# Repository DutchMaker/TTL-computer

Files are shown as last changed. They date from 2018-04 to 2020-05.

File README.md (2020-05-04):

# 74xx Computer

My attempt at building a computer from scratch with 74xxx logic chips.  

## Project Shelved!

I have abandoned this project, but only to reboot it with a different approach.  
Make sure to check **[The DM-02 Computer](https://github.com/DutchMaker/DM-02)** which is my second attempt at a computer from scratch!

## Status as of September 4th, 2019:

[**General architecture**](https://github.com/DutchMaker/TTL-computer/blob/master/Documentation/Architecture.pdf) has been worked out as high level schematic.  

Worked on **instruction set, micro code, module documentation & general notes** from time to time (see: [Documentation](https://github.com/DutchMaker/TTL-computer/tree/master/Documentation)). Only thing missing right now is some documentation on each of the modules. 

The entire computer has been built in [**Logisim**](https://github.com/DutchMaker/TTL-computer/tree/master/Documentation/Logisim) to verify that the way I had everything in mind is actually going to work.

I've built a [**microcode compiler**](https://github.com/DutchMaker/TTL-computer/tree/master/Code/Microcode) for the Controller's ROM image. This takes a source file which defines all the microcode and compiles it into a binary image that is loaded into the microcode ROM.

The 74xx Computer's **instruction set** has been implemented, its **[assembly language](https://github.com/DutchMaker/TTL-computer/blob/master/Documentation/74xx-Assembly-Language.md)** is fully documented and I've built an [**assembler**](https://github.com/DutchMaker/TTL-computer/tree/master/Code/Assembler) to convert assembly programs to machine code.

[**Circuit diagrams and PCBs**](https://github.com/DutchMaker/TTL-computer/tree/master/Circuits) have all been designed in KiCad and have been or are currently being produced:

- [x] Clock (*built and tested*)
- [x] Registers (*built and tested*)
- [x] ALU (*built and tested*)
- [x] Program Counter (*built and tested*)
- [x] Stack Pointer (*built and tested*)
- [x] Flags register (*built and tested*)
- [x] Memory (*built and tested*)
- [x] Memory Access Register (*built and tested*)
- [ ] Controller (*redesigned circuit to account for reset ciruitry - waiting for PCB production*)
- [x] Main Board ( *built and tested*)

## TODO's / Plans:

- Build the computer in real life (**IN PROGRESS**)
  - First revision is based on separate PCBs that are all connected together by one large main PCB.
  - If all works out, there may be a second revision will be one large PCB that contains all modules as one circuit.
- Write additional/updated documentation on all modules.

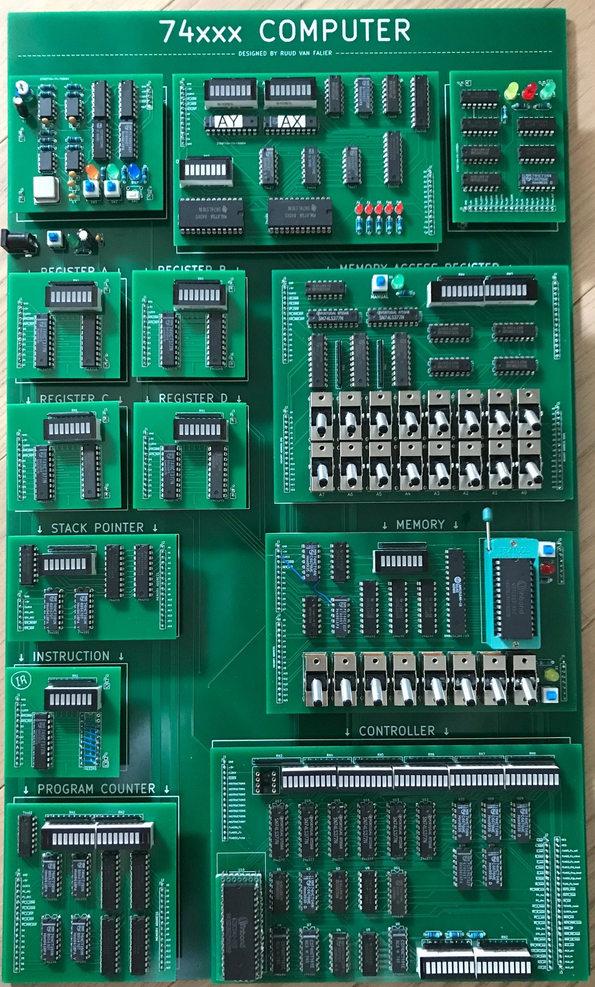
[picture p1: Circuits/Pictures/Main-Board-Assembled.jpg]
Assembled computer


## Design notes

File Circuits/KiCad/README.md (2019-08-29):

# KiCad projects

- Add `./Libraries/74xx-Computer-Symbols.lib` as global Symbol library to KiCad (Eeschema)
- Add `./Libraries` as global Footprint library to KiCad (Pcbnew)
- PCBs are initially autorouted using `./Libraries/freeRouting.jar` and traces are enhanced manually

### Known deviations/errors in current Schematic/PCB files

There are a number of deviations and errors that were found in schematic/PCB designs after PCB production. They are listed here if they were not fixed in the schematic/PCB design files.

- **ALU:** LED bar graph for AX (_BAR1_) and AY (_BAR2_) have swapped places on the PCB.
- **ALU:** Cn input needs to be inverted.
- This is added to the main board because ALU PCB was already produced and there were no available NOT gates available.
- **ALU:** Outer margin varies from other boards.
- **Flags Register:** U6 and U7 (74x74) ~PRE pins (4 and 10) are floating. They must be tied to +5V otherwise the chip does not function properly.
- **Memory & Memory Access Register:** The switches used for SW1 to SW8 briefly short out the circuit while switching. This reset the entire computer. Solved this by removing the connection to ground and adding 10k pull-down resistors between the data lines and ground.
- **Memory:** RAM should write when clock pulse is high. Otherwise manual input is difficult because that relies on single stepping the clock. Solved this by feeding the clock signal through U1 (74x04) before connecting it to U4A (74x32).
- **Main Board:** Current main board PCB design does not fit the current instruction register PCB - only the improvised one that I've built.
- **Controller:** U9 (74x74) ground pin is not connected. Also ~PRE pin (4) is floating and must be tied to +5V.
- **Controller & Memory**: Drill holes for ZIF socket are too narrow (need to be 1mm).
- **Main Board:** Forgot to add LED bar to display data bus contents.
- **Main Board:** Forgot to add one or more expansion ports.
- **Main Board:** Need pull-down resistors on the data bus
- **Controller**: There is an issue with powering up the controller: its initial state has all control lines enabled. This messes up the state of other modules.
  - Needs pull-down/up resistors on control lines for initial state of modules (reset state) - this is improvised on the main board now. We also must have a boot/reset procedure, something like: 
    - First all control line output is high impedance (this resets all modules because of the pull-down/up resistors that determine initial state). Will probably do this by cutting power to the controller during boot.
    - Then the controller is powered up and it needs to load microcode address 0
    - Then it can start processing instructions

### Suggested improvements

- Clock: Use a bigger push switch for single stepping
  - Add a *continue* option in order to continue execution after a HALT instruction.
- When all modules are built and tested, combine them into a single PCB.
  - I may decide to never do this and just start designing the next version of the CPU.
- Add decoupling caps (have only been added to main board now)
- Improve silk screen documentation
- Databus LEDs missing on Main Board
- Add hex decoders to registers / memory.
  - Add switch to disable output?
- ADC and SUBC instructions should take the carry flag into account
  - SUBC may be renamed to SUBB (borrow)

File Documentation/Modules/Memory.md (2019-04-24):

# Memory

_Work in progress..._

ROM/RAM	
Toggle switch to boot from ROM	
	$0000-$3FFF = ROM (16 kB)
	$4000-$FFFF = RAM (48 kB)
	
Switch ROM off	
	$0000-$FFFF = RAM (64 kB)
	
Stack	
	$FF00-$FFFF
	
If ROM boot is enabled:	
	Address bit 14 && 15 == 0 then use ROM
	Else use RAM

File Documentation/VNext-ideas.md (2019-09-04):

# Ideas for the next CPU to build:

- Improve microcode efficiency
- Replace 74x181 ALU with EPROM-based ALU (see: <https://github.com/DoctorWkt/CSCvon8/blob/master/Docs/CSCvon8_design.md>)
- Split clock cycle in 2 phases, one where output to bus starts, second where loading from the bus starts.
- Compatibility with 8085 architecture; opens the door to conversion from 8085 assembly to vNext assembly and even re-use of 8085 C compilers
- Maybe add 16-bit register and operations? or at least a transfer register (takes 16-bit and splits it into 8-bit)
- Support for interrupts
- Be able to peek at register contents with hexadecimal feedback
- Add CPU flags for sign/negative, parity, overflow
  - Store flags in 8-bit register
  - Allows bit (ALU) operations on flags
- One MOV instruction for all data transfer operations (add addressing modes so MOV can replace MVI, LDA, STA, LDA, etc)
- Store accumulator and flags register before a CALL instruction and restore it after RET instruction

## Improve microcode efficiency and allow for more flags

Current CPU uses 19 address lines for the microcode ROM and stores state of 48 control lines in 6 separate bytes.
Ideas for improvement:

- Use rom with 16 address lines and 16 bit words (M27C1024)
- Fit all control lines in one word (or 2?)
- First 2 t-states are hardwired and excluded from t-state bits. So we can have 16 t-state with 4-bits PLUS the 2 t-state required for the fetch cycle = 18 t-state max
- Encode control lines into that word
- Decode the control word in the CPU's controller
- OUT/IN will use memory address instead of register operation (= no control lines required)
- No flags in microcode, instead use hardwired logic connected to an 8-bit flags register
- Microcode rom addr will be `[instruction(8)][t-state(4)]` = 12-bit address

### Decrease word size (encode the control lines)

Operation type (2 bits)

- Data operation `00`
  - Word format: `[00][operand (4)][datafunction (1)][operand (4)][datafunction (1)][alufunctions (4)]` = 16 bits
- ALU `01`
  - 
- Other `10`
  - Word format: `[01]`

Data operands (4 bits per operand, 2 operands in one microcode instruction = 8 bits):

- None `0000`
- A `0001`
- B `0010`
- H (was D) `0011`
- L (was C) `0100`
- ALU `0101`
- Flags (treat as regular register - set/clear flag instructions use ALU operations) `0110`
- IR `0111`
- MAR_H `1000`
- MAR_L `1001`
- MEM `1010`
- PC_H `1011`
- PC_L `1100`
- STACK_H `1101`
- STACK_L `1110`
- (add 1 more GPR?)

Data functions (1 bit per operand, 2 per instruction = 2 bits):

- load `0`
- out `1`

ALU functions

- ALU_f0
- ALU_f1
- ALU_f2
- ALU_f3

Other functions (may take up to 6 bits):

- TSTATE_reset
- CLOCK_halt
- MAR_zp
- STK_inc
- STK_dec
- PC_inc
- PC_dec

Example control word:

- Memory out, A register load = `[operation][MEM][out][A][load]` = `[00][1001][1][0010][0]`

Important changes compared to v1:

- Flags are in one normal register
- Set/clear flag instructions is done with ALU operations
- ALU uses custom/simplified function table (4 bits)

### Flags

- Make it easy to identify flag operations in op-code
- eg. end opocode with flag bits
- 3 bits, allows for 5 flags (0 = no flag operation)
- 1 = Zero
			- 2 = Carry
		- 3 = Negative
		- 4 = Compare
		- 5 = Whatever
	
	- JN (jump in negative)	= `[10101][011]`	
		- 011 needs to be decoded to 00100
		- Execute instruction `[10101]` (= JMP) when decoded bit 3 == 1
		- Use one more bit (last) in instruction to identify if condition can be applied
		- Example `[10101]` = condition can be applied, `[10100]` is not
			So `[10100111]` is an unconditional 8 bit instruction while `[11001001]` is conditional and requires zero=1 to run

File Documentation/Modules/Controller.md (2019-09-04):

# Controller

This module is responsible for counting T-states and decoding instructions to the control lines.
It's the most complicated part of this computer as it requires several states to be tracked in order to perform its tasks.

The controller logic is based on microcode that is stored in a ROM.

## Module subsystems:

### Power-up

When the module is powered up, all the reset lines on the 8-bit registers (74273) are pulled low (active) in order to reset the registers. At the same time a 4 bit counter (74161) starts counting and when it reached `0010` the register reset lines are pulled up so the registers are enabled and the rest of the module's subsystems are enabled.

This prevents the control lines from outputting random states during power-up.

All control lines have pull-up/down resistors connected to them. They determine the default state of each of the control lines. They are set up in such way that all the modules that load data from the bus (Registers, Program Counter, MAR, etc.) have their `load` line enabled so they are loading empty data (the data bus is pulled low) during power-up.

### T-state counter
State machine that keeps track of instruction T-states. Instructions can have a maximum of 16 T-states so we use a 4 bit binary counter (74161).

### _Data byte_ counter
Instructions are translated to a maximum of 48 control lines and the state of these lines are stored in the control ROM. Because the ROM stores one byte (8 bits) per address, we need to read a byte from 6 sequential addresses to come up with the 48 bit word for the control lines.
The _data byte counter_ (74161 binary counter) result is used during composition of the current ROM memory address. We are using only 3 bits of this counter for this purpose.

### Registers

The 48 bit control word is stored in 8-bit registers (74273). The data byte counter determines which of the registers is used to store the current data byte. Register selection is done using a  3-to-1 multiplexer (74138). When transfer is complete, we have all the control bits ready to be used.

### Internal clock

The module has an internal clock running at relatively high speed used for the ROM bank and Load state counter and the shift registers. The Logisim circuit uses an internal clock at 8x the speed of the regular clock.

## Module inner workings

Let's take a look at the tasks that this module is performing:

1. Halt CPU execution.
2. Construct ROM memory address for bank 1 (see _Memory layout_).
3. Load ROM byte into current register.
4. Increase data byte counter.
5. Repeat from step 2 until bank 6 has been processed (6x8 control word bytes).
6. Resume CPU execution.

## Memory layout

### Memory addresses

The microcode (control line states) for each instruction is stored in 6 bytes in ROM.
The memory address at which this is stored is constructed using the following variables:

- Bank number (i.e. byte number, one bank for each of the 6 bytes).
  *3 bits*
- CPU flags state.
  *3 bits*
- Instruction OP-code.
  *8 bits*
- Instruction T-state.
  *5 bits*

This leads to an 19 bit address which is exactly what is supported by the 29C040 ROM we are using. 

The final memory address is laid out as such:

`[flags][instruction][t-state][bank]`
`[000][00000000][00000][000]`

Flags are ordered as such:

| Bit 2  | Bit 1 | Bit 0 |
| --- | ----- | ----- |
| `Fcmp` | `Fz`  | `Fc`  |

### Data layout

| | Bit 7 | Bit 6 | Bit 5 | Bit 4 | Bit 3 | Bit 2 | Bit 1 | Bit 0 |
| --- | --- | --- | --- | --- | --- | --- | --- | --- |
| **Bank 0** | | | `MAR_ZP` | `FLAGS_Fc_set` | `FLAGS_Fc_clear` | `FLAGS_Fc_load` | `FLAGS_Flt_load` | `FLAGS_Feq_load` |
| **Bank 1** | `FLAGS_Fgt_load` | `OUT2_in` | `OUT1_in` | `IN_out` | `TSTATE_reset` | `CLOCK_halt` | `MEM_out` | `MEM_RAM_load` |
| **Bank 2** | `MAR_STK_load` | `MAR_PC_load` | `MAR_HB_load` | `MAR_LB_load`  | `ALU_out` | `ALU_cn` | `ALU_m` | `ALU_s3` |
| **Bank 3** | `ALU_s2` | `ALU_s1` | `ALU_s0` | `ALU_B_in` | `ALU_A_in` | `STK_reset` | `STK_dec` | `STK_inc` |
| **Bank 4** | `PC_HB_out` | `PC_LB_out` | `PC_HB_load`  | `PC_LB_load` | `PC_dec` | `PC_inc` | `IR_load` | `FLAGS_load` |
| **Bank 5** | `D_load` | `D_out` | `C_load` | `C_out` | `B_load` | `B_out` | `A_load` | `A_out` |

## Microcode

The microcode compiler is used to define the contents of the microcode ROM.
*More documentation on this will follow...*

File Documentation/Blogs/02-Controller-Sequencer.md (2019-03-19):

# Sequencer / Instruction Decoder

This module is responsible for translating the current instruction to the control lines.
It's the most complicated part of this computer as it requires several states to be tracked in order to perform its tasks.

## Module subsystems:

### T-state counter
State machine that keeps track of instruction T-states. Instructions can have a maximum of 16 T-states so we use a 4 bit binary counter (74161).

### ROM bank counter
Instructions are translated to a maximum of 48 control lines and the state of these lines are stored in the control ROM. Because the ROM stores 8 bits per address, we need to read from 6 sequential addresses to come up with the 48 bit word for the control lines.
The _ROM bank counter_ (74161 binary counter) result is used during composition of the current ROM memory address. We are using only 3 of the counter bits for this purpose.

### Shift registers

The 48 bit control word is stored in serial-in/parallel-out (SIPO) 6 shift registers (74595). To transfer the bits from the ROM to the SIPO shift registers, we use one parallel-in/serial-out (PISO) shift register (74165).

When transfer is complete, we have all the control bits ready to be used and visualized.

### Load state counter

In order to load bits from ROM into the PISO/SIPO shift registers we need to keep track of a load state; after 8 bits are loaded, the ROM bank counter needs to advance and the next 8 bits must be loaded.

### Internal clock

The module has an internal clock running at relatively high speed (something like 8 MHz)  used for the ROM bank counter, SR loading state and the shift registers.

## Module inner workings

Let's take a look at the tasks that this module is performing:

1. Halt CPU execution.
2. Construct ROM memory address for bank 1 (see _Memory layout_).
3. Load ROM byte into PISO shift register.
4. Load PISO data into SIPO shift register.
5. Increase bank counter.
6. Repeat from step 2 until bank 6 has been processed (6x8 control word bytes).
7. Resume CPU execution.

## Memory layout

### Memory addresses

The microcode (control line states) for each instruction is stored in 6 bytes in ROM.
The memory address at which this is stored is constructed using the following variables:

- Bank number (i.e. byte number, one bank for each of the 6 bytes).
  *3 bits*
- CPU flags state.
  *5 bits*
- Instruction OP-code.
  *6 bits*
- Instruction T-state.
  *4 bits*

This leads to an 18 bit address. The ROM we are using (29C040) supports 19 bit addresses, so the last bit remains unused. 

The final memory address is laid out as such:

`[unused][flags][instruction][t-state][bank]`
`[0][00000][000000][0000][000]`

### Data layout

| | **Bit 7** | **Bit 6** | **Bit 5** | **Bit 4** | **Bit 3** | **Bit 2**  | **Bit 1**  | **Bit 0** |
| --- | --- | --- | --- | --- | --- | --- | --- | --- |
| **Bank 0** | `CLK_hlt` | `C_in` | `C_out` | `C_PC-in` | `D_in` | `D_out` | `D_PC-in`  | `A_in` |
| **Bank 1** | `A_out` | `B_in` | `B_out` | `IO_in` | `RAM_in`  | `MEM_out`  | `IN_out` | `OUT1_in` |
| **Bank 2** | `OUT2_in` | `PC_dec`  | `PC_inc`  | `PC_C-in` | `PC_D-in` | `MAR_C-in` | `MAR_D-in` | `MAR_PC-in` |
| **Bank 3** | `MAR_STK-in` | `ALU_in`  | `ALU_out` | `ALU_S0`  | `ALU_S1`  | `ALU_S2` | `ALU_S3` | `ALU_M` |
| **Bank 4** | `ALU_Cn` | `F_in` | `F_z` | `F_c` | `F_eq` | `F_lt` | `F_gt` | `SEQ_res` |
| **Bank 5** | | | | | | | `STK_dec`  | `STK_inc` |

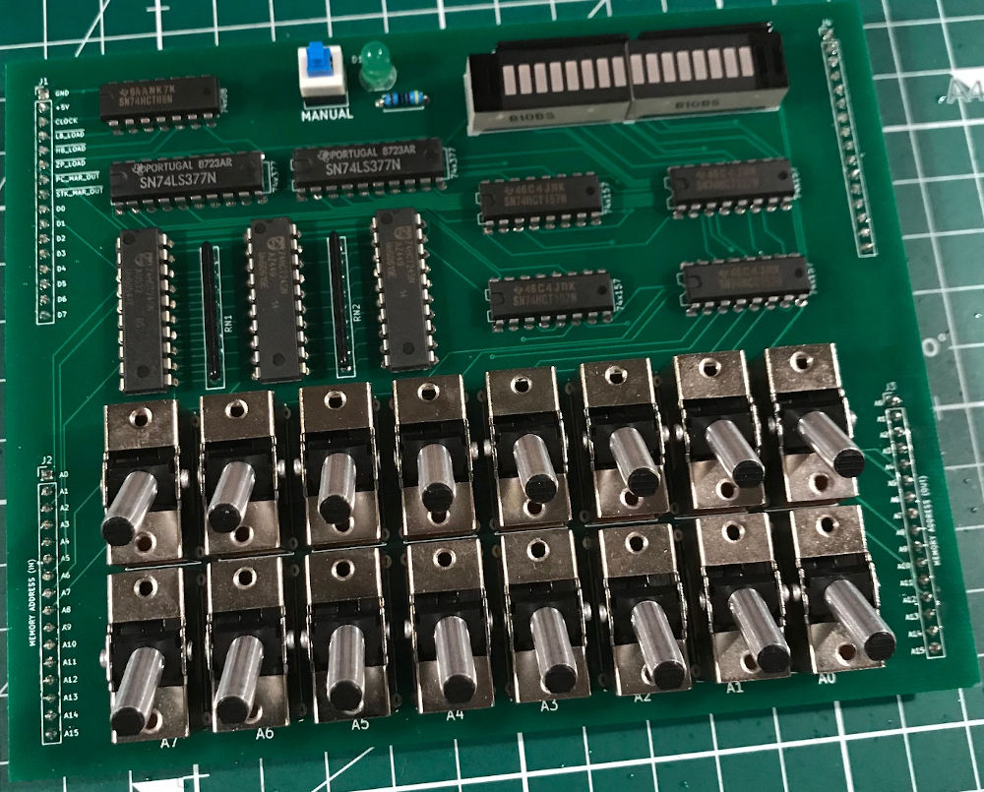
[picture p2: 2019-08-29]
Circuits/Pictures/Memory-Access-Register.jpg

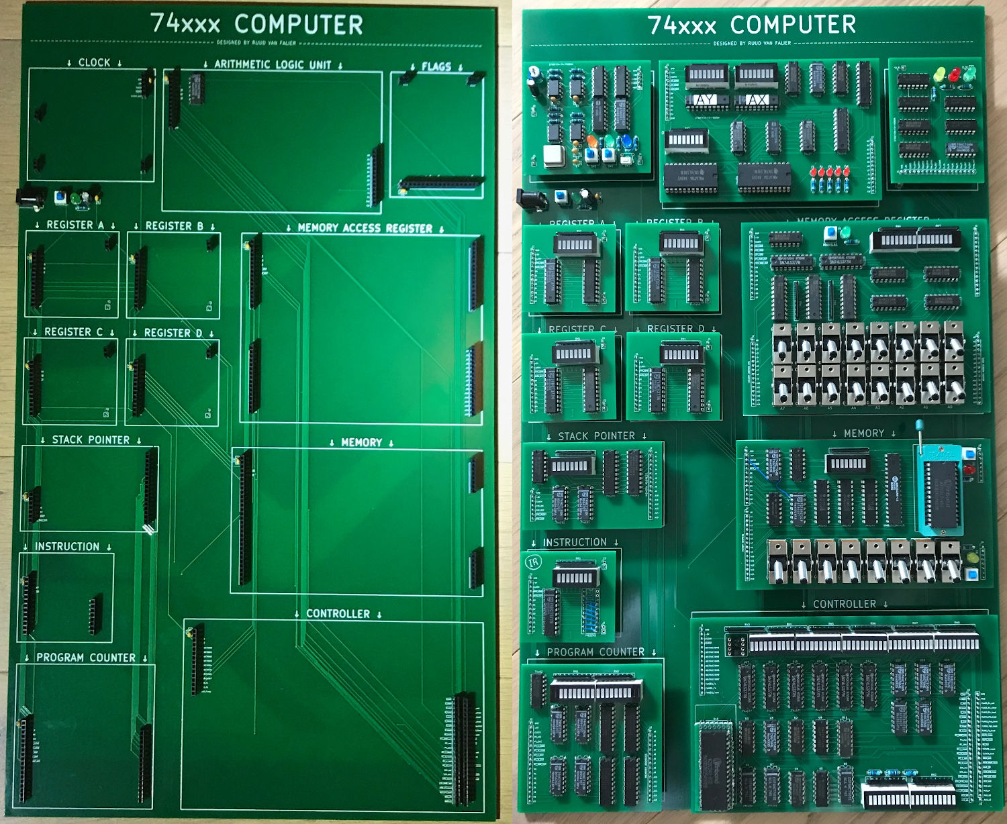
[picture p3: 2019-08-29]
Circuits/Pictures/Main-Board.jpg

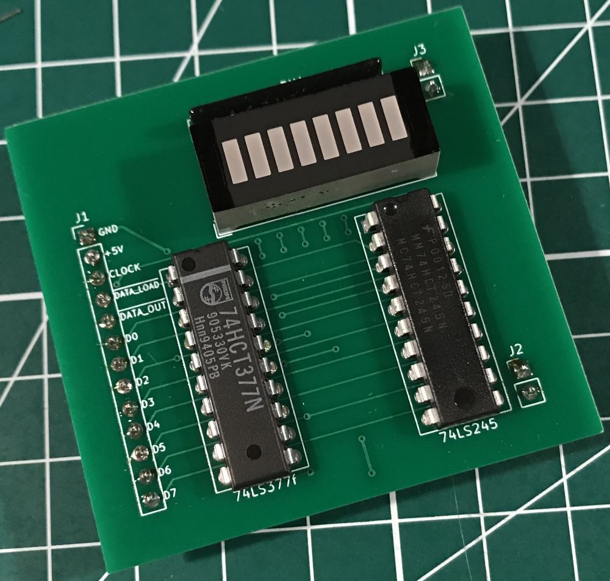
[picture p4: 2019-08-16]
Circuits/Pictures/Register.jpg

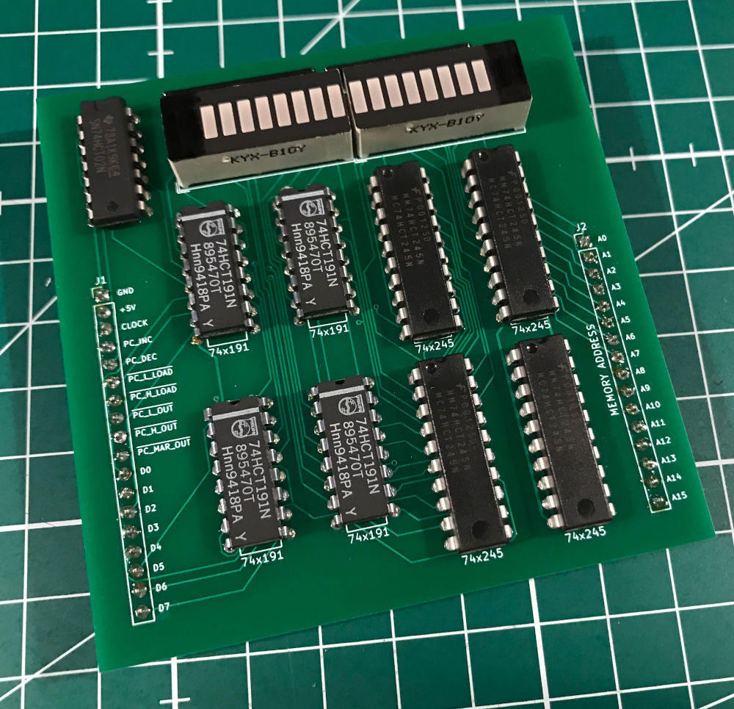
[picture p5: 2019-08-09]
Circuits/Pictures/Program-Counter.jpg

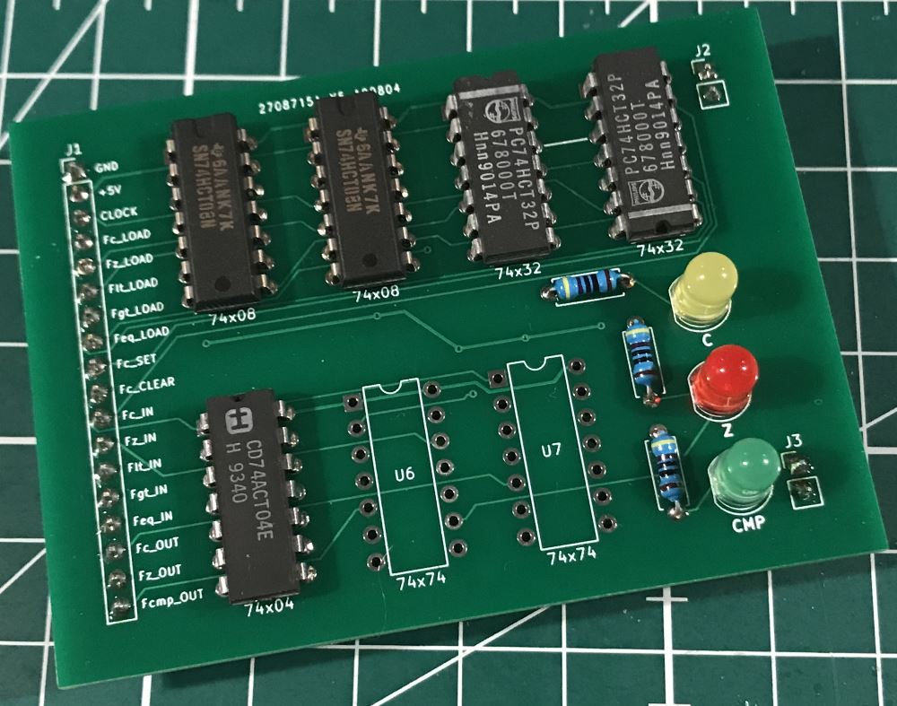
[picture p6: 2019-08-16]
Circuits/Pictures/Flags-Register.jpg

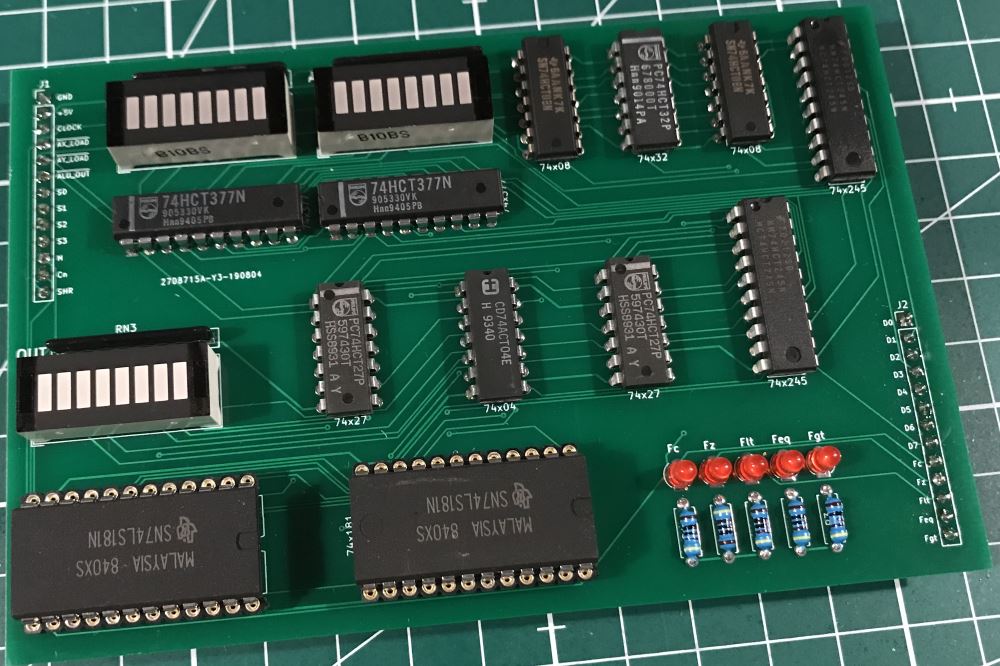
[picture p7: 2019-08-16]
Circuits/Pictures/ALU.jpg

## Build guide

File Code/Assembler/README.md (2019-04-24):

# 74xx Computer Assembler

This application is used to compile 74xx Computer Assembly files to 74xx Computer machine code.
It's a .NET Core application that is compiled for the Windows x64 platform, but can also be compiled for macOS or Linux.

## Usage

## Syntax

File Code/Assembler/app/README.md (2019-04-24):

# Build & Publish the .NET Core solution first!

Build & publish `\Code\Assembler\src\Assembler.sln` using Visual Studio before attempting to compile.

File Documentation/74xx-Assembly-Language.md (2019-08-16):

# 74xx Computer Assembly Language

This document is the complete reference to the 74xx Computer Assembly Language.

**Contents:**

- [Structure](#structure)
- [Registers](#registers)
- [Flags](#flags)
- [Memory](#memory)
- [Instructions](#instructions)

## Structure

The following code example demonstrates how to define **labels**, define and use **address variables** and **predefine ROM data**:

```
:data

	# :data label starts definition of hard-coded ROM data.
	# If defined, the :data label MUST be defined before :main.

	0x3000: 0xA0 0xB1 0xC2 0xD3;
	0x3010: 0x01 0x02 0x03 0x04
			0x05 0x06 0x07 0x08;	# Note the use of the ; at the end. This is required to end the block of data.
	0x3100: "Hello world!";			# You can define character strings like this.
	
:main

	# Program execution starts at the :main label.
	# This must be either the first label in the program,
	# or the first one after the :data label.
	
	MVI A 0xB1
	... more instructions here ...

	*i = 0x4000		# You can define address variables, which
	ST D *i 		# can be used in instructions that refer to an address.
	LD A *i
	
	LD B 0x45		# 8-bit addresses refer to zero page memory (256 bytes available).
					# This example refers to 0xFE45.
	                # See section on Memory Layout in this reference.

	CALL example	# Jump to subroutine (with the ability to return).

	JMP done

:example

	MOV B A
	... more instructions here ...
	
	RET				# Jump back to the caller address.
	
:done

	HALT
```

## Registers

| Register | Purpose |
| :--- | :--- |
| A, B | General purpose bi-directional registers. |
| C, D | Bi-directional registers that may be used for general purpose, but are also used for temporary address storage by some instructions. Address *low byte* is stored in register C, while the *high byte* is stored in D. |
| AX | Write-only register for the ALU (*accumulator*). |
| AY | Write-only register for the ALU (*operand*). |
| OUT1 | Write-only register used for output control. Can only be written to using the *OUT 1* instruction. |

## Flags

| Flag | Purpose |
| :--- | :--- |
| Fc | ALU operation resulted in a carry |
| Fz | ALU operation resulted in zero |
| Fcmp | Result of the last `CMP` operation |

## Memory

The 74xx Computer has two modes of operation:

**1. Boot from ROM**  
This enables 16kb of ROM which the program counter starts at.  
Running in this modes leaves 48k of addressable RAM.

**2. RAM only**  
In this mode there is no ROM at all, just 64k of RAM.  
There is currently no way of feeding in the program code, other than flipping switches and clocking it in manually.

The different modes results in two possible memory layouts.
Memory layout when running in **boot from ROM** mode:

| Offset | Purpose |
| :----- | :--- |
| 0x0000 | ROM |
| 0x4000 | RAM |
| 0xFE00 | Zero page memory |
| 0xFF00 | Stack space |

Memory layout when running in **RAM only** mode:

| Offset | Purpose |
| :----- | :--- |
| 0x0000 | RAM |
| 0xFE00 | Zero page memory |
| 0xFF00 | Stack space |

### Zero page addressing

Instructions LD, ST, LDR and STR all have a zero page based counterpart: LDZ, STZ, LDRZ, STRZ.  
For example: `LD A 0xFE35` may be replaced with `LDZ A 0x35` to save a few clock cycles.  

The assembler will automatically convert these instructions if zero page addressing was used.
For example: `LD A 0x35` is automatically replaced with `LDZ A 0x35` by the assembler.

Note that **not** all registers supported by LD (etc.) are also supported by their counterpart (LDZ, etc.)!

## Instructions

**Contents:**

- General purpose instructions:
  - [NOP](#NOP)
  - [HALT](#HALT)
  - [SC](#SC)
- Data transfer instructions:
  - [MOV](#MOV)
  - [MVI](#MVI)
  - [LD](#LD)
  - [ST](#ST)
  - [LDZ](#LDZ)
  - [STZ](#STZ)
  - [LDR](#LDR)
  - [STR](#STR)
  - [LDRZ](#LDRZ)
  - [STRZ](#STRZ)
  - [LDX](#LDX)
  - [STX](#STX)
  - [OUT](#OUT)
  - [PUSH](#PUSH)
  - [POP](#POP)
- Arithmetic instructions: 
  - [ADD](#ADD)
  - [ADC](#ADC)
  - [SUB](#SUB)
  - [SBC](#SBC)
  - [INC](#INC)
  - [DEC](#DEC)
- Logical instructions:
  - [AND](#AND)
  - [OR](#OR)
  - [XOR](#XOR)
  - [NOT](#NOT)
  - [SHL](#SHL)
  - [SHR](#SHR)
  - [CMP](#CMP)
- Branching instructions:
  - [JMP](#JMP)
  - [JMPC](#JMPC)
  - [CALL](#CALL)
  - [CALLC](#CALLC)
  - [RET](#RET)
  - [RETC](#RETC)

------
### General purpose instructions

#### NOP

| | Do nothing |
| :--- | :--- |
| Syntax: | NOP |
| Example: | `NOP` |
| Instruction data: | `opcode` (1 byte) |
| T-states: | 3 |
| Sets flags: | *none* |
| Notes: | *none* |

**Opcodes for NOP**

| Mnemonic | Opcode (8-bit binary) | Opcode (hex) |
| :--- | --- | --- |
| `NOP` | `00000000` | `0x00` |

------

#### HALT

| | Halt CPU execution |
| :--- | :--- |
| Syntax: | HALT |
| Example: | `HALT` |
| Instruction data: | `opcode` (1 byte)  |
| T-states: | 3 |
| Sets flags: | *none* |
| Notes: | *none* |

**Opcodes for HALT**

| Mnemonic | Opcode (8-bit binary) | Opcode (hex) |
| :--- | --- | --- |
| `HALT` | `00000001` | `0x01` |

------

#### SC

| | Set carry flag to *0* or *1* |
| :--- | :--- |
| Syntax: | SC `(0,1)` |
| Example: | `SC 0` |
| Instruction data: | `opcode` (1 byte) |
| T-states: | 4 |
| Sets flags: | `Fc` |
| Notes: | *none* |

**Opcodes for SC**

| Mnemonic | Opcode (8-bit binary) | Opcode (hex) |
| :--- | --- | --- |
| `SC 0` | `01101000` | `0x68` |
| `SC 1` | `01101001` | `0x69` |

------
### Data transfer instructions

#### MOV

| | Copy data from register *R2* into register *R1* |
| :--- | --- |
| Syntax: | MOV *R1*`(A,B,C,D,AX,AY)` *R2*`(A,B,C,D)` |
| Example: | `MOV AX B` |
| Instruction data: | `opcode` (1 byte) |
| T-states: | 4 |
| Sets flags: | *none* |
| Notes: | *none* |

**Opcodes for MOV**

| Mnemonic | Opcode (8-bit binary) | Opcode (hex) |
| :--- | --- | --- |
| `MOV B A`  | `00000010` | `0x02` |
| `MOV C A`  | `00000011` | `0x03` |
| `MOV D A`  | `00000100` | `0x04` |
| `MOV A B`  | `00000101` | `0x05` |
| `MOV C B`  | `00000110` | `0x06` |
| `MOV D B`  | `00000111` | `0x07` |
| `MOV A C`  | `00001000` | `0x08` |
| `MOV B C`  | `00001001` | `0x09` |
| `MOV D C`  | `00001010` | `0x0A` |
| `MOV A D`  | `00001011` | `0x0B` |
| `MOV B D`  | `00001100` | `0x0C` |
| `MOV C D`  | `00001101` | `0x0D` |
| `MOV AX A` | `01010101` | `0x55` |
| `MOV AX B` | `01010110` | `0x56` |
| `MOV AX C` | `01010111` | `0x57` |
| `MOV AX D` | `01011000` | `0x58` |
| `MOV AY A` | `01011001` | `0x59` |
| `MOV AY B` | `01011010` | `0x5A` |
| `MOV AY C` | `01011011` | `0x5B` |
| `MOV AY D` | `01011100` | `0x5C` |

------

#### MVI

| | Load immediate *data* value into register *R* |
| :--- | :--- |
| Syntax: | MVI *R*`(A,B,C,D,AX,AY)` *data*`(8-bit hex)`  |
| Example: | `MVI A 0xF3` |
| Instruction data: | `opcode` `data` (2 bytes) |
| T-states: | 5 |
| Sets flags: | *none* |
| Notes: | *none* |

**Opcodes for MVI**

| Mnemonic | Opcode (8-bit binary) | Opcode (hex) |
| :--- | --- | --- |
| `MVI A`  | `00001110` | `0x0E` |
| `MVI B`  | `00001111` | `0x0F` |
| `MVI C`  | `00010000` | `0x10` |
| `MVI D`  | `00010001` | `0x11` |
| `MVI AX` | `00111101` | `0x3D` |
| `MVI AY` | `00111110` | `0x3E` |

------

#### LD

| | Load data from memory *address* into register *R* |
| :--- | :--- |
| Syntax: | LD *R*`(A,B,C,D,AX,AY)` *address*`(16-bit hex)` |
| Example: | `LD A 0x40F3` |
| Instruction data: | `opcode` `address high byte` `address low byte` (3 bytes) |
| T-states: | 10 |
| Sets flags: | *none* |
| Notes: | Overrides data in registers `C` and `D`. |
| | Supports *address variables*. |
| | Supports zero page addressing, but **not on C & AY** register! |

**Opcodes for LD**

| Mnemonic | Opcode (8-bit binary) | Opcode (hex) |
| :--- | --- | --- |
| `LD A` | `00010010` | `0x12` |
| `LD B` | `00010011` | `0x13` |
| `LD C` | `01110001` | `0x71` |
| `LD D` | `01110010` | `0x72` |
| `LD AX`  | `01101010` | `0x6A` |
| `LD AY`  | `01101011` | `0x6B` |

------

#### ST

| | Store data from register *R* at memory *address* |
| :--- | :--- |
| Syntax: | ST *R*`(A,B)` *address*`(16-bit hex)` |
| Example: | `ST A 0x40F3` |
| Instruction data: | `opcode` `address high byte` `address low byte` (3 bytes) |
| T-states: | 10 |
| Sets flags: | *none* |
| Notes: | Overrides data in registers `C` and `D`. |
| | Supports *address variables*. |
| | Supports zero page addressing. |

**Opcodes for ST**

| Mnemonic | Opcode (8-bit binary) | Opcode (hex) |
| :--- | --- | --- |
| `ST A` | `00010110` | `0x16` |
| `ST B` | `00010111` | `0x17` |

------

#### LDZ

| | Load data from zero-page memory *address* into register *R* |
| :--- | :--- |
| Syntax: | LDZ *R*`(A,B,D,AX)` *address*`(8-bit hex)` |
| Example: | `LDZ A 0xF3` |
| Instruction data: | `opcode` `zero-page address byte` (2 bytes) |
| T-states: | 7 |
| Sets flags: | *none* |
| Notes: | Overrides data in register `C`. |
| | Supports *address variables*. |

**Opcodes for LDZ**

| Mnemonic | Opcode (8-bit binary) | Opcode (hex) |
| :--- | --- | --- |
| `LDZ A`  | `01110111` | `0x77` |
| `LDZ B`  | `01111000` | `0x78` |
| `LDZ C`  | `10000000` | `0x80` |
| `LDZ D`  | `01110100` | `0x74` |
| `LDZ AX` | `01110011` | `0x73` |
| `LDZ AY` | `10000001` | `0x81` |

------

#### STZ

| | Store data from register *R* at zero-page memory *address* |
| :--- | :--- |
| Syntax: | STZ *R*`(A,B)` *address*`(8-bit hex)` |
| Example: | `STZ A 0xF3` |
| Instruction data: | `opcode` `zero-page address byte` (2 bytes) |
| T-states: | 7 |
| Sets flags: | *none* |
| Notes: | Overrides data in register `C`. |
| | Supports *address variables*. |

**Opcodes for STZ**

| Mnemonic | Opcode (8-bit binary) | Opcode (hex) |
| :--- | --- | --- |
| `STZ A`  | `01100000` | `0x60` |
| `STZ B`  | `01111001` | `0x79` |

------

#### LDR

| | Load data from the memory address stored in register *C* (low byte) and *D* (high byte) into register *R* |
| :--- | :--- |
| Syntax: | LDR *R*`(A,B,C,D,AX,AY)` |
| Example: | `LDR A` |
| Instruction data: | `opcode` (1 byte) |
| T-states: | 6 |
| Sets flags: | *none* |
| Notes: | Registers `C` and `D` must contain a memory address. |

**Opcodes for LDR**

| Mnemonic | Opcode (8-bit binary) | Opcode (hex) |
| :--- | --- | --- |
| `LDR A`  | `01101101` | `0x6D` |
| `LDR B`  | `01101110` | `0x6E` |
| `LDR C`  | `01110101` | `0x75` |
| `LDR D`  | `01110110` | `0x76` |
| `LDR AX` | `10000010` | `0x82` |
| `LDR AY` | `10000011` | `0x83` |

------

#### STR

| | Store data from register *R* at the memory address stored in register *C* (low byte) and *D* (high byte) |
| :--- | :--- |
| Syntax: | STR *R*`(A,B)` |
| Example: | `STR A` |
| Instruction data: | `opcode` (1 byte) |
| T-states: | 6 |
| Sets flags: | *none* |
| Notes: | Registers `C` and `D` must contain a memory address. |

**Opcodes for STR**

| Mnemonic | Opcode (8-bit binary) | Opcode (hex) |
| :--- | --- | --- |
| `STR A`  | `01101111` | `0x6F` |
| `STR B`  | `01110000` | `0x70` |

------

#### LDRZ

| | Load data from the zero-page memory address stored in register *C* into register *R* |
| :--- | :--- |
| Syntax: | LDRZ *R*`(A,B,C,D,AX,AY)` |
| Example: | `LDRZ A` |
| Instruction data: | `opcode` (1 byte) |
| T-states: | 5 |
| Sets flags: | *none* |
| Notes: | Register `C` must contain a zero-page memory address. |

**Opcodes for LDRZ**

| Mnemonic  | Opcode (8-bit binary) | Opcode (hex) |
| :--- | --- | --- |
| `LDRZ A`  | `01111010` | `0x7A` |
| `LDRZ B`  | `01111011` | `0x7B` |
| `LDRZ C`  | `10000100` | `0x84` |
| `LDRZ D`  | `01111101` | `0x7D` |
| `LDRZ AX` | `01111100` | `0x7C` |
| `LDRZ AY` | `10000101` | `0x85` |

------

#### STRZ

| | Store data from register *R* at the zero-page memory address stored in register *C* |
| :--- | :--- |
| Syntax: | STRZ *R*`(A,B)` |
| Example: | `STR A` |
| Instruction data: | `opcode` (1 byte) |
| T-states: | 5 |
| Sets flags: | *none* |
| Notes: | Register `C` must contain a zero-page memory address. |

**Opcodes for STRZ**

| Mnemonic | Opcode (8-bit binary) | Opcode (hex) |
| :--- | --- | --- |
| `STRZ A` | `01111110` | `0x7E` |
| `STRZ B` | `01111111` | `0x7F` |

------

#### LDX

| | Load data from the memory address stored at *address* into register *R* (indirect load) |
| :--- | :--- |
| Syntax: | LDX *R*`(A,B,C,D)` *address*`(16-bit hex)` |
| Example: | `LDX A 0x40F3` |
| Instruction data: | 11 bytes *(see notes under Opcodes)* |
| T-states: | 40 |
| Sets flags: | Clears/sets the `Fc` and `Fz` flags |
| Notes: | See notes under Opcodes. |
| | Overrides data in registers `C` and `D`. |
| | Supports zero page addressing. |
| | Currently does **not** support *address variables*. |

**Opcodes for LDX**

The number of operations required by this instruction could not be performed within the limit of 16 t-states. Therefore this instruction has no opcodes of its own, but the assembler translates it into the following set of instructions:
```
LD AX {address}     # Load value at {address} into ALU register AX
MVI AY 0x00         # Load value 0x00 into ALU register AY
LD C {address + 1}  # Load value at {address+1} into register C
ADD D               # Load the value of AX (AX + 0x00 == AX) into register D
LDR {R}             # Load the value from the memory address stored
                    #   in register C and D into register {R}.
```

------

#### STX

| | Store data from register *R* at the memory address stored at *address* into  (indirect store) |
| :--- | :--- |
| Syntax: | STX *R*`(A,B)` *address*`(16-bit hex)` |
| Example: | `STX A 0x40F3` |
| Instruction data: | 11 bytes ((see notes under Opcodes)* |
| T-states: | 40 |
| Sets flags: | Clears/sets the `Fc` and `Fz` flags |
| Notes: | See notes under Opcodes. |
| | Overrides data in registers `C` and `D`. |
| | Supports zero page addressing. |
| | Currently does **not** support *address variables*. |

**Opcodes for STX**

The number of operations required by this instruction could not be performed within the limit of 16 t-states. Therefore this instruction has no opcodes of its own, but the assembler translates it into the following set of instructions:
```
LD AX {address}     # Load value at {address} into ALU register AX
MVI AY 0x00         # Load value 0x00 into ALU register AY
LD C {address + 1}  # Load value at {address+1} into register C
ADD D               # Load the value of AX (AX + 0x00 == AX) into register D
STR {R}             # Store the value of register {R} at 
                    #   the memory address stored in register C and D.
```

------

#### OUT

| | Send data from register *R* to output *O* |
| :--- | :--- |
| Syntax: | OUT *O*`(1,2)` *R*`(A,B,C,D)` |
| Example: | `OUT 1 A` |
| Instruction data: | `opcode` (1 byte) |
| T-states: | 4 |
| Sets flags: | *none* |
| Notes: | Currently only output 1 is implemented (TTY) |

**Opcodes for OUT**

| Mnemonic  | Opcode (8-bit binary) | Opcode (hex) |
| :--- | --- | --- |
| `OUT 1 A` | `01001101` | `0x4D` |
| `OUT 1 B` | `01001110` | `0x4E` |
| `OUT 1 C` | `01001111` | `0x4F` |
| `OUT 1 D` | `01010000` | `0x50` |
| `OUT 2 A` | `01010001` | `0x51` |
| `OUT 2 B` | `01010010` | `0x52` |
| `OUT 2 C` | `01010011` | `0x53` |
| `OUT 2 D` | `01010100` | `0x54` |

------

#### PUSH

| | Push data from register *R* on to the stack  |
| :--- | :--- |
| Syntax: | PUSH *R*`(A,B,C,D)` |
| Example: | `PUSH A` |
| Instruction data: | `opcode` (1 byte) |
| T-states: | 5 |
| Sets flags: | *none* |
| Notes: | *none* |

**Opcodes for PUSH**

| Mnemonic  | Opcode (8-bit binary) | Opcode (hex) |
| :--- | --- | --- |
| `PUSH A`  | `10010100` | `0x94` |
| `PUSH B`  | `10010101` | `0x95` |
| `PUSH C`  | `10010110` | `0x96` |
| `PUSH D`  | `10010111` | `0x97` |

------

#### POP

| | Pop data from the stack to register *R* |
| :--- | :--- |
| Syntax: | POP *R*`(A,B,C,D,AX,AY)` |
| Example: | `POP A` |
| Instruction data: | `opcode` (1 byte) |
| T-states: | 6 |
| Sets flags: | *none* |
| Notes: | *none* |

**Opcodes for POP**

| Mnemonic  | Opcode (8-bit binary) | Opcode (hex) |
| :--- | --- | --- |
| `POP A` | `10011001` | `0x98` |
| `POP B` | `10011010` | `0x99` |
| `POP C` | `10011011` | `0x9A` |
| `POP D` | `10011100` | `0x9B` |
| `POP AX`  | `10011101` | `0x9C` |
| `POP AY`  | `10011110` | `0x9D` |

------
### Arithmetic instructions

#### ADD

| | Perform ALU operation `AX + AY` and store result in *R* |
| :--- | :--- |
| Syntax: | ADD *R*`(A,B,C,D)` |
| Example: | `ADD A` |
| Instruction data: | `opcode` (1 byte) |
| T-states: | 5 |
| Sets flags: | Clears the `Fc` flag before the operation, then loads the `Fc` and `Fz` flag from ALU after the operation. |
| Notes: | *none* |

**Opcodes for ADD**

| Mnemonic | Opcode (8-bit binary) | Opcode (hex) |
| :--- | --- | --- |
| `ADD A`  | `00011010` | `0x1A` |
| `ADD B`  | `01100001` | `0x61` |
| `ADD C`  | `00011011` | `0x1B` |
| `ADD D`  | `00011100` | `0x1C` |

------

#### ADC

| | Perform ALU operation `AX + AY + Fc` and store result in *R* |
| :--- | :--- |
| Syntax: | ADC *R*`(A,B,C,D)` |
| Example: | `ADC A` |
| Instruction data: | `opcode` (1 byte) |
| T-states: | 5 |
| Sets flags: | Loads the `Fc` and `Fz` flag from ALU after the operation. |
| Notes: | *none* |

**Opcodes for ADC**

| Mnemonic | Opcode (8-bit binary) | Opcode (hex) |
| :--- | --- | --- |
| `ADC A`  | `00011101` | `0x1D` |
| `ADC B`  | `01100010` | `0x62` |
| `ADC C`  | `00011110` | `0x1E` |
| `ADC D`  | `00011111` | `0x1F` |

------

#### SUB

| | Perform ALU operation `AX - AY` and store result in *R* |
| :--- | :--- |
| Syntax: | SUB *R*`(A,B,C,D)` |
| Example: | `SUB A` |
| Instruction data: | `opcode` (1 byte) |
| T-states: | 6 |
| Sets flags: | Set the `Fc` flag before the operation, then loads the `Fc` and `Fz` flag from ALU after the operation. |
| Notes: | `Fc` flag is set as long as result is positive |

**Opcodes for SUB**

| Mnemonic | Opcode (8-bit binary) | Opcode (hex) |
| :--- | --- | --- |
| `SUB A`  | `00100000` | `0x20` |
| `SUB B`  | `01100011` | `0x63` |
| `SUB C`  | `00100001` | `0x21` |
| `SUB D`  | `00100010` | `0x22` |

------

#### SBC

| | Perform ALU operation `AX - AY - Fc` and store result in *R* |
| :--- | :--- |
| Syntax: | SBC *R*`(A,B,C,D)` |
| Example: | `SBC A` |
| Instruction data: | `opcode` (1 byte) |
| T-states: | 5 |
| Sets flags: | Loads the `Fc` and `Fz` flag from ALU after the operation. |
| Notes: | *none* |

**Opcodes for SBC**

| Mnemonic | Opcode (8-bit binary) | Opcode (hex) |
| :--- | --- | --- |
| `SBC A`  | `00100011` | `0x23` |
| `SBC B`  | `01100100` | `0x64` |
| `SBC C`  | `00100100` | `0x24` |
| `SBC D`  | `00100101` | `0x25` |

------

#### INC

| | Perform ALU operation `AX + 1` and store result in *R* |
| :--- | :--- |
| Syntax: | INC *R*`(A,B,C,D)` |
| Example: | `INC A` |
| Instruction data: | `opcode` (1 byte) |
| T-states: | 6 |
| Sets flags: | Set the `Fc` flag before the operation, then loads the `Fc` and `Fz` flag from ALU after the operation. |
| Notes: | *none* |

**Opcodes for INC**

| Mnemonic | Opcode (8-bit binary) | Opcode (hex) |
| :--- | --- | --- |
| `INC A`  | `00110100` | `0x34` |
| `INC B`  | `00110101` | `0x35` |
| `INC C`  | `00110110` | `0x36` |
| `INC D`  | `00110111` | `0x37` |

------

#### DEC

| | Perform ALU operation `AX - 1` and store result in *R* |
| :--- | :--- |
| Syntax: | DEC *R*`(A,B,C,D)` |
| Example: | `DEC A` |
| Instruction data: | `opcode` (1 byte) |
| T-states: | 5 |
| Sets flags: | Clears the `Fc` flag before the operation, then loads the `Fc` and `Fz` flag from ALU after the operation. |
| Notes: | `Fc` flag is set as long as result is positive |

**Opcodes for DEC**

| Mnemonic | Opcode (8-bit binary) | Opcode (hex) |
| :--- | --- | --- |
| `DEC A`  | `00111000` | `0x38` |
| `DEC B`  | `00111001` | `0x39` |
| `DEC C`  | `00111010` | `0x3A` |
| `DEC D`  | `00111011` | `0x3B` |

------
### Logical instructions

#### AND

| | Perform ALU operation `AX & AY` and store result in *R* |
| :--- | :--- |
| Syntax: | AND *R*`(A,B,C,D)` |
| Example: | `AND A` |
| Instruction data: | `opcode` (1 byte) |
| T-states: | 4 |
| Sets flags: | *none* |
| Notes: | *none* |

**Opcodes for AND**

| Mnemonic | Opcode (8-bit binary) | Opcode (hex) |
| :--- | --- | --- |
| `AND A`  | `00100110` | `0x26` |
| `AND B`  | `01100101` | `0x65` |
| `AND C`  | `00100111` | `0x27` |
| `AND D`  | `00101000` | `0x28` |

------

#### OR

| | Perform ALU operation `AX or AY` and store result in *R* |
| :--- | :--- |
| Syntax: | OR *R*`(A,B,C,D)` |
| Example: | `OR A` |
| Instruction data: | `opcode` (1 byte) |
| T-states: | 4 |
| Sets flags: | Clears the `Fc` flag before the operation. |
| Notes: | *none* |

**Opcodes for OR**

| Mnemonic | Opcode (8-bit binary) | Opcode (hex) |
| :--- | --- | --- |
| `OR A` | `00101001` | `0x29` |
| `OR B` | `01100110` | `0x66` |
| `OR C` | `00101010` | `0x2A` |
| `OR D` | `00101011` | `0x2B` |

------

#### XOR

| | Perform ALU operation `AX xor AY` (exclusive OR) and store result in *R* |
| :--- | :--- |
| Syntax: | XOR *R*`(A,B,C,D)` |
| Example: | `XOR A` |
| Instruction data: | `opcode` (1 byte) |
| T-states: | 4 |
| Sets flags: | Clears the `Fc` flag before the operation. |
| Notes: | *none* |

**Opcodes for XOR**

| Mnemonic | Opcode (8-bit binary) | Opcode (hex) |
| :--- | --- | --- |
| `XOR A`  | `00101100` | `0x2C` |
| `XOR B`  | `00101101` | `0x2D` |
| `XOR C`  | `00101110` | `0x2E` |
| `XOR D`  | `00101111` | `0x2F` |

------

#### NOT

| | Perform ALU operation `!AX` (inverse) and store result in *R* |
| :--- | :--- |
| Syntax: | NOT *R*`(A,B,C,D)` |
| Example: | `NOT A` |
| Instruction data: | `opcode` (1 byte) |
| T-states: | 4 |
| Sets flags: | *none* |
| Notes: | *none* |

**Opcodes for NOT**

| Mnemonic | Opcode (8-bit binary) | Opcode (hex) |
| :--- | --- | --- |
| `NOT A`  | `00110000` | `0x30` |
| `NOT B`  | `00110001` | `0x31` |
| `NOT C`  | `00110010` | `0x32` |
| `NOT D`  | `00110011` | `0x33` |

------

#### SHL

| | Perform ALU operation `AX * 2` (shift bits to the left) and store result in *R* |
| :--- | :--- |
| Syntax: | SHL *R*`(A,B,C,D)` |
| Example: | `SHL A` |
| Instruction data: | `opcode` (1 byte) |
| T-states: | 4 |
| Sets flags: | Clears the `Fc` flag before the operation. |
| Notes: | *none* |

**Opcodes for SHL**

| Mnemonic | Opcode (8-bit binary) | Opcode (hex) |
| :--- | --- | --- |
| `SHL A`  | `00010100` | `0x14` |
| `SHL B`  | `00010101` | `0x15` |
| `SHL C`  | `00011000` | `0x18` |
| `SHL D`  | `00011001` | `0x19` |

------

#### SHR

| | Perform ALU operation `AX / 2` (shift bits to the right) and store result in *R* |
| :--- | :--- |
| Syntax: | SHR *R*`(A,B,C,D)` |
| Example: | `SHR A` |
| Instruction data: | `opcode` (1 byte) |
| T-states: | 4 |
| Sets flags: | Loads the `Fc` and `Fz` flag from ALU after the operation. |
| Notes: | *none* |

**Opcodes for SHR**

| Mnemonic | Opcode (8-bit binary) | Opcode (hex) |
| :--- | --- | --- |
| `SHR A`  | `01011101` | `0x5D` |
| `SHR B`  | `01011110` | `0x5E` |
| `SHR C`  | `01011111` | `0x5F` |
| `SHR D`  | `01100111` | `0x67` |

------

#### CMP

| | Perform comparison operation on `AX` and `AY` |
| :--- | :--- |
| Syntax: | CMP *F*`(EQ,LT,GT)` |
| Example: | `CMP EQ` |
| Instruction data: | `opcode` (1 byte) |
| T-states: | 4 (`EQ` / `GT`) or 5 (`LT`) |
| Sets flags: | Clears or sets the `Fc` flag before the operation, then stores the result of the comparison as the  `Fcmp` flag. |
| Notes: | `CMP EQ` performs `AX == AY` comparison |
| | `CMP LT` performs `AX < AY` comparison |
| | `CMP GT` performs `AX > AY` comparison |

**Opcodes for CMP**

| Mnemonic | Opcode (8-bit binary) | Opcode (hex) |
| :--- | --- | --- |
| `CMP EQ` | `00111100` | `0x3C` |
| `CMP LT` | `10010010` | `0x92` |
| `CMP GT` | `10010011` | `0x93` |

------
### Branching instructions

#### JMP

| | Perform an unconditional jump |
| :--- | :--- |
| Syntax: | JMP *label* |
| Example: | `JMP target` |
| Instruction data: | `opcode` `target address high byte` `target address low byte` (3 bytes) |
| T-states: | 9 |
| Sets flags: | *none* |
| Notes: | Overrides data in registers `C` and `D` |

**Opcodes for JMP**

| Mnemonic | Opcode (8-bit binary) | Opcode (hex) |
| :--- | --- | --- |
| `JMP` | `00111111` | `0x3F` |

------

#### JMPC

| | Perform a conditional jump |
| :--- | :--- |
| Syntax: | JMPC *condition*`(Z,NZ,C,NC,CMP,NCMP)` *label* |
| Example: | `JMPC NC target` |
| Instruction data: | `opcode` `target address high byte` `target address low byte` (3 bytes) |
| T-states: | 9 |
| Sets flags: | *none* |
| Notes: | Overrides data in registers `C` and `D` |
| Conditions: | **Z**: `Fz == 1` |
| | **NZ**: `Fz == 0` |
| | **C**: `Fc == 1` |
| | **NC**: `Fc == 0` |
| | **CMP**: `Fcmp == 1` |
| | **NCMP**: `Fcmp == 0` |

**Opcodes for JMPC**

| Mnemonic | Opcode (8-bit binary) | Opcode (hex) |
| :--- | --- | --- |
| `JMPC Z` | `01000000` | `0x40` |
| `JMPC NZ` | `01000001` | `0x41` |
| `JMPC C` | `01000010` | `0x42` |
| `JMPC NC` | `01000011` | `0x43` |
| `JMPC CMP`  | `01000100` | `0x44` |
| `JMPC NCMP` | `01000101` | `0x45` |

------

#### CALL

| | Perform an unconditional jump with the ability to return |
| :--- | :--- |
| Syntax: | CALL *label* |
| Example: | `CALL target` |
| Instruction data: | `opcode` `target address high byte` `target address low byte` (3 bytes) |
| T-states: | 14 |
| Sets flags: | *none* |
| Notes: | Overrides data in registers `C` and `D` |

**Opcodes for CALL**

| Mnemonic | Opcode (8-bit binary) | Opcode (hex) |
| :--- | --- | --- |
| `CALL` | `01000111` | `0x47` |

------

#### CALLC

| | Perform a conditional jump with the ability to return |
| :--- | :--- |
| Syntax: | CALLC *condition*`(Z,NZ,C,NC,CMP,NCMP)` *label* |
| Example: | `CALLC NC target` |
| Instruction data: | `opcode` `target address high byte` `target address low byte` (3 bytes) |
| T-states: | 14 |
| Sets flags: | *none* |
| Notes: | Overrides data in registers `C` and `D` |
| Conditions: | **Z**: `Fz == 1` |
| | **NZ**: `Fz == 0` |
| | **C**: `Fc == 1` |
| | **NC**: `Fc == 0` |
| | **CMP**: `Fcmp == 1` |
| | **NCMP**: `Fcmp == 0` |

**Opcodes for CALLC**

| Mnemonic | Opcode (8-bit binary) | Opcode (hex) |
| :--- | --- | --- |
| `CALLC Z` | `10000110` | `0x86` |
| `CALLC NZ` | `10000111` | `0x87` |
| `CALLC C` | `10001000` | `0x88` |
| `CALLC NC` | `10001001` | `0x89` |
| `CALLC CMP`  | `10001010` | `0x8A` |
| `CALLC NCMP` | `10001011` | `0x8B` |

------

#### RET

| | Perform an unconditional jump back to the program location of the last CALL or CALLC instruction |
| :--- | :--- |
| Syntax: | RET |
| Example: | `RET` |
| Instruction data: | `opcode` (1 byte) |
| T-states: | 10 |
| Sets flags: | *none* |
| Notes: | Overrides data in registers `C` and `D` |

**Opcodes for RET**

| Mnemonic | Opcode (8-bit binary) | Opcode (hex) |
| :--- | --- | --- |
| `RET` | `01001000` | `0x48` |

------

#### RETC

| | Perform a conditional jump back to the program location of the last CALL or CALLC instruction |
| :--- | :--- |
| Syntax: | RETC *condition*`(Z,NZ,C,NC,CMP,NCMP)` |
| Example: | `RETC NC` |
| Instruction data: | `opcode` (1 byte) |
| T-states: | 10 |
| Sets flags: | *none* |
| Notes: | Overrides data in registers `C` and `D` |
| Conditions: | **Z**: `Fz == 1` |
| | **NZ**: `Fz == 0` |
| | **C**: `Fc == 1` |
| | **NC**: `Fc == 0` |
| | **CMP**: `Fcmp == 1` |
| | **NCMP**: `Fcmp == 0` |

**Opcodes for RETC**

| Mnemonic | Opcode (8-bit binary) | Opcode (hex) |
| :--- | --- | --- |
| `RETC Z` | `10001100` | `0x8C` |
| `RETC NZ` | `10001101` | `0x8D` |
| `RETC C` | `10001110` | `0x8E` |
| `RETC NC` | `10001111` | `0x8F` |
| `RETC CMP`  | `10010000` | `0x90` |
| `RETC NCMP` | `10010001` | `0x91` |

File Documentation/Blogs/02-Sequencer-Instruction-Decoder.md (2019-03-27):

# Sequencer / Instruction Decoder

This module is responsible for translating the current instruction to the control lines.
It's the most complicated part of this computer as it requires several states to be tracked in order to perform its tasks.

## Module subsystems:

### T-state counter
State machine that keeps track of instruction T-states. Instructions can have a maximum of 16 T-states so we use a 4 bit binary counter (74161).

### _Data byte_ counter
Instructions are translated to a maximum of 48 control lines and the state of these lines are stored in the control ROM. Because the ROM stores one byte (8 bits) per address, we need to read a byte from 6 sequential addresses to come up with the 48 bit word for the control lines.
The _data byte counter_ (74161 binary counter) result is used during composition of the current ROM memory address. We are using only 3 bits of this counter for this purpose.

### Shift registers

The 48 bit control word is stored in serial-in/parallel-out (SIPO) 6 shift registers (74595). To transfer the bits from the ROM to the SIPO shift registers, we use one parallel-in/serial-out (PISO) shift register (74165).

When transfer is complete, we have all the control bits ready to be used and visualized.

### _Data bit_ counter

In order to load bits from ROM into the PISO/SIPO shift registers we need to keep track of a load state (i.e. which data bit is being loaded); after 8 bits are loaded, the ROM bank counter needs to advance and the next 8 bits must be loaded.

### Internal clock

The module has an internal clock running at relatively high speed used for the ROM bank and Load state counter and the shift registers. The Logisim circuit uses an internal clock at 64x the speed of the regular clock.

## Module inner workings

Let's take a look at the tasks that this module is performing:

1. Halt CPU execution.
2. Construct ROM memory address for bank 1 (see _Memory layout_).
3. Load ROM byte into PISO shift register.
4. Load PISO data into SIPO shift register.
5. Increase data byte counter.
6. Repeat from step 2 until bank 6 has been processed (6x8 control word bytes).
7. Resume CPU execution.

## Memory layout

### Memory addresses

The microcode (control line states) for each instruction is stored in 6 bytes in ROM.
The memory address at which this is stored is constructed using the following variables:

- Bank number (i.e. byte number, one bank for each of the 6 bytes).
  *3 bits*
- CPU flags state.
  *5 bits*
- Instruction OP-code.
  *7 bits*
- Instruction T-state.
  *4 bits*

This leads to an 19 bit address which is exactly what is supported by the 29C040 ROM we are using. 

The final memory address is laid out as such:

`[flags][instruction][t-state][bank]`
`[00000][0000000][0000][000]`

Flags are ordered as such:

| Bit 4 | Bit 3 | Bit 2 | Bit 1 | Bit 0 |
| ----- | ----- | ----- | ----- | ----- |
| `Fgt` | `Feq` | `Flt` | `Fz`  | `Fc`  |

### Data layout

| | **Bit 7** | **Bit 6** | **Bit 5** | **Bit 4** | **Bit 3** | **Bit 2**  | **Bit 1**  | **Bit 0** |
| --- | --- | --- | --- | --- | --- | --- | --- | --- |
| **Bank 0** | `CLK_hlt` | `C_in` | `C_out` | `C_PC-in` | `D_in` | `D_out` | `D_PC-in`  | `A_in` |
| **Bank 1** | `A_out` | `B_in` | `B_out` | `IO_in` | `RAM_in`  | `MEM_out`  | `IN_out` | `OUT1_in` |
| **Bank 2** | `OUT2_in` | `PC_dec`  | `PC_inc`  | `PC_C-in` | `PC_D-in` | `MAR_C-in` | `MAR_D-in` | `MAR_PC-in` |
| **Bank 3** | `MAR_STK-in` | `ALU_in`  | `ALU_out` | `ALU_S0`  | `ALU_S1`  | `ALU_S2` | `ALU_S3` | `ALU_M` |
| **Bank 4** | `ALU_Cn` | `F_in` | `F_z` | `F_c` | `F_eq` | `F_lt` | `F_gt` | `SEQ_res` |
| **Bank 5** | | | | | | | `STK_dec`  | `STK_inc` |

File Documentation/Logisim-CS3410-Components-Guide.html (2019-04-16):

# CS 3410 Components Library Guide

The "CS3410 Components" library will only appear if you are using the most recent version of Logisim, downloaded from the course website. Please ensure that you are using the correct version. If so, you should have a folder in your sidebar containing the following components:

When loading the library in Logisim, use class 'edu.cornell.cs316.Components'

### Register File.

A 32-bit wide by 32-registers deep register file. Register $0 is hard-wired to zero at all times, and writes to $0 are ignored. You can rely on register $0 always containing 0, and do not need to test that its value does not change. Inputs rA and rB are used to select register values to output on the A and B outputs. When the clock is triggered, if WE is high, the data value at input W is stored in register rW. The register file can be configured to use rising clock edges as trigger (the default), falling edge, or to be level sensitive.

register file

### MIPS Program ROM.

A 32-bit wide byte-addressed ROM, with built-in MIPS assembler. Use the attributes panel to load a MIPS assembly file into the ROM. The PC input specifies the address of the current instruction, and must be a multiple of 4. The output is the 32-bit machine code instruction at the PC address, or an error if the PC is invalid. Reading addresses outside the range of code supplied by the assembly file will cause the ROM to output zero, which happens to encode a no-op in MIPS. The assembly language is in the format described below. When we say that the instruction ROM is byte-addressed memory, we mean that the instruction ROM takes an address A as input, advances A bytes into its memory (remember, 1 byte = 8 bits), and outputs the 32-bit instruction that starts at the resulting position. 32 bits is 4 bytes, which is why the PC normally increments by 4 every cycle: it's simply going to the next instruction.

rom

### MIPS ALU.

Computes a result as follows. You do not need to test the provided ALU, and can assume it will work exactly as specified.

Op | name | C
000x | shift left | C = B << Sa;
001x | add | C = A + B
0100 | shift right logical | C = B >>> Sa
0101 | shift right arithmetic | C = B >> Sa
011x | subtract | C = A - B
1000 | and | C = A & B
1010 | or | C = A | B
1100 | xor | C = A ^ B
1110 | nor | C = ~(A | B)
1001 | eq | C = (A == B) ? 000...0001 : 000...0000
1011 | ne | C = (A != B) ? 000...0001 : 000...0000
1101 | gtz | C = (A > 0) ? 000...0001 : 000...0000
1111 | lez | C = (A ≤ 0) ? 000...0001 : 000...0000

alu

### Incrementer.

An adjustable-width incrementer. Takes its input A on the left and outputs A+1 on the right. You must use this increment for your Program Counter (PC); you cannot build your own adder to increment the PC. Also, only ONE incrementer is allowed.

incrementer

### LCD Video.

If WE is high on the rising edge of CLK, writes a pixel on the LCD screen at the location given by the 7-bit unsigned X and Y coordinates. The pixel color is specified by 16-bit RGB input (in 5-5-5 format). The RST input resets the LCD screen. With some cleverness, you can redirect memory writes to this device to let your program draw on the LCD screen. Logisim also comes with some interesting input and output devices which can be used similarly.

lcd video

### RAM.

#### Inputs and Outputs

- A is the word-address. Each line in the RAM component is a word (four bytes) in memory, and has a unique address. As in the example figure to the right, A = 0x00002 refers to slot 00002 in the RAM component, which contains a full word. However, for a given address in RAM, if you want to retrieve a specific byte or halfword in the address, you need to use the selector bits (described below). By default, the component's address width is 20 bits (which means that, by default, it can store 2^20 words = 4 * 2^20 bytes = 4MB).
- D contains the data to be stored in RAM. Depending on how sel is set, only certain bytes within D will be written.
- str is the store bit. You can think of it as Write Enable. When str = 1, RAM will write the value on D to address A according to the sel bits.
- sel is for the selector bits. As mentioned above, bits 0..7 of D correspond to sel = 0001, bits 8..15 correspond to sel = 0010, bits 16..23 to 0100, and bits 24..31 to 1000. sel accepts other combinations like 1100 (to grab the upper halfword), 1111 (to grab the full word), or even something wacky like 1010.
- ld is the load bit. Data Out D always sets floating values (X's) along the wire unless the appropriate selector bits are set and ld = 1.
- clr clears all of RAM whenever it is 1.

ram inputs/output

#### Using the Byte Selector

As previously mentioned, address A gets us to the word in memory. However, we need to use sel to determine which bytes in the word we want to write to or read from. The Byte selector is 4 bits, and you can think of each bit as a read/write enable for each of the four bytes in the word.
Specifically, bit 0 of sel enables the first byte from the right in the RAM component. When writing to RAM, bits 0 to 7 of DataIn are written to this byte, and when reading from RAM, the byte's value gets read out to bits 0 to 7 of DataOut. Bit 1 of sel enables the second byte from the right, and corresponds with bits 8 to 15 of DataIn and DataOut. Bit 2 enables the third byte from the right and corresponds with bits 16 to 23, and bit 3 enables the fourth byte, and corresponds with bits 24 to 31.

#### Storing

Writing into the RAM component requires that the str bit is set to 1.
In the example to the right, DataIn is set so that a hex value 0xf1 is in the bottom line (bits 7..0), 0xf2 is in the second line (bits 15..8), 0xf3 is in the third line (bits 23..16), and 0xf4 is in the top line (bits 24..31). The gif demonstrates how to write different bytes or halfwords to the RAM.
When you want to write a byte to a location in RAM, pay attention that you place the byte-values in DataIn correctly with selector bits. In the example above, if you wanted to write 0xf1 to left-most byte, you would need to put 0xf1 in bits 24..31 in DataIn and set sel = 1000.

selector store

#### Loading

Reading from the RAM component requires that the ld bit is set to 1.
Loading is a bit more straightforward. Just be sure that when you are reading a byte from memory that you retrieve the byte from the right bits on DataOut. For example, if you were only selecting with sel = 0100, then you'd have to make sure that, when you're splitting DataOut, that you isolate the correct byte (bits 23..16).

selector load

#### A Note on Implementing Byte Addressed Memory

All the addresses that we deal with in the MIPS instruction set are expressed in terms of byte addresses. This means that address 0x0000 refers to the first byte in memory, and 0x0001 the second byte, and so on. Since every word has four bytes (in other words, since every four bytes is a new word), then 0x0000 still refers to the first word, but the second word is at address 0x0004.
It is key that you understand that the RAM is word addressed. It is an error to pass the raw byte-address into the A input.

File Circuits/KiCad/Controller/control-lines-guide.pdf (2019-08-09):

FLAGS_Fc_set; FLAGS_Fc_clear FLAGS_Fc_load; FLAGS_Flt_load; FLAGS_Feq_load FLAGS_Fgt_load FLAGS_Fz_load OUT2_load; OUT1_load; IN_out; TSTATE_reset CLOCK_halt MEM_out; MEM_RAM_load; MAR_ZP; MAR_HB_load MAR_LB_load; ALU_out; ALU_shr ALU_m; ALU_s3; ALU_s2; ALU_s1; ALU_s0; AY_load; AX_load; STK_MAR_out STK_reset; STK_dec STK_inc; PC_HB_out PC_LB_out; PC_HB_load PC_LB_load PC_dec PC_inc; PC_MAR_out; IR_load; D_load D_out; C_load C_out; B_load B_out; A_load A_out

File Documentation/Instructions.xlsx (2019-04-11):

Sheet: Instructions
Mnemonic | Opcode (binary) | Operand 1 | Operand 2 | Description | Summary
NOP | 000 0000 |  |  | Do nothing | NOP | Do nothing
HLT | 000 0001 |  |  | Halt execution | HLT | Halt execution
MOV A,B | 000 0010 |  |  | Copy A to B | MOV [A,B,C,D] [A,B,C,D,AX,AY] | Copy register N1 to register N2
MOV A,C | 000 0011 |  |  |  | MVI [A,B,C,D,AX,AY] value | Copy immediate value to register N
MOV A,D | 000 0100 |  |  |  | LD [A,B,C,D,AX,AY] address | Load register N with value at memory address
MOV B,A | 000 0101 |  |  |  | ST [A,B,C,D] address | Store register N value at memory address
MOV B,C | 000 0110
MOV B,D | 000 0111
MOV C,A | 000 1000 |  |  |  | ADD [A,B,C,D] | AX + AY → N
MOV C,B | 000 1001 |  |  |  | ADC [A,B,C,D] | AX + AY + c → N
MOV C,D | 000 1010 |  |  |  | SUB [A,B,C,D] | AX - AY → N
MOV D,A | 000 1011 |  |  |  | SBC [A,B,C,D] | AX - AY - c → N
MOV D,B | 000 1100 |  |  |  | AND [A,B,C,D] | AX & AY → N
MOV D,C | 000 1101 |  |  |  | OR [A,B,C,D] | AX | AY → N
MVI A | 000 1110 | byte |  | Copy immediate value to A | XOR [A,B,C,D] | AX ⊕ AY → N
MVI B | 000 1111 | byte |  |  | NOT [A,B,C,D] | !AX → N
MVI C | 001 0000 | byte |  |  | INC [A,B,C,D] | AX + 1 → N
MVI D | 001 0001 | byte |  |  | DEC [A,B,C,D] | AX - 1 → N
LD A | 001 0010 | address high byte | address low byte | Load register A with data from memory location | CMP | Compare AX with AY and set Feq, Flt and Fgt flags. Set Fz if AX equals 0
LD B | 001 0011 | address high byte | address low byte |  | JMP address | Jump to memory address
~~LD C~~ | ~~001 0100~~ | ~~address high byte~~ | ~~address low byte~~ | Removed because LD operation uses C/D register | JZ address | Jump to memory address if zero flag is set
~~LD D~~ | ~~001 0101~~ | ~~address high byte~~ | ~~address low byte~~ | Removed because LD operation uses C/D register | JNZ address | Jump to memory address if zero flag is not set
ST A | 001 0110 | address high byte | address low byte | Store register A to memory location | JC address | Jump to memory address if carry flag is set
ST B | 001 0111 |  |  |  | JNC address | Jump to memory address if carry flag is not set
~~ST C~~ | ~~001 1000~~ |  |  | Removed because ST operation uses C/D register | JEQ address | Jump to memory address if N = B
~~ST D~~ | ~~001 1001~~ |  |  | Removed because ST operation uses C/D register | JLT address | Jump to memory address if N < B
ADD A | 001 1010 |  |  | Store A + B in A register | JGT address | Jump to memory address if N > B
ADD C | 001 1011 |  |  |  | CALL address | Jump to subroutine at memory address
ADD D | 001 1100 |  |  |  | RET | Return from subroutine
ADC A | 001 1101 |  |  | Store A + B + 1 in A register | IN [A,B,C,D] | Load data from input into register A (needs to be worked out)
ADC C | 001 1110 |  |  |  | OUT [1,2] [A,B,C,D] | Output data from register N2 on output N1 (1 = decimal display, 2 = serial output)
ADC D | 001 1111 |  |  |  | SHL [A,B,C,D] | Shift all bits in register AX one bit to the left and store in register N
SUB A | 010 0000 |  |  | Store A - B in A register | SHR [A,B,C,D] | Shift all bits in register AX one bit to the right and store in register N
SUB C | 010 0001 |  |  |  | SC [0,1] | Set carry flag to 0 or 1
SUB D | 010 0010
SBC A | 010 0011 |  |  | Store A - B - 1 in A register
SBC C | 010 0100
SBC D | 010 0101
AND A | 010 0110 |  |  | Store A & B in A register
AND C | 010 0111
AND D | 010 1000
OR A | 010 1001 |  |  | Store A | B in A register
OR C | 010 1010
OR D | 010 1011
XOR A | 010 1100 |  |  | Store A ⊕ B in A register
XOR B | 010 1101
XOR C | 010 1110
XOR D | 010 1111
NOT A | 011 0000 |  |  | Store !A in A register
NOT B | 011 0001
NOT C | 011 0010
NOT D | 011 0011
INC A | 011 0100 |  |  | Increment A by one
INC B | 011 0101
INC C | 011 0110
INC D | 011 0111
DEC A | 011 1000 |  |  | Decrement A by one
DEC B | 011 1001
DEC C | 011 1010
DEC D | 011 1011
CMP A | 011 1100 |  |  | Compare A with B
JMP | 011 1111 | address high byte | address low byte | Jump to memory location
JZ | 100 0000 | address high byte | address low byte | Jump if zero
JNZ | 100 0001 | address high byte | address low byte | Jump if not zero
JC | 100 0010 | address high byte | address low byte | Jump if carry
JNC | 100 0011 | address high byte | address low byte | Jump if not carry
JEQ | 100 0100
JLT | 100 0101
JGT | 100 0110
CALL | 100 0111 | address high byte | address low byte | Jump to subroutine
RET | 100 1000 |  |  | Return from subroutine
IN A | 100 1001 |  |  | Load data from input in the A register
IN B | 100 1010
IN C | 100 1011
IN D | 100 1100
OUT 1 A | 100 1101 |  |  | Output data from A register to output #1
OUT 1 B | 100 1110
OUT 1 C | 100 1111
OUT 1 D | 101 0000
OUT 2 A | 101 0001 |  |  | Output data from A register to output #2
OUT 2 B | 101 0010
OUT 2 C | 101 0011
OUT 2 D | 101 0100
~~SHL~~ | 101 0101
~~SHR~~ | ~~101 0110~~
~~RAL~~ | ~~101 0111~~ |  |  | ~~Rotate all A bits to the left~~
~~RAR~~ | ~~101 1000~~ |  |  | ~~Rotate all A bits to the right~~
 | ~~101 1001~~
 | 101 1010
 | 101 1011
 | 101 1100
 | 101 1101
 | 101 1110
 | 101 1111
 | 110 0000
 | 110 0001
 | 110 0010
 | 110 0011
 | 110 0100
 | 110 0101
 | 110 0110
 | 110 0111
 | 110 1000
 | 110 1001
 | 110 1010
 | 110 1011
 | 110 1100
 | 110 1101
 | 110 1110
 | 110 1111
 | 111 0000
 | 111 0001
 | 111 0010
 | 111 0011
 | 111 0100
 | 111 0101
 | 111 0110
 | 111 0111
 | 111 1000
 | 111 1001
 | 111 1010
 | 111 1011
 | 111 1100
 | 111 1101
 | 111 1110
 | 111 1111

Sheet: Control lines
ROM micro-code layout
 | Bit 7 | Bit 6 | Bit 5 | Bit 4 | Bit 3 | Bit 2 | Bit 1 | Bit 0
Bank 0 |  |  | MAR_ZP | FLAGS_Fc_set | FLAGS_Fc_clear | FLAGS_Fc_load | FLAGS_Flt_load | FLAGS_Feq_load
Bank 1 | FLAGS_Fgt_load | OUT2_load | OUT1_load | IN_out | TSTATE_reset | CLOCK_halt | MEM_out | MEM_RAM_load
Bank 2 | MAR_STK_load | MAR_PC_load | MAR_HB_load | MAR_LB_load | ALU_out | ALU_shr | ALU_m | ALU_s3
Bank 3 | ALU_s2 | ALU_s1 | ALU_s0 | AY_load | AX_load | STK_reset | STK_dec | STK_inc
Bank 4 | PC_HB_out | PC_LB_out | PC_HB_load | PC_LB_load | PC_dec | PC_inc | IR_load | FLAGS_Fz_load
Bank 5 | D_load | D_out | C_load | C_out | B_load | B_out | A_load | A_out

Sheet: T-states
 | Bank | 0 |  |  |  |  |  |  |  | 1 |  |  |  |  |  |  |  | 2 |  |  |  |  |  |  |  | 3 |  |  |  |  |  |  |  | 4 |  |  |  |  |  |  |  | 5
 | Bit | 7 | 6 | 5 | 4 | 3 | 2 | 1 | 0 | 7 | 6 | 5 | 4 | 3 | 2 | 1 | 0 | 7 | 6 | 5 | 4 | 3 | 2 | 1 | 0 | 7 | 6 | 5 | 4 | 3 | 2 | 1 | 0 | 7 | 6 | 5 | 4 | 3 | 2 | 1 | 0 | 7 | 6 | 5 | 4 | 3 | 2 | 1 | 0
Hardwired T-states |  |  |  |  |  |  |  |  |  |  | OUT2_in | OUT1_in | IN_out | TSTATE_reset | CLOCK_halt | MEM_out | MEM_RAM_load | MAR_STK_load | MAR_PC_load | MAR_HB_load | MAR_LB_load | ALU_out | ALU_cn | ALU_m | ALU_s3 | ALU_s2 | ALU_s1 | ALU_s0 | ALU_B_in | ALU_A_in | STK_reset | STK_dec | STK_inc | PC_HB_out | PC_LB_out | PC_HB_load | PC_LB_load | PC_dec | PC_inc | IR_load | FLAGS_load | D_load | D_out | C_load | C_out | B_load | B_out | A_load | A_out
T0 | Load PC into MAR |  |  |  |  |  |  |  |  |  |  |  |  |  |  |  |  |  | x
T1 | Load Opcode from RAM, incr PC |  |  |  |  |  |  |  |  |  |  |  |  |  |  | x |  |  |  |  |  |  |  |  |  |  |  |  |  |  |  |  |  |  |  |  |  |  | x | x
NOP
T2 | Do nothing, reset sequencer |  |  |  |  |  |  |  |  |  |  |  |  | x
HALT
T2 | Halt clock |  |  |  |  |  |  |  |  |  |  |  |  |  | x
MOV A,B
T2 | Load A into B, reset Sequencer
MVI A
T2 | Load PC into MAR
T3 | Load RAM byte into A, incr PC, reset TSTATE
LD A
T2 | Load PC into MAR
T3 | Load RAM byte (high) into Y, incr PC
T4 | Load PC into MAR
T5 | Load RAM byte (low) into X, incr PC
T6 | Load X & Y into MAR
T7 | Load RAM byte into A, reset Sequencer
ST A
T2 | Load PC into MAR
T3 | Load RAM byte (high) into Y, incr PC
T4 | Load PC into MAR
T5 | Load RAM byte (low) into X, incr PC
T6 | Load X & Y into MAR
T7 | Load A into RAM, reset Sequencer
ADD
T2 | ALU Add (A+B), load ALU into A, load Flags, reset Sequencer
CALL
T2 | Increment PC
T3 | Increment PC
T4 | Load PC into X & Y
T5 | Load SP into MAR
T6 | Load Y (high addr) into RAM, incr SP
T7 | Load SP into MAR
T8 | Load X (high addr) into RAM, incr SP, decr PC
T9 | Decrement PC
T10 | Load PC into MAR
T11 | Load RAM byte (high) into Y, incr PC
T12 | Load PC into MAR
T13 | Load RAM byte (low) into X
T14 | Load X & Y into PC, reset Sequencer
RET
T2 | Decrement SP
T3 | Load SP into MAR
T4 | Load RAM byte (low) into X, decr SP
T5 | Load SP into MAR
T6 | Load RAM byte (high) into Y
T7 | Load X & Y into PC, reset Sequencer

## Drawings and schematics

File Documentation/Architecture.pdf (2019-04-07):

## Clocked

## Buffered input

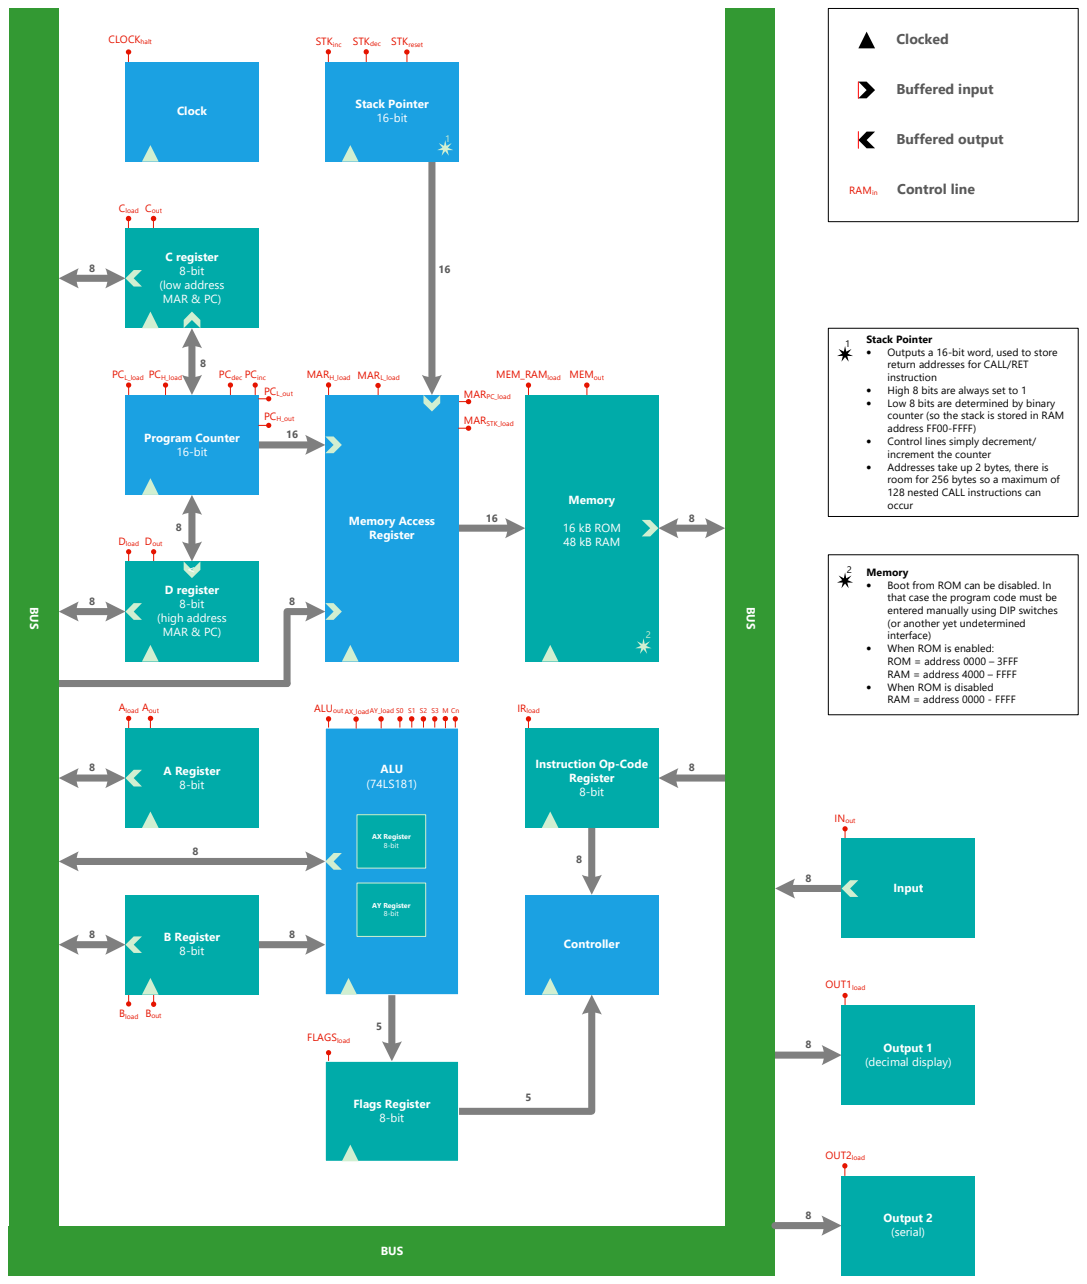
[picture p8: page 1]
MARPC_load; ALUout; FLAGSload; Bload Bout; Aload Aout; PCdec PCinc; Dload Dout; Memory; 16 kB ROM 48 kB RAM; BUS; Memory Access Register; C register 8-bit (low address MAR & PC); D register 8-bit (high address MAR & PC); B Register 8-bit; A Register 8-bit; Flags Register 8-bit; Controller; Output 1 (decimal display); Input; Clock; ALU (74LS181); Program Counter; 16-bit; Buffered output; Cload Cout; PCL_load PCH_load; MARH_load MARL_load; IRload; MEM_RAMload; MEMout; OUT1load; INout; CLOCKhalt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

Stack Pointer
• Outputs a 16-bit word, used to store
return addresses for CALL/RET
instruction
• High 8 bits are always set to 1
• Low 8 bits are determined by binary
counter (so the stack is stored in RAM
address FF00-FFFF)
• Control lines simply decrement/
increment the counter
• Addresses take up 2 bytes, there is
room for 256 bytes so a maximum of
128 nested CALL instructions can
occur

2 Memory
• Boot from ROM can be disabled. In
that case the program code must be
entered manually using DIP switches
(or another yet undetermined
interface)
• When ROM is enabled:
ROM = address 0000 – 3FFF
RAM = address 4000 – FFFF
• When ROM is disabled
RAM = address 0000 - FFFF

Instruction Op-Code
Register
8-bit

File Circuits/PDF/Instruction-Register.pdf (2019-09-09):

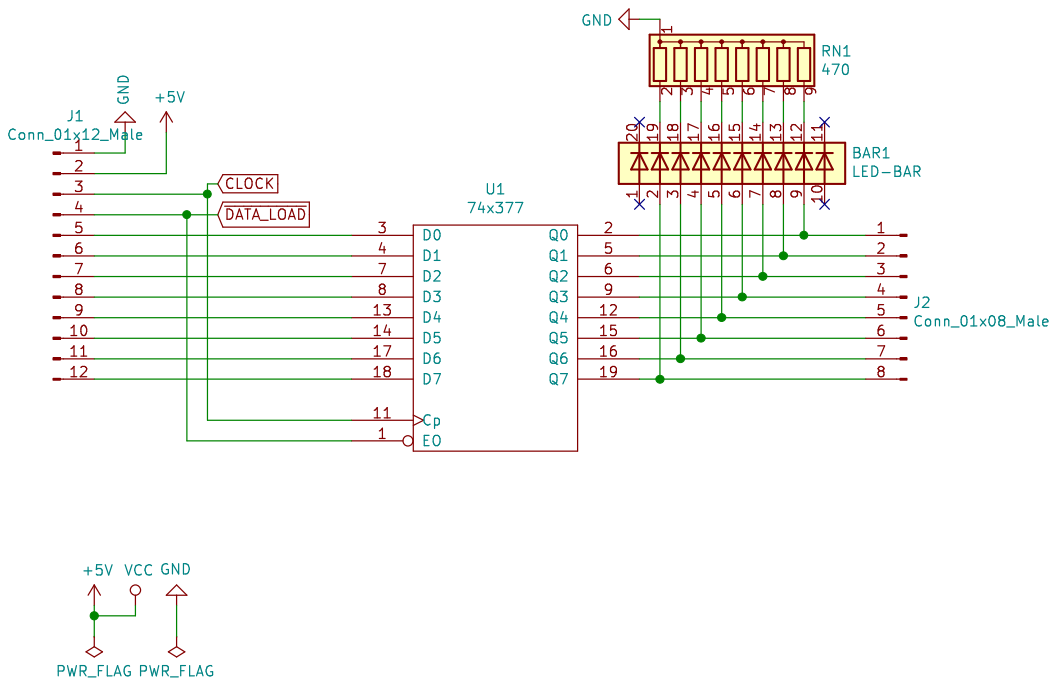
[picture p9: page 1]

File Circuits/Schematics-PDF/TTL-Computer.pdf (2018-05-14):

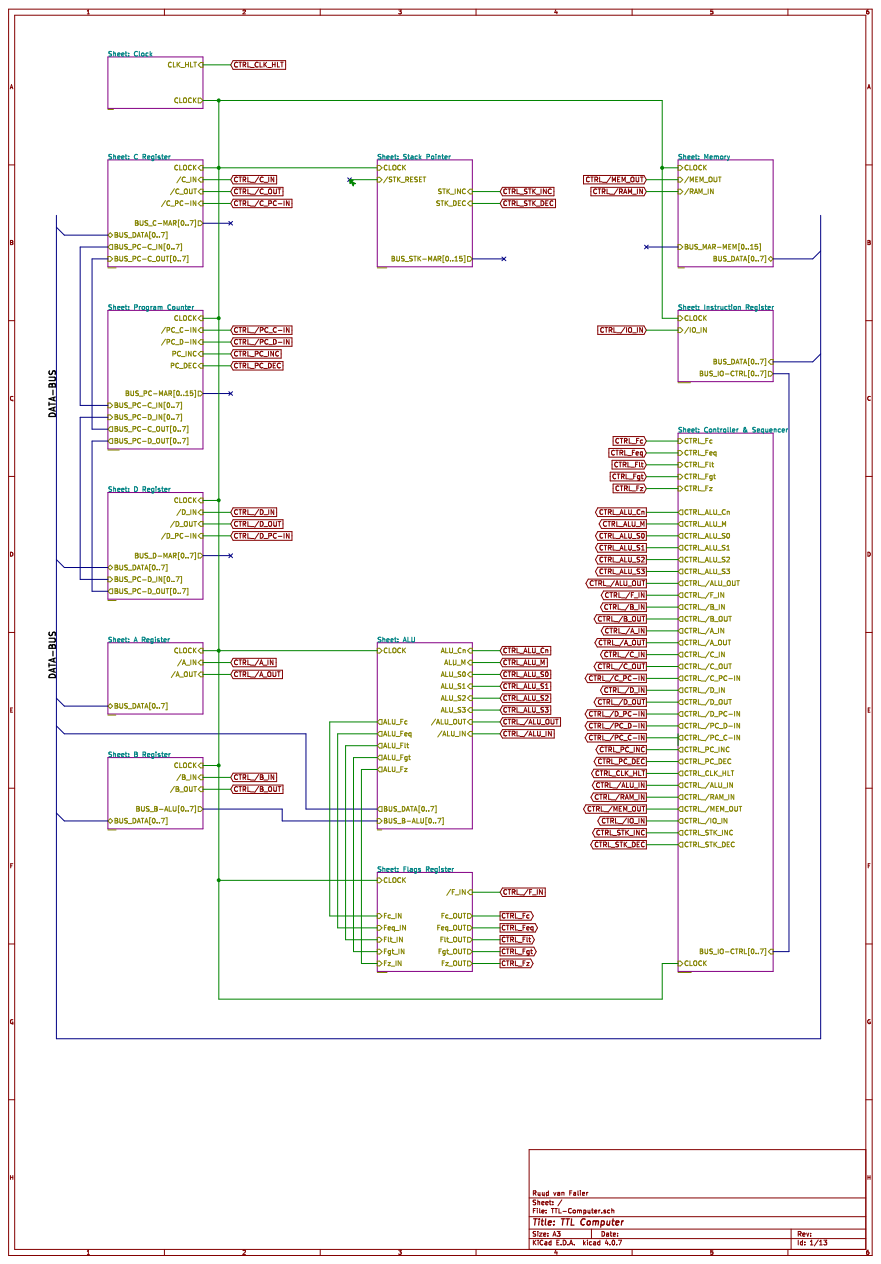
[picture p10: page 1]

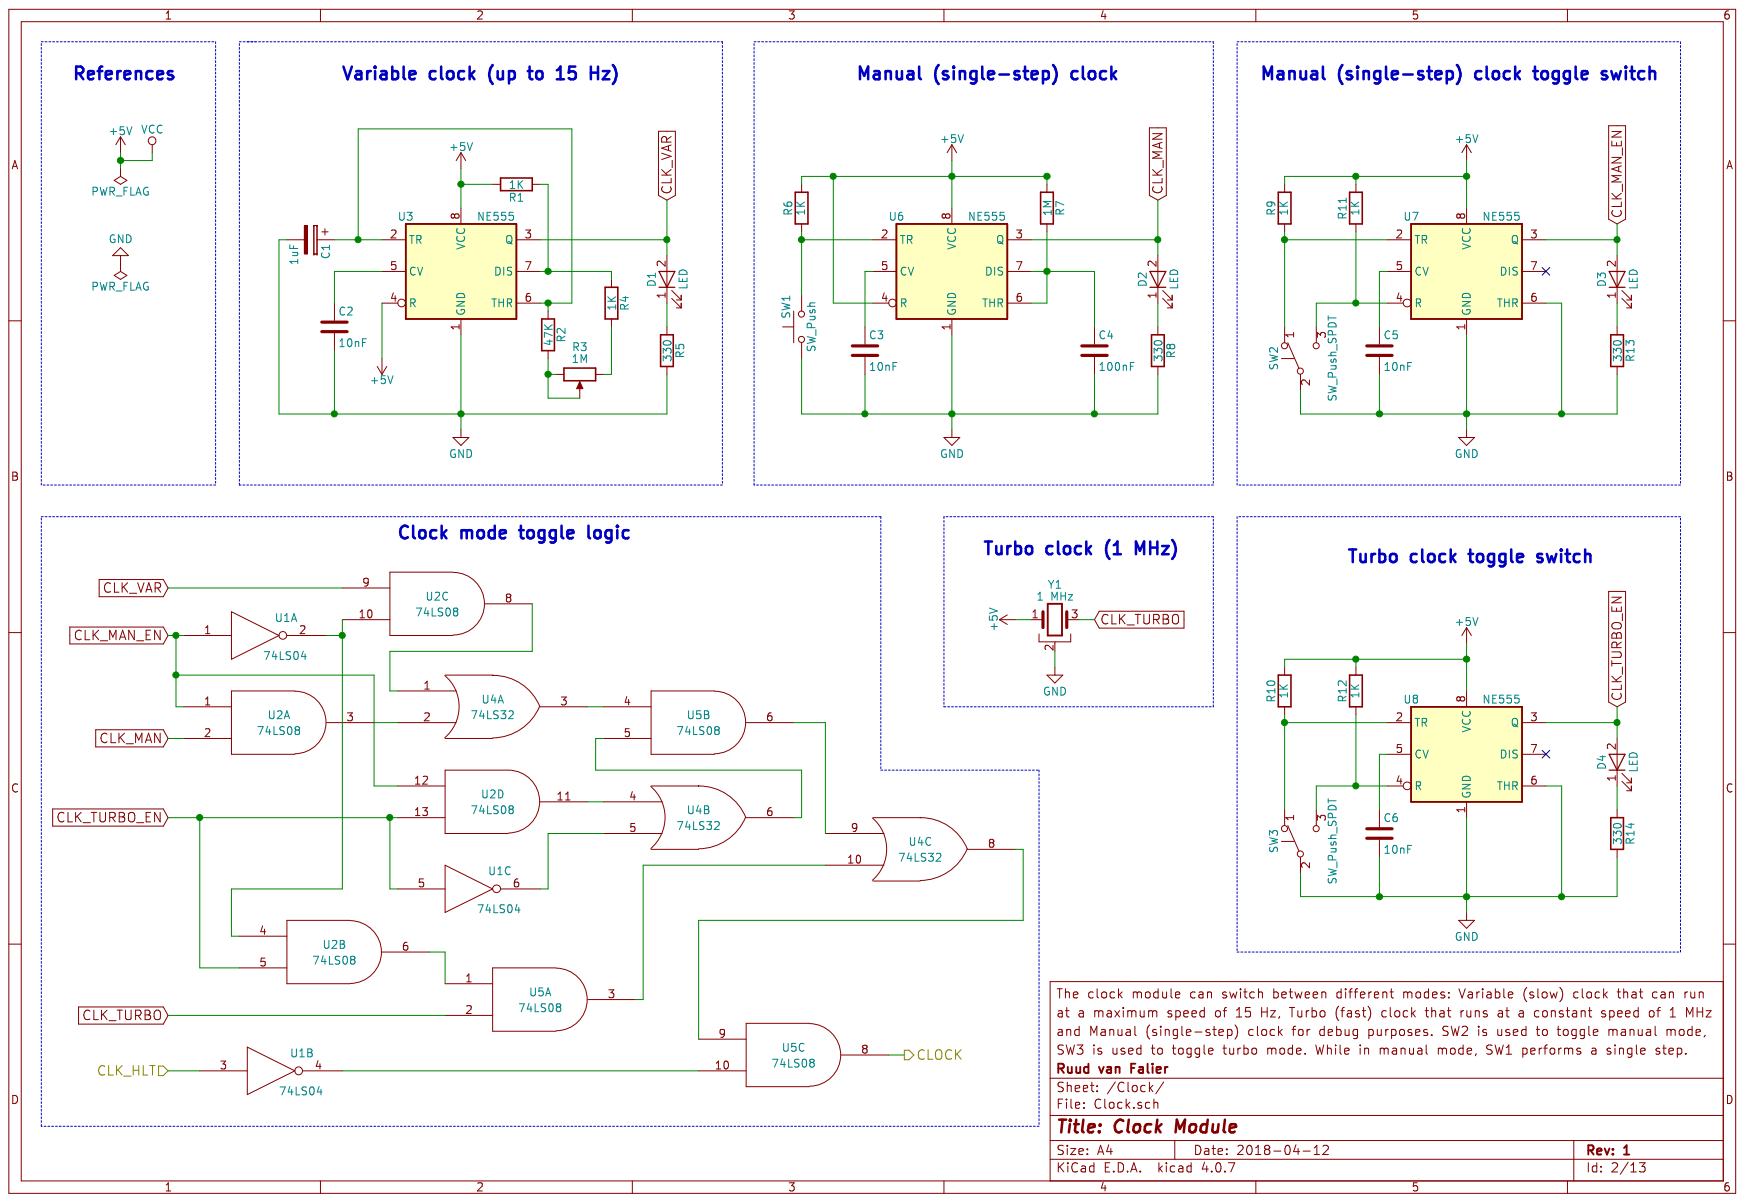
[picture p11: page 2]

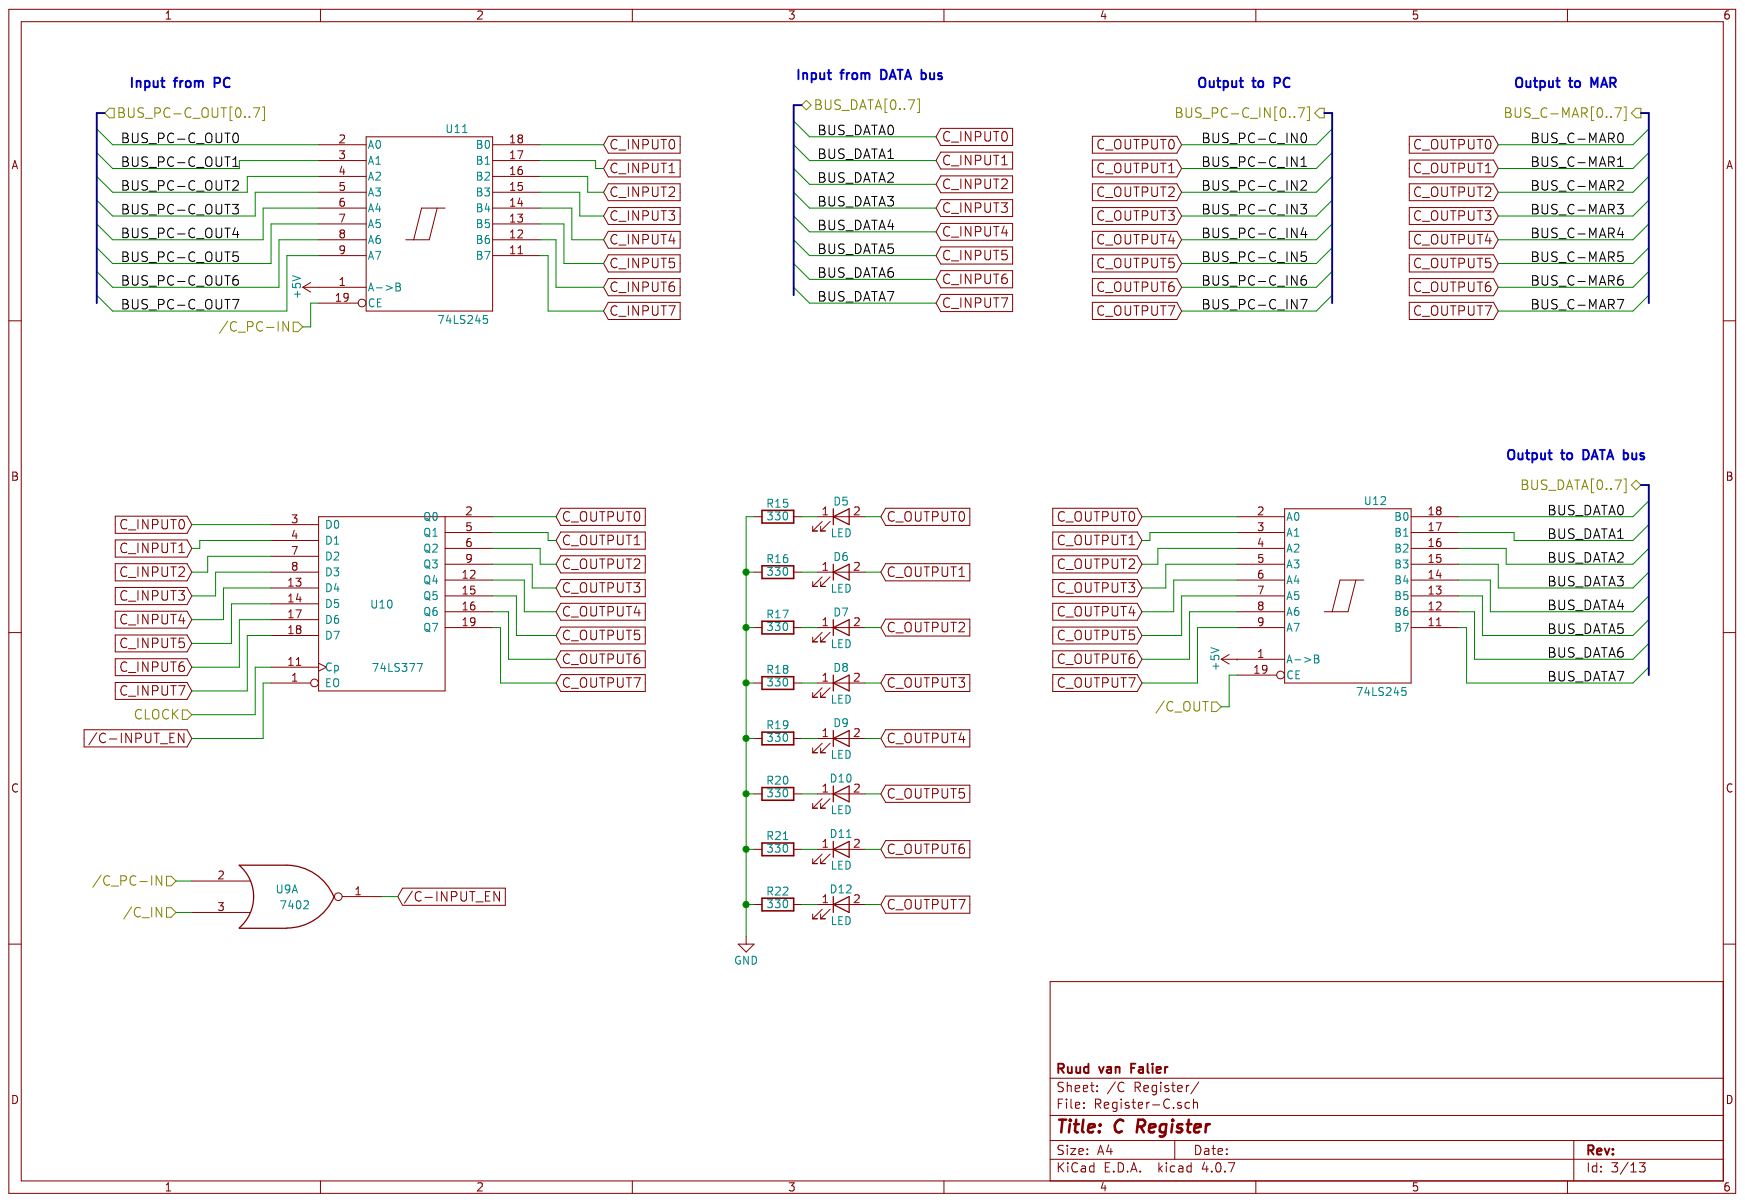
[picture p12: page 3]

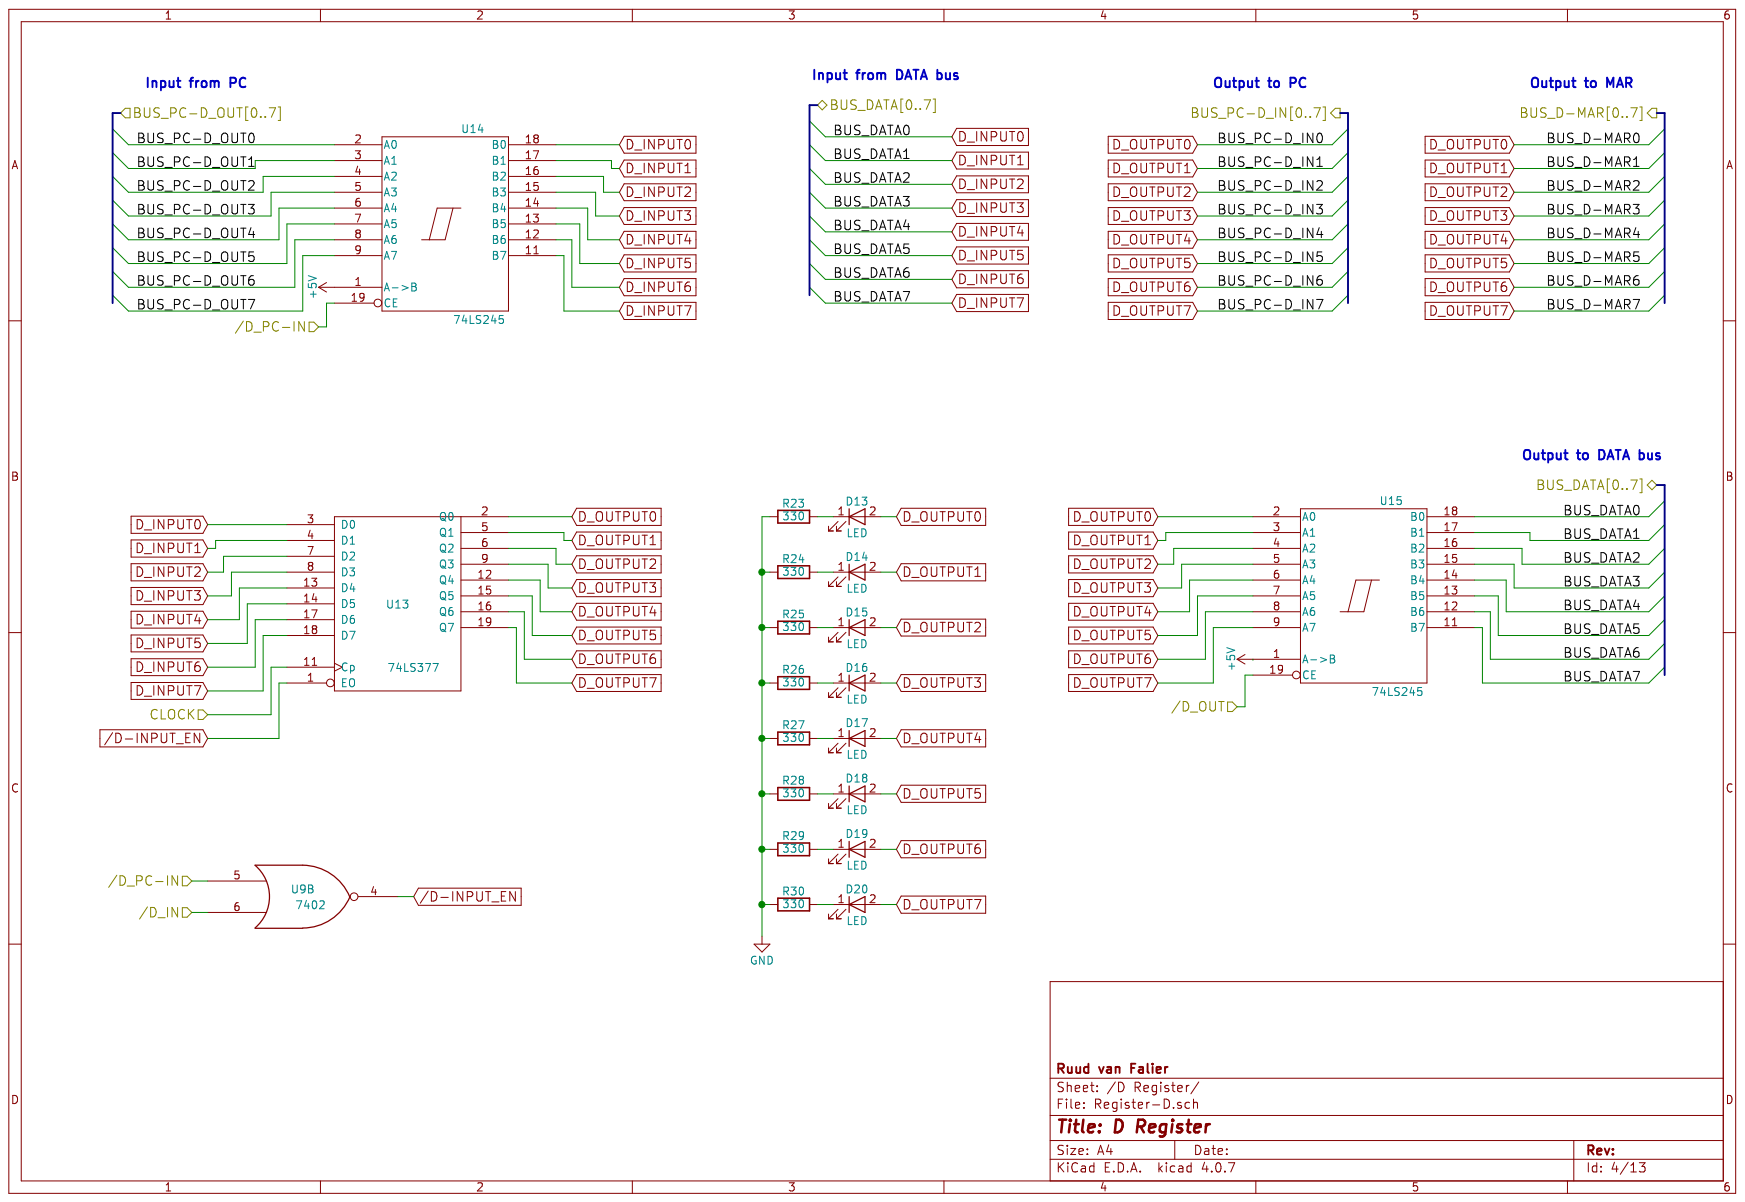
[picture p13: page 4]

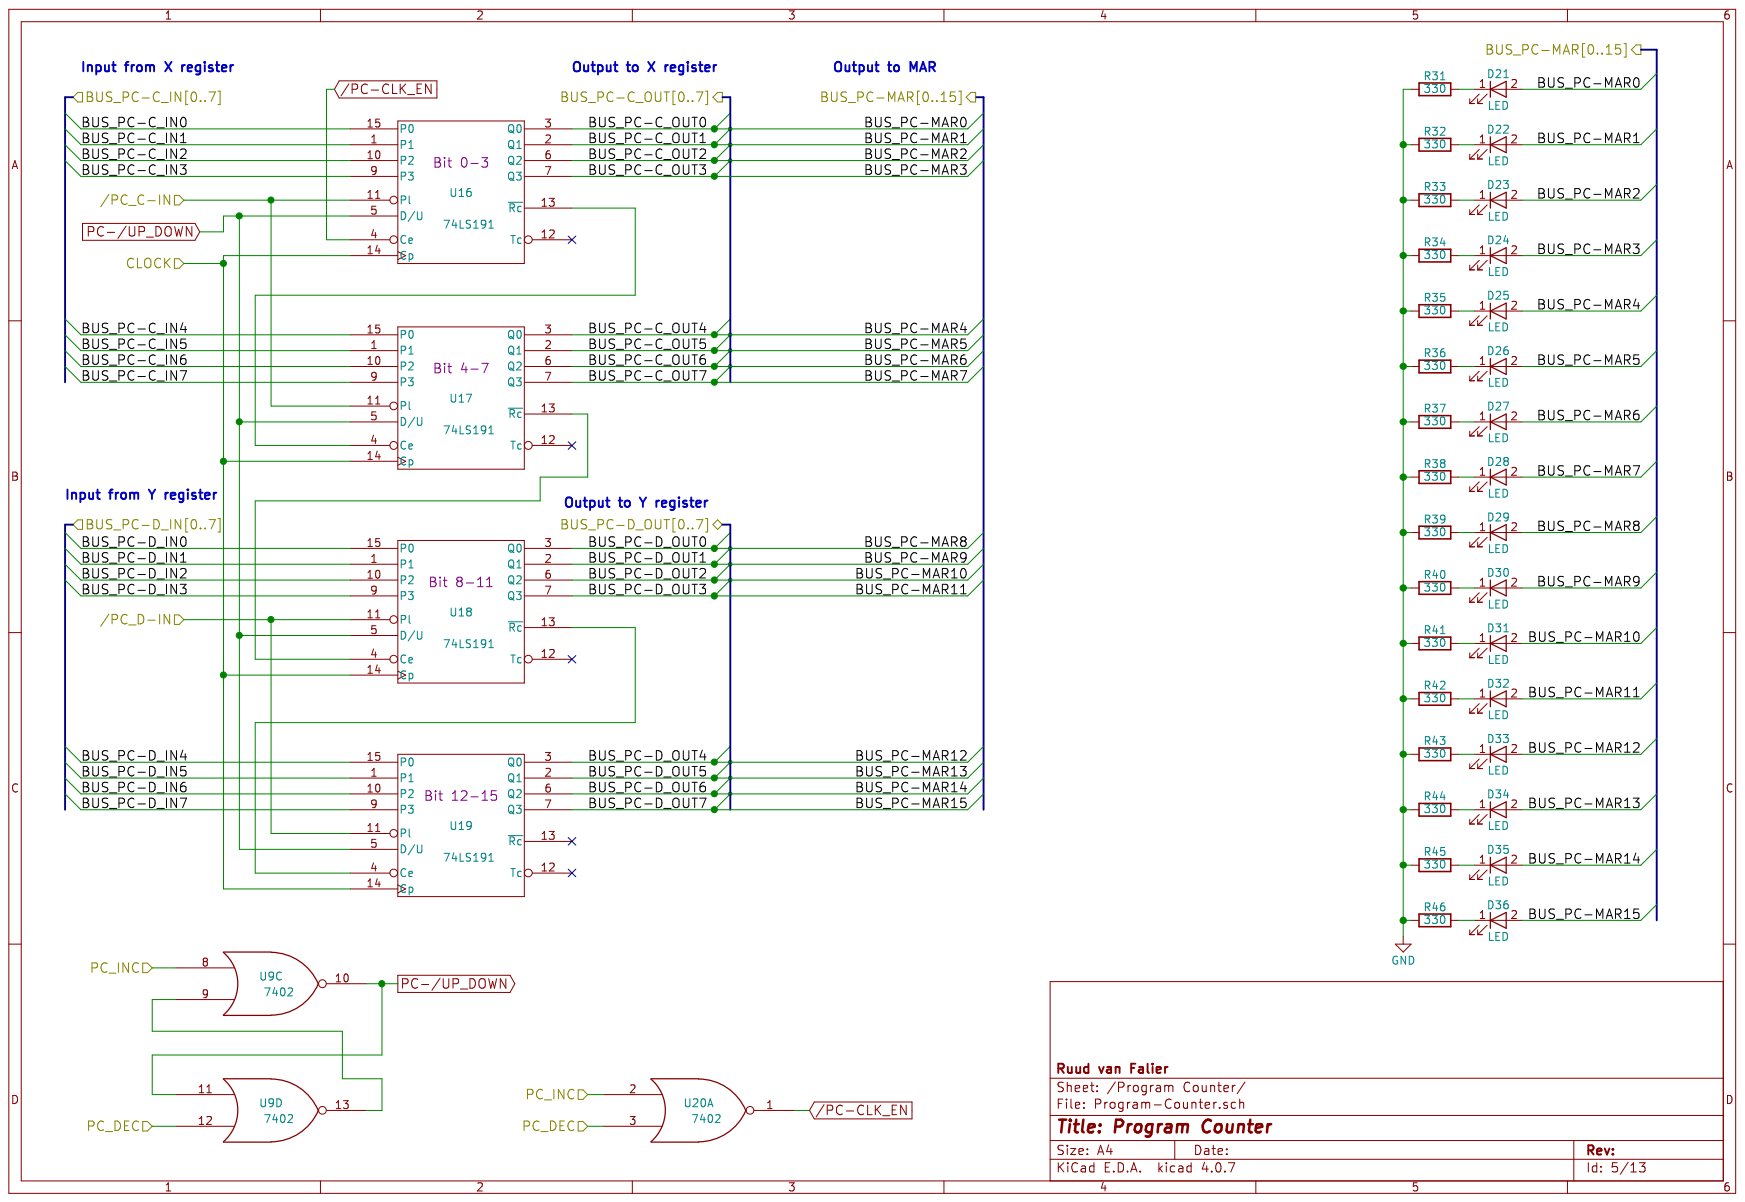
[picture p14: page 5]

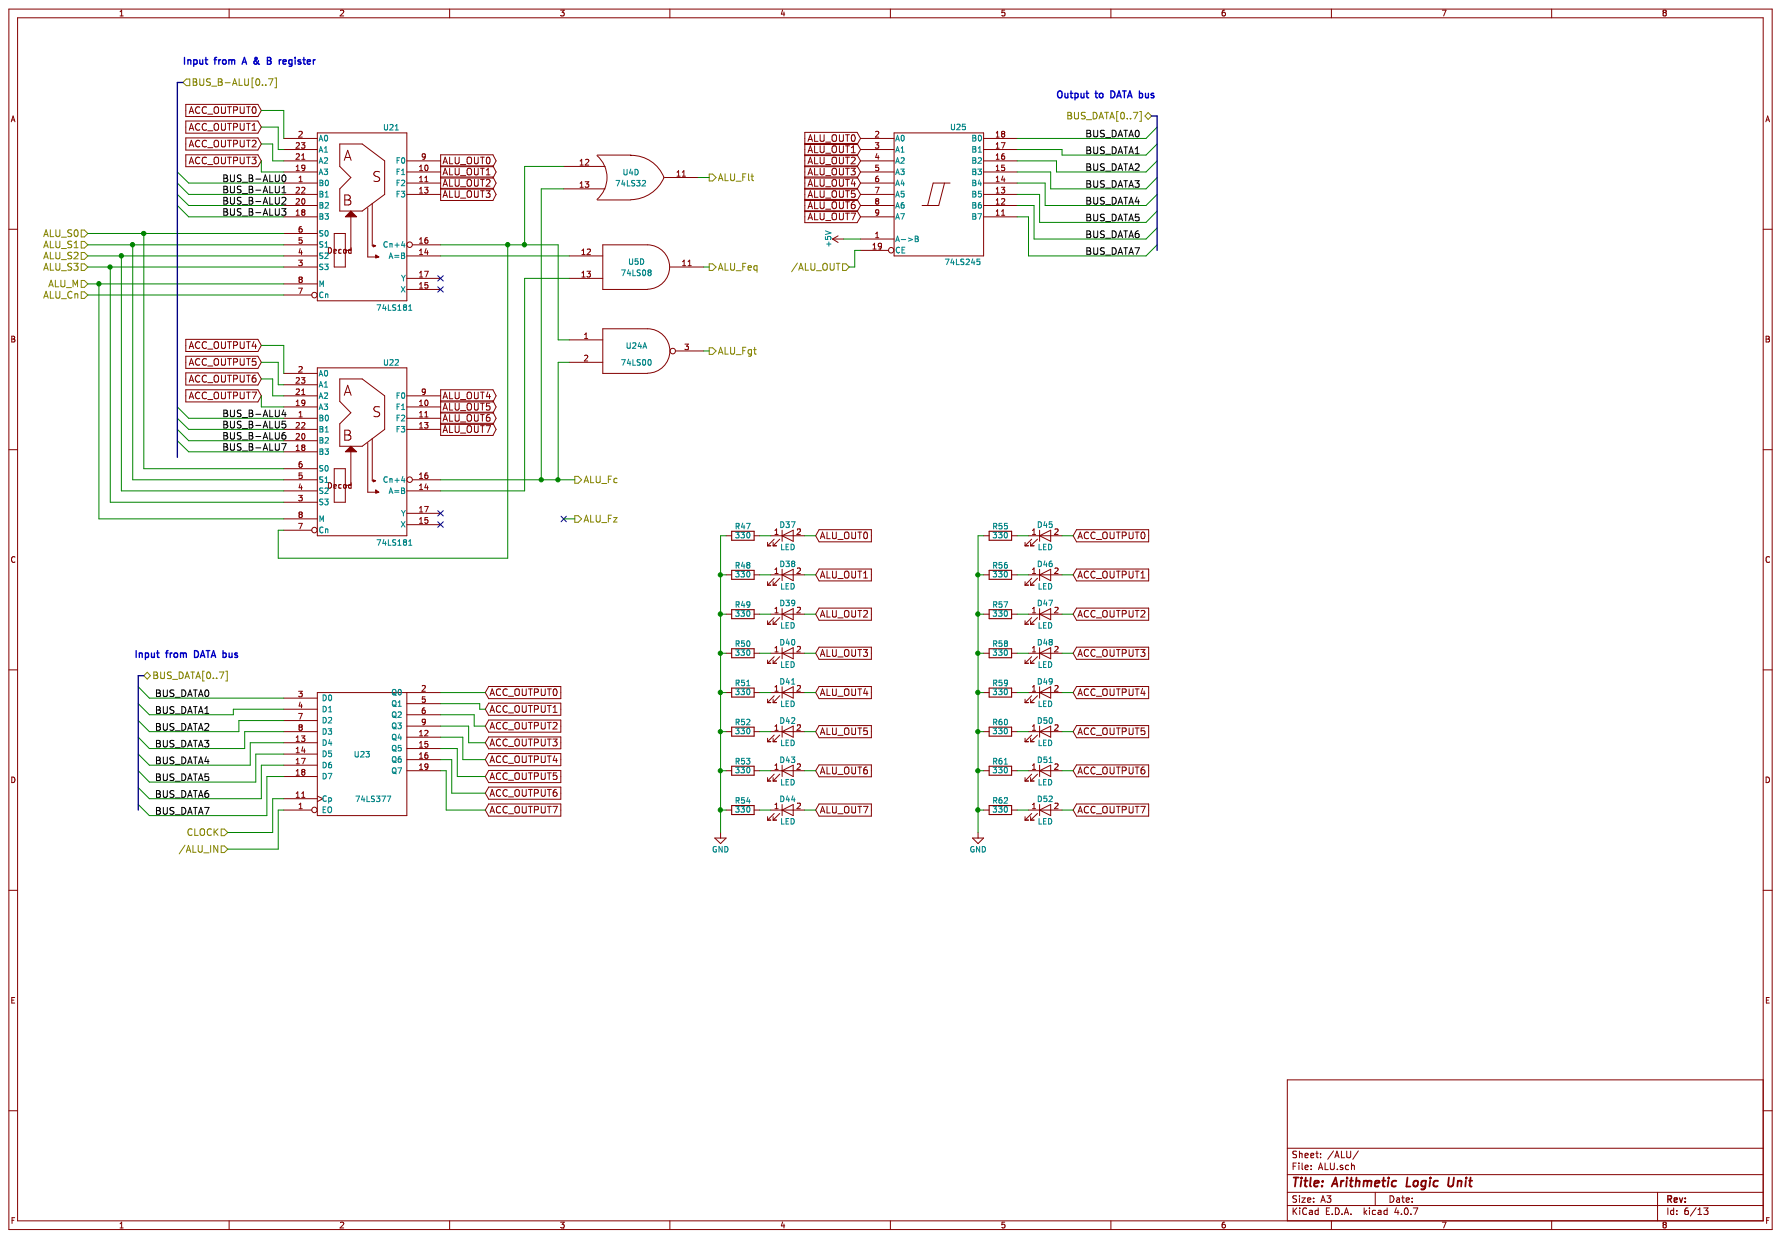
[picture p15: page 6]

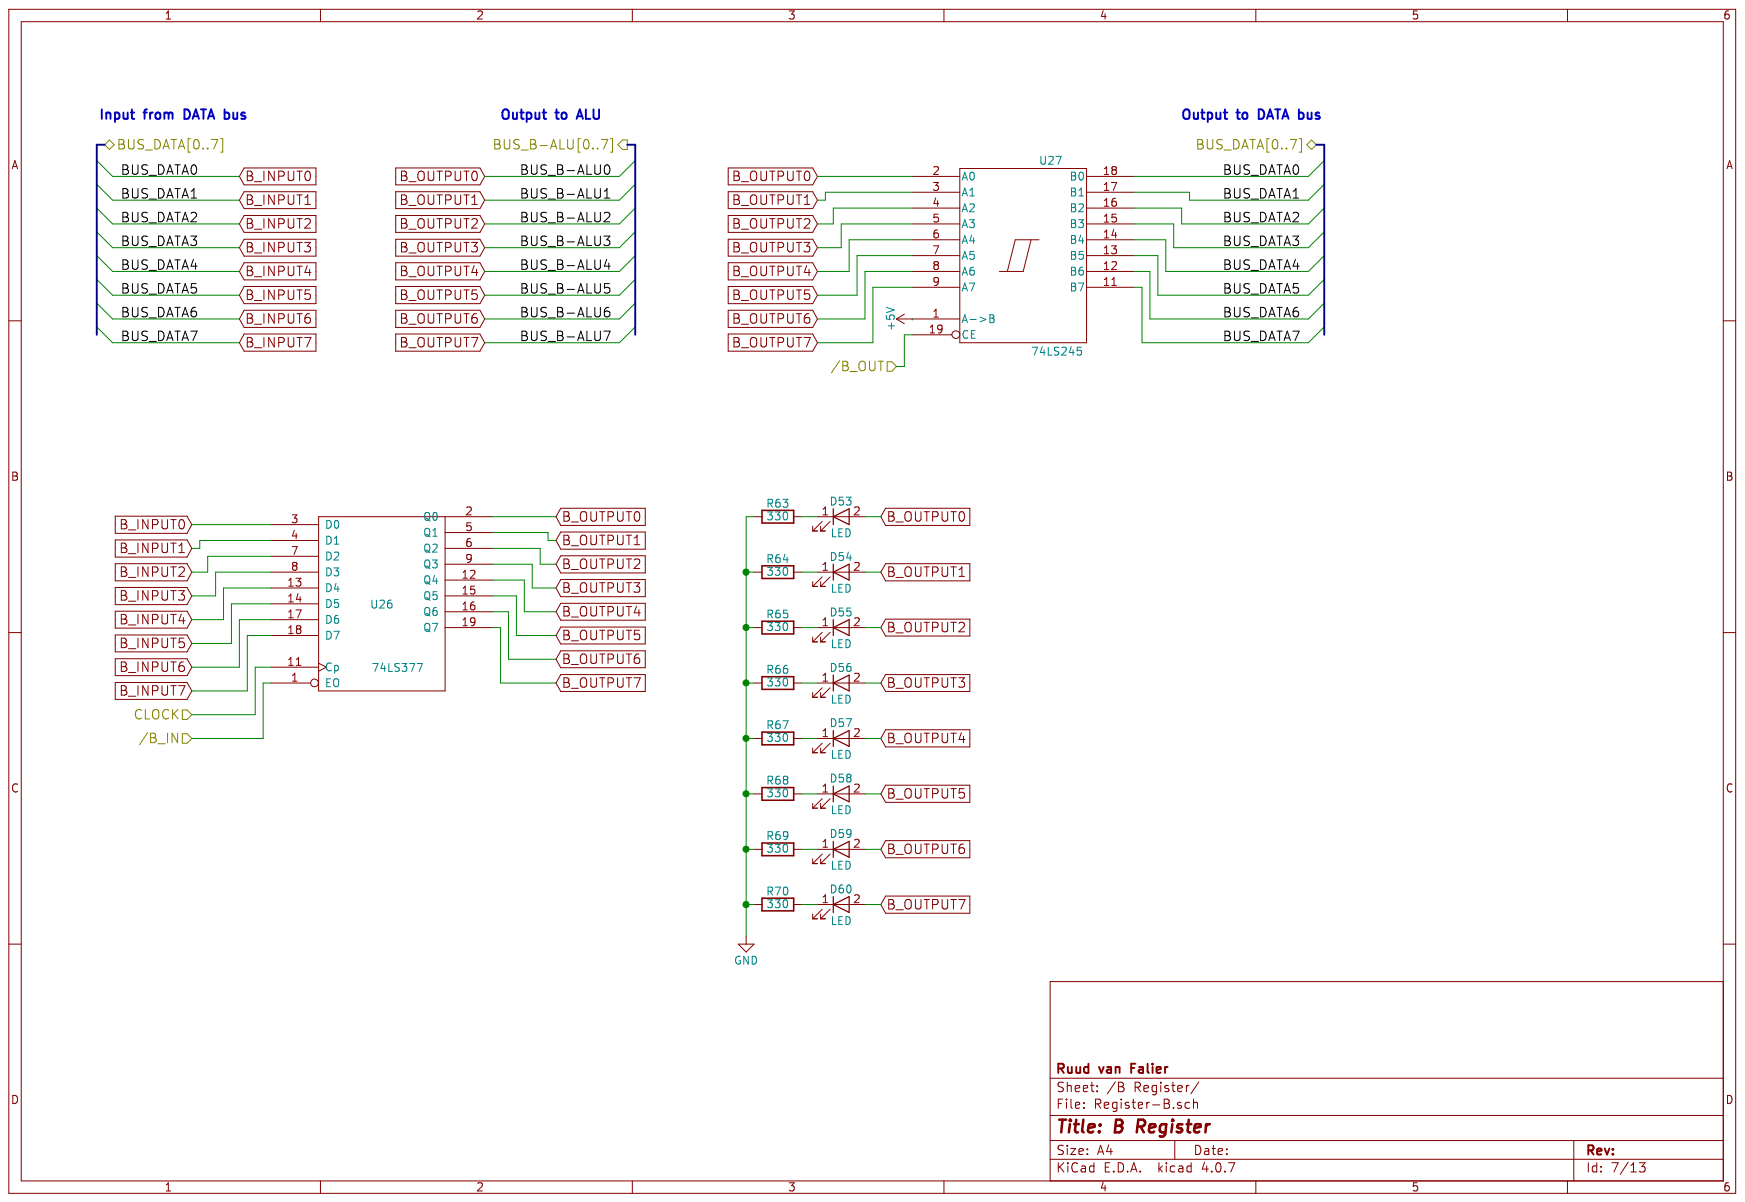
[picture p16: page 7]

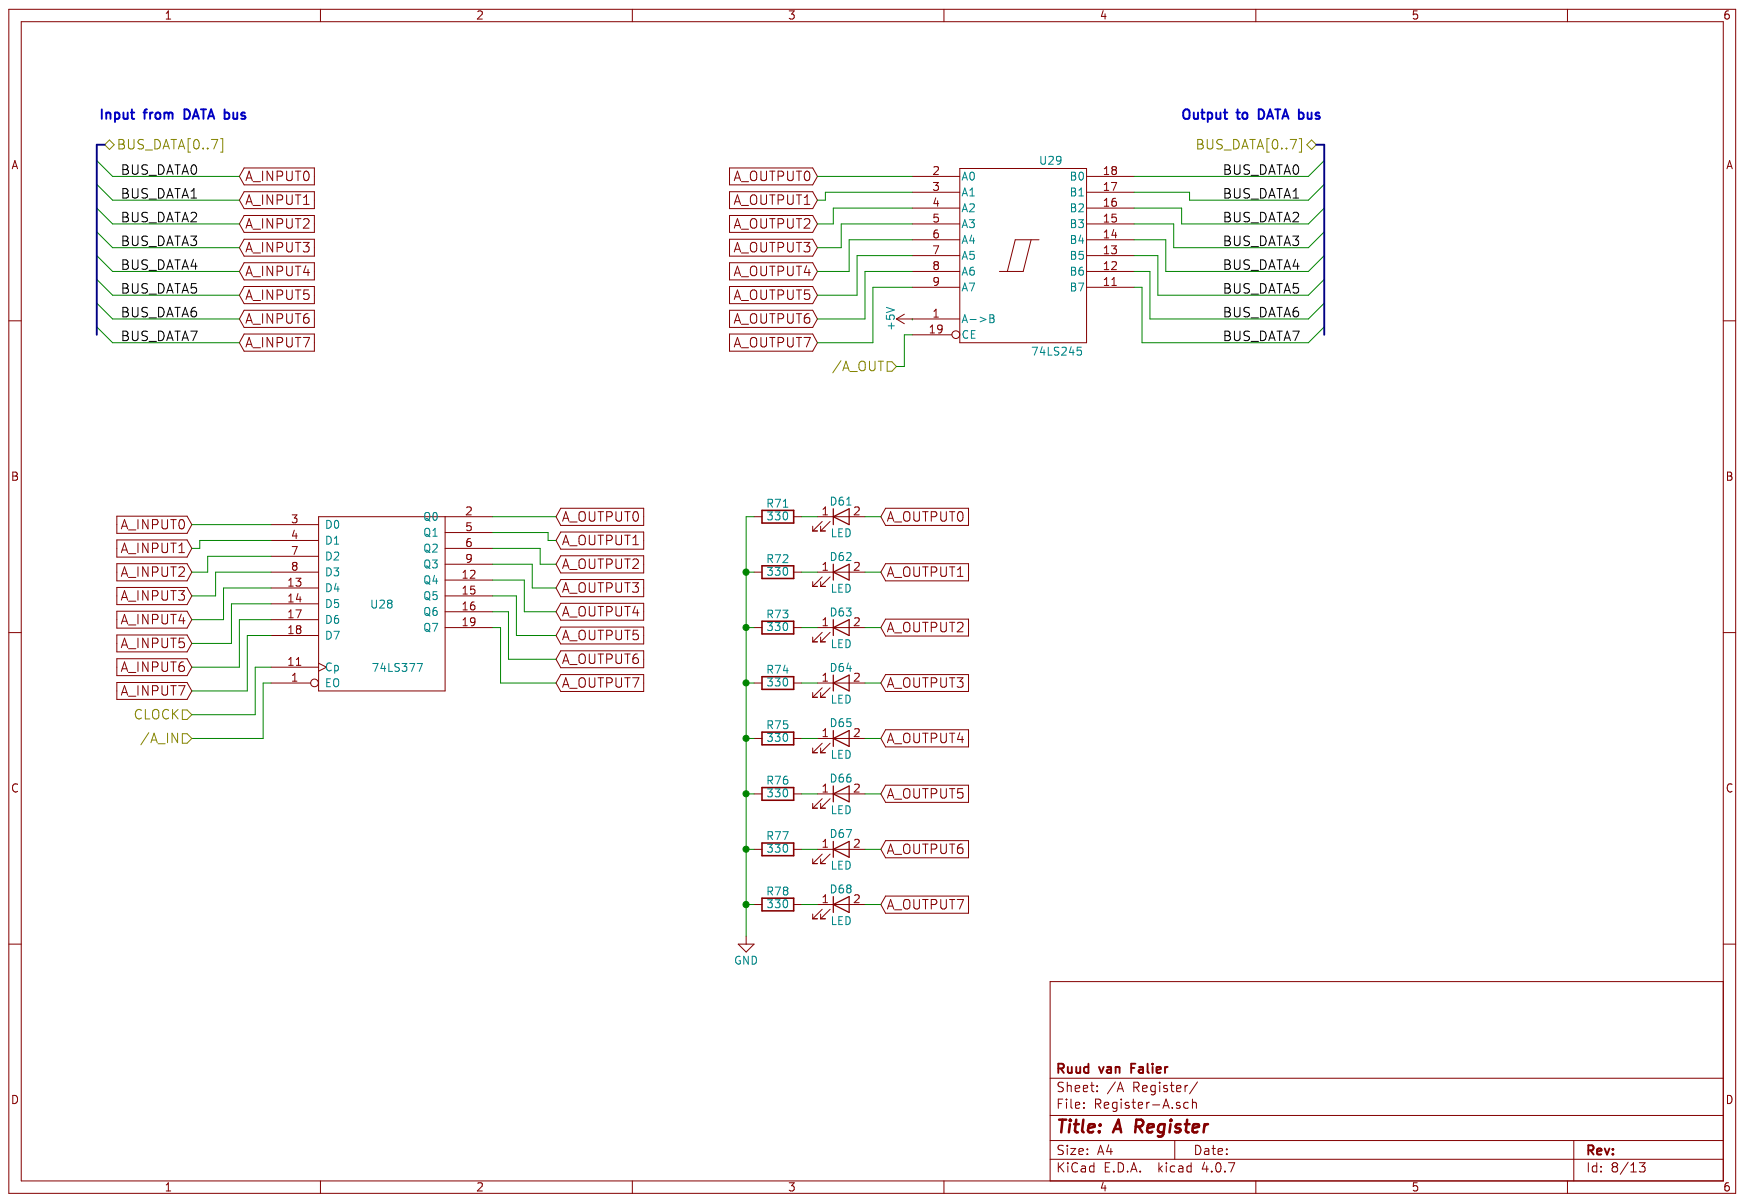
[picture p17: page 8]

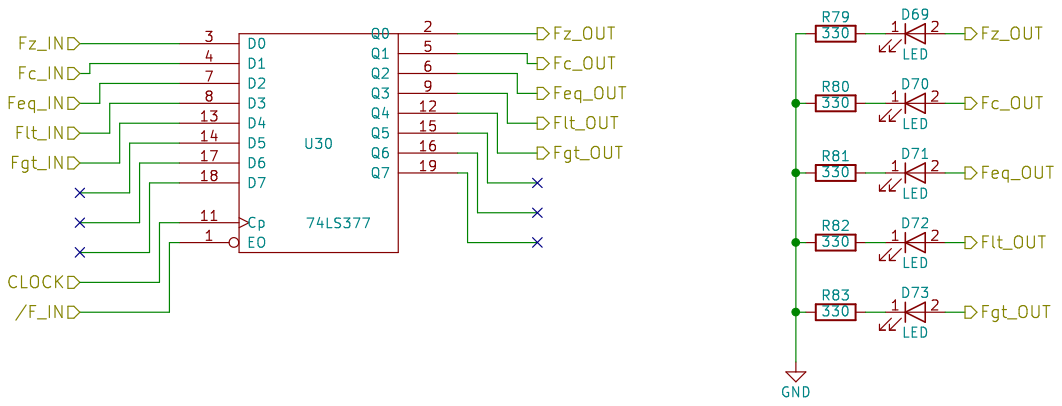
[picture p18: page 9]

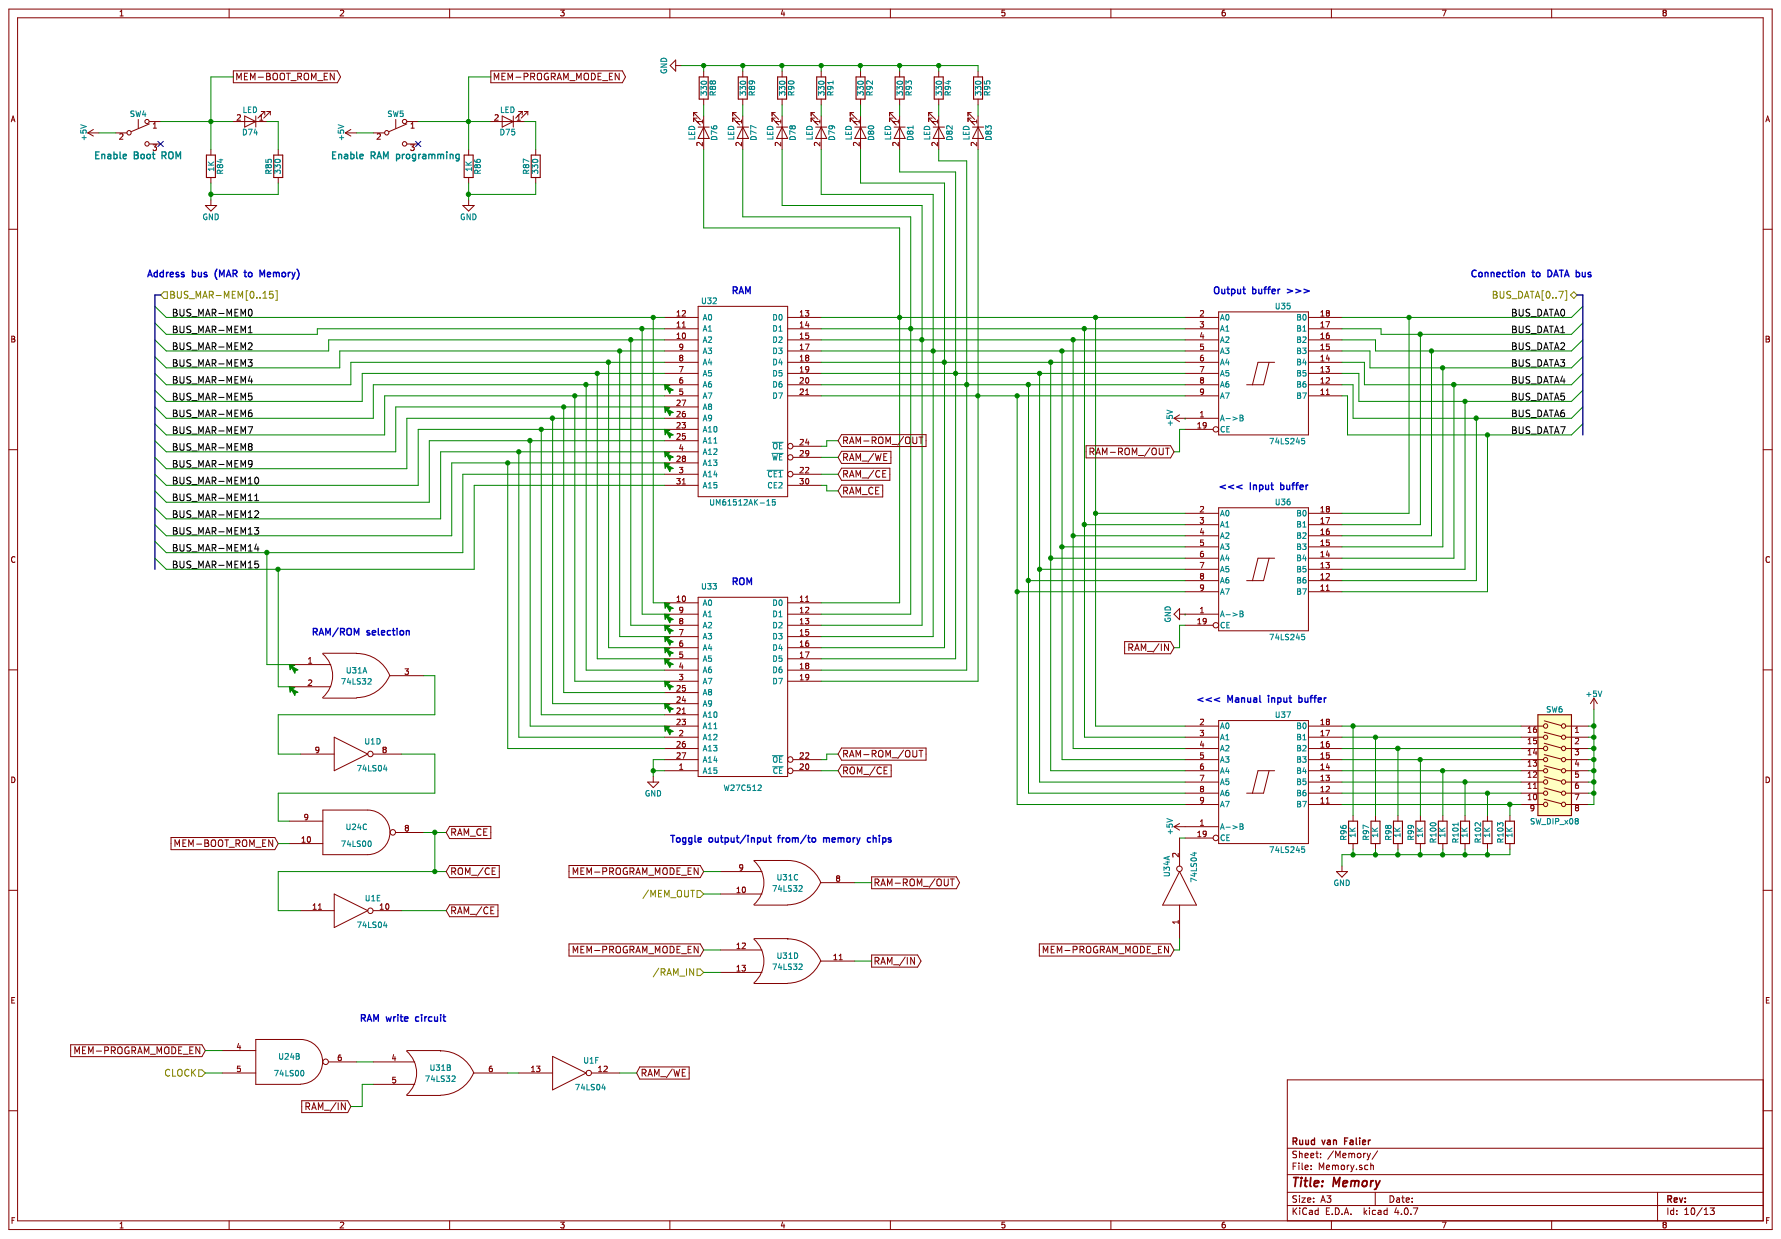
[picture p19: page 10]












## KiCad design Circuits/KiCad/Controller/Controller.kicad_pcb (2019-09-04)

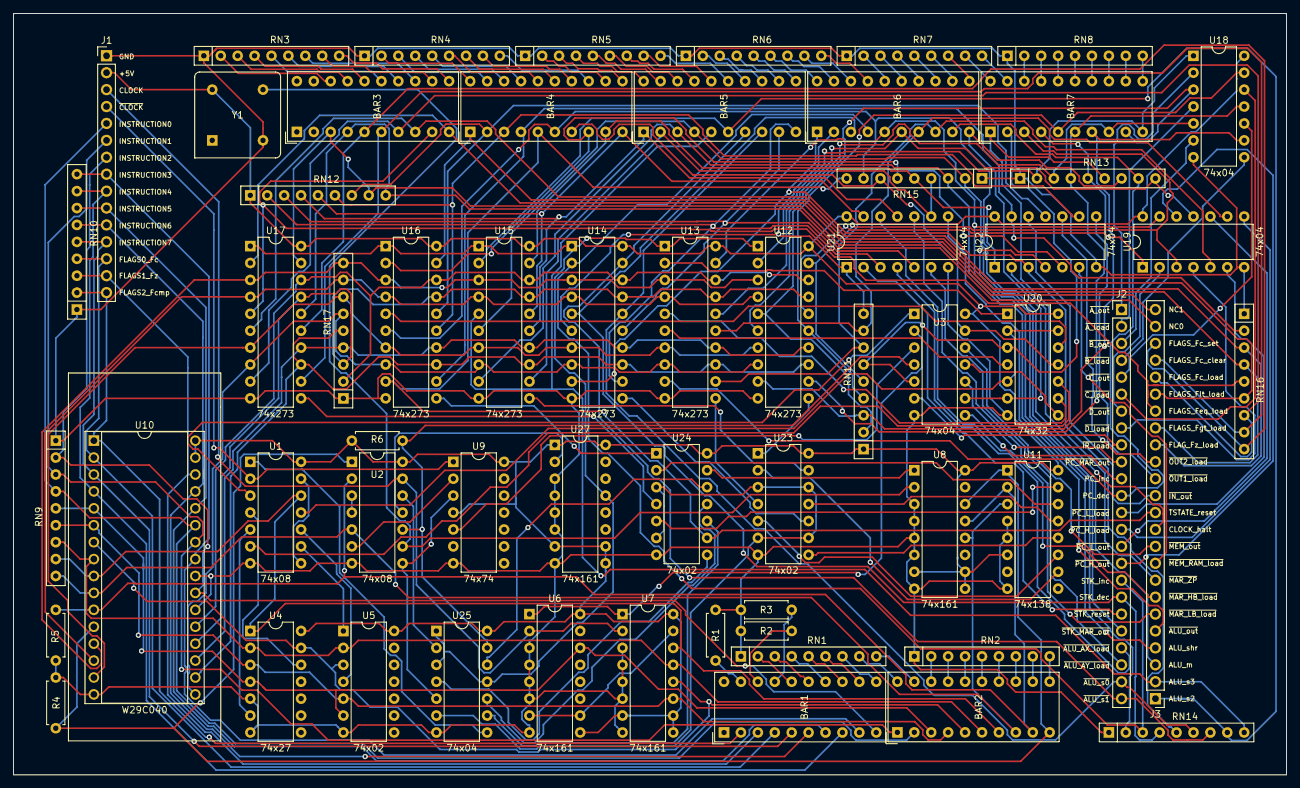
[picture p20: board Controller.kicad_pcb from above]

Board: 2 copper layers, 191.1 x 114.3 mm, 60 parts (0 on the bottom side), 216 nets.

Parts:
BAR1, BAR2, BAR3, BAR4, BAR5, BAR6, BAR7: HDSP-4830_2; Bar-Graph-10
J1: Conn_01x15_Male; PinHeader_1x15_P2.54mm_Vertical
J2, J3: Conn_01x24_Male; PinHeader_1x24_P2.54mm_Vertical
R1, R2, R4, R5: R; R_Axial_DIN0207_L6.3mm_D2.5mm_P7.62mm_Horizontal
R3: 470; R_Axial_DIN0207_L6.3mm_D2.5mm_P7.62mm_Horizontal
R6: 10K; R_Axial_DIN0207_L6.3mm_D2.5mm_P7.62mm_Horizontal
RN1, RN2, RN3, RN4, RN5, RN6, RN7, RN8: 470; R_Array_SIP9
RN9, RN10, RN11, RN12, RN13, RN14, RN15, RN16, RN17: 10K; R_Array_SIP9
U1, U2: 74x08; DIP-14_W7.62mm
U3, U18, U19, U21, U22, U25: 74x04; DIP-14_W7.62mm
U4: 74x27; DIP-14_W7.62mm
U5, U23, U24: 74x02; DIP-14_W7.62mm
U6, U7, U8, U27: 74x161; DIP-16_W7.62mm
U9: 74x74; DIP-14_W7.62mm
U10: W29C040; ZIF-32_Socket
U11: 74x138; DIP-16_W7.62mm
U12, U13, U14, U15, U16, U17: 74x273; DIP-20_W7.62mm
U20: 74x32; DIP-14_W7.62mm
Y1: 8 MHz (max. 10 MHz); Oscillator_DIP-8_v2

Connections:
+5V: J1.2, R6.1, RN11.1, RN12.1, U1.14, U2.14, U3.14, U4.14, U5.14, U6.9, U6.16, U7.7, U7.9, U7.10, U7.16, U8.7, U8.9, U8.10, U8.16, U9.4, U9.14, U10.31, U10.32, U11.6, U11.16, U12.20, U13.20, U14.20, U15.20, U16.20, U17.20, U18.14, U19.14, U20.14, U21.14, U22.14, U23.14, U24.14, U25.14, U27.1, U27.7, U27.9, U27.10, U27.16, Y1.1
ALU_AX_load: BAR5.10, RN12.2, U14.12, U21.3
ALU_AY_load: BAR5.9, RN12.3, U14.15, U21.5
ALU_m: BAR5.4, J3.3, RN15.2, U15.6
ALU_out: BAR5.2, RN15.4, U15.12, U21.9
ALU_s0: BAR5.8, J2.23, RN14.6, U14.16
ALU_s1: BAR5.7, J2.24, RN14.7, U14.19
ALU_s2: BAR5.6, J3.1, RN14.8, U15.2
ALU_s3: BAR5.5, J3.2, RN14.9, U15.5
ALU_shr: BAR5.3, J3.4, RN15.3, U15.9
A_load: BAR7.9, RN11.2, U12.5, U18.3
A_out: BAR7.10, RN13.2, U12.2, U18.1
BANK0: BAR2.10, R4.1, U2.1, U8.14, U10.12, U11.1
BANK1: BAR2.9, R5.1, U2.2, U8.13, U10.11, U11.2
BANK2: BAR2.8, RN9.9, U2.5, U8.12, U10.10, U11.3
B_load: BAR7.7, RN11.3, U12.9, U18.9
B_out: BAR7.8, RN13.3, U12.6, U18.5
CLOCK: J1.3, U2.13, U6.2, U7.2
CLOCK_INTERNAL: U2.9, U8.2, Y1.3
CLOCK_halt: BAR4.6, J3.11, RN15.8, U16.6
C_load: BAR7.5, RN11.4, U12.15, U18.13
C_out: BAR7.6, RN13.4, U12.12, U18.11
DATA0: RN17.9, U10.13, U12.3, U13.3, U14.3, U15.3, U16.3, U17.3
DATA1: RN17.8, U10.14, U12.4, U13.4, U14.4, U15.4, U16.4, U17.4
DATA2: RN17.7, U10.15, U12.7, U13.7, U14.7, U15.7, U16.7, U17.7
DATA3: RN17.6, U10.17, U12.8, U13.8, U14.8, U15.8, U16.8, U17.8
DATA4: RN17.5, U10.18, U12.13, U13.13, U14.13, U15.13, U16.13, U17.13
DATA5: RN17.4, U10.19, U12.14, U13.14, U14.14, U15.14, U16.14, U17.14
DATA6: RN17.3, U10.20, U12.17, U13.17, U14.17, U15.17, U16.17, U17.17
DATA7: RN17.2, U10.21, U12.18, U13.18, U14.18, U15.18, U16.18, U17.18
D_load: BAR7.3, RN11.5, U12.19, U19.3
D_out: BAR7.4, RN13.5, U12.16, U19.1
EN0: U11.10, U23.2
EN1: U11.11, U23.5
EN2: U11.12, U23.8
EN3: U11.13, U23.11
EN4: U11.14, U24.2
EN5: U11.15, U24.5
FLAGS0_Fc: BAR1.4, J1.13, RN10.4, U10.2
FLAGS1_Fz: BAR1.3, J1.14, RN10.3, U10.30
FLAGS2_Fcmp: BAR1.2, J1.15, RN10.2, U10.1
FLAGS_Fc_clear: BAR3.6, J3.21, RN16.8, U17.12
FLAGS_Fc_load: BAR3.7, J3.20, RN16.7, U17.9
FLAGS_Fc_set: BAR3.5, J3.22, RN16.9, U17.15
FLAGS_Feq_load: BAR3.9, J3.18, RN16.5, U17.5
FLAGS_Fgt_load: BAR3.10, J3.17, RN16.4, U17.2
FLAGS_Flt_load: BAR3.8, J3.19, RN16.6, U17.6
FLAGS_Fz_load: BAR4.1, J3.16, RN16.3, U16.19
GND: J1.1, R1.1, R2.1, R3.1, R4.2, R5.2, RN1.1, RN2.1, RN3.1, RN4.1, RN5.1, RN6.1, RN7.1, RN8.1, RN9.1, RN10.1, RN13.1, RN14.1, RN15.1, RN16.1, RN17.1, U1.7, U2.7, U3.7, U4.5, U4.7, U5.7, U6.3, U6.4, U6.5, U6.6, U6.8, U7.3, U7.4, U7.5, U7.6, U7.8, U8.3, U8.4, U8.5, U8.6, U8.8, U9.7, U10.16, U10.22, U10.24, U11.4, U11.5, U11.8, U12.10, U13.10, U14.10, U15.10, U16.10, U17.10, U18.7, U19.7, U20.7, U21.7, U22.7, U23.7, U24.7, U25.7, U27.3, U27.4, U27.5, U27.6, U27.8, Y1.2
INSTRUCTION0: BAR2.2, J1.5, RN9.4, U10.27
INSTRUCTION1: BAR2.1, J1.6, RN9.3, U10.26
INSTRUCTION2: BAR1.10, J1.7, RN9.2, U10.23
INSTRUCTION3: BAR1.9, J1.8, RN10.9, U10.25
INSTRUCTION4: BAR1.8, J1.9, RN10.8, U10.4
INSTRUCTION5: BAR1.7, J1.10, RN10.7, U10.28
INSTRUCTION6: BAR1.6, J1.11, RN10.6, U10.29
INSTRUCTION7: BAR1.5, J1.12, RN10.5, U10.3
IN_out: BAR4.4, RN16.2, U16.12, U22.13
IR_load: U13.2, U20.1
IR_load_LED: BAR7.2, RN11.6, U3.5, U20.3
MAR_HB_load: BAR4.10, RN12.5, U15.16, U21.13
MAR_LB_load: BAR5.1, RN12.4, U15.15, U21.11
MAR_ZP: BAR4.9, RN15.5, U15.19, U22.1
MEM_RAM_load: BAR4.8, RN15.6, U16.2, U22.5
MEM_out: U16.5, U20.12
MEM_out_LED: BAR4.7, RN15.7, U3.13, U20.11
NC0: BAR3.4, J3.23, RN12.9, U17.16
NC1: BAR3.3, J3.24, RN12.8, U17.19
unnamed: BAR1.11, RN1.7
unnamed: BAR1.12, RN1.6
unnamed: BAR1.13, RN1.5
unnamed: BAR1.14, RN1.4
unnamed: BAR1.15, RN1.3
unnamed: BAR1.16, RN1.2
unnamed: BAR1.17, R3.2
unnamed: BAR1.18, R2.2
unnamed: BAR1.19, R1.2
unnamed: BAR2.11, RN2.9
unnamed: BAR2.12, RN2.8
unnamed: BAR2.13, RN2.7
unnamed: BAR2.14, RN2.6
unnamed: BAR2.15, RN2.5
unnamed: BAR2.16, RN2.4
unnamed: BAR2.17, RN2.3
unnamed: BAR2.18, RN2.2
unnamed: BAR2.19, RN1.9
unnamed: BAR2.20, RN1.8
unnamed: BAR3.11, RN3.9
unnamed: BAR3.12, RN3.8
unnamed: BAR3.13, RN3.7
unnamed: BAR3.14, RN3.6
unnamed: BAR3.15, RN3.5
unnamed: BAR3.16, RN3.4
unnamed: BAR3.17, RN3.3
unnamed: BAR3.18, RN3.2
unnamed: BAR4.11, RN5.3
unnamed: BAR4.12, RN5.2
unnamed: BAR4.13, RN4.9
unnamed: BAR4.14, RN4.8
unnamed: BAR4.15, RN4.7
unnamed: BAR4.16, RN4.6
unnamed: BAR4.17, RN4.5
unnamed: BAR4.18, RN4.4
unnamed: BAR4.19, RN4.3
unnamed: BAR4.20, RN4.2
unnamed: BAR5.11, RN6.5
unnamed: BAR5.12, RN6.4
unnamed: BAR5.13, RN6.3
unnamed: BAR5.14, RN6.2
unnamed: BAR5.15, RN5.9
unnamed: BAR5.16, RN5.8
unnamed: BAR5.17, RN5.7
unnamed: BAR5.18, RN5.6
unnamed: BAR5.19, RN5.5
unnamed: BAR5.20, RN5.4
unnamed: BAR6.11, RN7.7
unnamed: BAR6.12, RN7.6
unnamed: BAR6.13, RN7.5
unnamed: BAR6.14, RN7.4
unnamed: BAR6.15, RN7.3
unnamed: BAR6.16, RN7.2
unnamed: BAR6.17, RN6.9
unnamed: BAR6.18, RN6.8
unnamed: BAR6.19, RN6.7
unnamed: BAR6.20, RN6.6
unnamed: BAR7.11, RN8.9
unnamed: BAR7.12, RN8.8
unnamed: BAR7.13, RN8.7
unnamed: BAR7.14, RN8.6
unnamed: BAR7.15, RN8.5
unnamed: BAR7.16, RN8.4
unnamed: BAR7.17, RN8.3
unnamed: BAR7.18, RN8.2
unnamed: BAR7.19, RN7.9
unnamed: BAR7.20, RN7.8
unnamed: U1.1, U25.8
unnamed: U1.3, U3.1
unnamed: U1.4, U4.12
unnamed: U1.5, U4.6
unnamed: U1.9, U5.1
unnamed: U1.10, U5.4
unnamed: U1.8, U1.13
unnamed: U2.3, U2.4
unnamed: U2.6, U9.2
unnamed: U2.8, U9.3, U25.5
unnamed: U2.11, U27.2
unnamed: U2.12, U25.2
unnamed: U3.2, U6.1, U7.1
unnamed: U3.3, U9.5
unnamed: U6.7, U6.10, U7.15
unnamed: U12.11, U23.1
unnamed: U13.11, U23.4
unnamed: U14.11, U23.10
unnamed: U15.11, U23.13
unnamed: U16.11, U24.1
unnamed: U17.11, U24.4
unnamed: U23.3, U23.6, U23.9, U23.12, U24.3, U24.6, U25.6
unnamed: U24.8, U25.4
unnamed: U24.10, U25.9
unnamed: U24.11, U25.10
unnamed: U24.12, U25.12
unnamed: U8.1, U24.13
OUT1_load: BAR4.3, RN12.6, U16.15, U22.9
OUT2_load: BAR4.2, RN12.7, U16.16, U22.11
PC_H_load: BAR6.7, RN11.8, U13.15, U19.9
PC_H_out: BAR6.5, RN14.2, U13.19, U19.13
PC_L_load: BAR6.8, RN11.7, U13.12, U19.5
PC_L_out: BAR6.6, RN13.9, U13.16, U19.11
PC_MAR_out: U13.5, U20.9
PC_MAR_out_LED: BAR7.1, RN13.6, U3.11, U20.8
PC_dec: BAR6.9, J2.12, RN13.8, U13.9
PC_inc: J2.11, U3.8
PC_inc_: U13.6, U20.4
PC_inc_LED: BAR6.10, RN13.7, U3.9, U20.6
RUNNING: U12.1, U13.1, U14.1, U15.1, U16.1, U17.1, U25.1, U25.3, U25.11, U27.13
STK_MAR_out: BAR6.1, RN14.5, U14.9, U22.3
STK_dec: BAR6.3, J2.18, RN14.4, U14.5
STK_inc: BAR6.4, J2.17, RN14.3, U14.2
STK_reset: BAR6.2, RN11.9, U14.6, U21.1
TSTATE0: BAR2.7, RN9.8, U1.12, U4.1, U7.14, U10.9
TSTATE1: BAR2.6, RN9.7, U4.2, U5.2, U7.13, U10.8
TSTATE2: BAR2.5, U4.13, U5.3, U7.12, U10.7
TSTATE3: BAR2.4, RN9.6, U4.3, U5.5, U7.11, U10.6
TSTATE4: BAR2.3, RN9.5, U4.4, U5.6, U6.14, U10.5
TSTATE=0: U1.6, U20.10
TSTATE=1: U1.11, U20.2, U20.5, U20.13
TSTATE_reset: BAR4.5, J3.12, RN15.9, U16.9, U24.9
~ALU_AX_load: J2.21, U21.4
~ALU_AY_load: J2.22, U21.6
~ALU_out: J3.5, U21.8
~A_load: J2.2, U18.4
~A_out: J2.1, U18.2
~B_load: J2.4, U18.8
~B_out: J2.3, U18.6
~CLOCK: J1.4, U1.2, U9.1
~C_load: J2.6, U18.12
~C_out: J2.5, U18.10
~D_load: J2.8, U19.4
~D_out: J2.7, U19.2
~IN_out: J3.13, U22.12
~IR_load: J2.9, U3.6
~LOAD_DONE: R6.2, U2.10, U3.4, U25.13
~MAR_HB_load: J3.7, U21.12
~MAR_LB_load: J3.6, U21.10
~MAR_ZP: J3.8, U22.2
~MEM_RAM_load: J3.9, U22.6
~MEM_out: J3.10, U3.12
~OUT1_load: J3.14, U22.8
~OUT2_load: J3.15, U22.10
~PC_H_load: J2.14, U19.8
~PC_H_out: J2.16, U19.12
~PC_L_load: J2.13, U19.6
~PC_L_out: J2.15, U19.10
~PC_MAR_out: J2.10, U3.10
~STK_MAR_out: J2.20, U22.4
~STK_reset: J2.19, U21.2

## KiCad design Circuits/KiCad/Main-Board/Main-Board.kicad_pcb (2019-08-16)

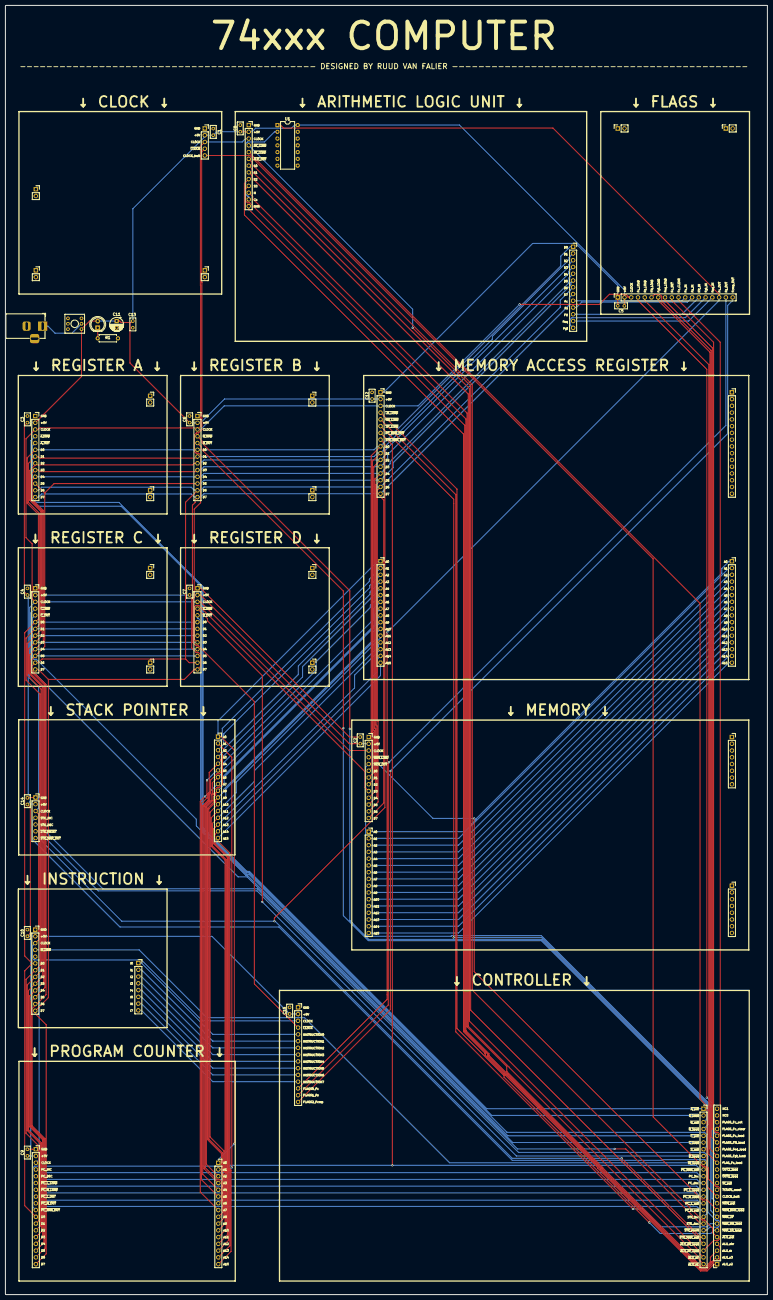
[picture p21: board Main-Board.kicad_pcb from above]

Board: 2 copper layers, 286.4 x 484.5 mm, 58 parts (0 on the bottom side), 105 nets.

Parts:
C1, C2, C3, C4, C5, C6, C7, C8, C9, C10, C12, C13, C14, C15: 100 nF; C_Rect_L4.6mm_W2.0mm_P2.50mm_MKS02_FKP02
C11: 100 uF; CP_Radial_D5.0mm_P2.50mm
D1: LED; LED_D5.0mm
J1: CLOCK; PinSocket_1x05_P2.54mm_Vertical
J2: MEMORY_0; PinSocket_1x13_P2.54mm_Vertical
J3: REGISTER-A; PinSocket_1x13_P2.54mm_Vertical
J4: REGISTER-C; PinSocket_1x13_P2.54mm_Vertical
J5: FLAGS-REGISTER; PinSocket_1x18_P2.54mm_Vertical
J6: MEMORY_1; PinSocket_1x16_P2.54mm_Vertical
J7: REGISTER-B; PinSocket_1x13_P2.54mm_Vertical
J8: REGISTER-D; PinSocket_1x13_P2.54mm_Vertical
J9: PROGRAM-COUNTER_0; PinSocket_1x18_P2.54mm_Vertical
J10: ALU_0; PinSocket_1x13_P2.54mm_Vertical
J11: ALU_1; PinSocket_1x13_P2.54mm_Vertical
J12: IR_0; PinSocket_1x13_P2.54mm_Vertical
J13: MAR_0; PinSocket_1x16_P2.54mm_Vertical
J14: PROGRAM-COUNTER_1; PinSocket_1x16_P2.54mm_Vertical
J15: IR_1; PinSocket_1x08_P2.54mm_Vertical
J16: SP_0; PinSocket_1x07_P2.54mm_Vertical
J17: MAR_1_ADDRESS-IN; PinSocket_1x16_P2.54mm_Vertical
J18: SP_1_MEMORY-ADDRESS; PinSocket_1x16_P2.54mm_Vertical
J19: MAR_2_ADDRESS-OUT; PinSocket_1x16_P2.54mm_Vertical
J20: CONTROLLER_0; PinSocket_1x15_P2.54mm_Vertical
J21: CONTROLLER_1; PinSocket_1x24_P2.54mm_Vertical
J22: CONTROLLER_2; PinSocket_1x24_P2.54mm_Vertical
J23: Barrel_Jack; BarrelJack_Horizontal
J24: CLOCK_1; PinSocket_1x02_P2.54mm_Vertical
J25: CLOCK_2; PinSocket_1x02_P2.54mm_Vertical
J26: CLOCK_3; PinSocket_1x02_P2.54mm_Vertical
J27: FLAGS-REGISTER_1; PinSocket_1x02_P2.54mm_Vertical
J28: FLAGS-REGISTER_2; PinSocket_1x02_P2.54mm_Vertical
J29: MEMORY_2; PinSocket_1x08_P2.54mm_Vertical
J30: MEMORY_3; PinSocket_1x08_P2.54mm_Vertical
J31: MAR_3; PinSocket_1x16_P2.54mm_Vertical
J32: REGISTER-A_1; PinSocket_1x02_P2.54mm_Vertical
J33: REGISTER-A_2; PinSocket_1x02_P2.54mm_Vertical
J34: REGISTER-C_1; PinSocket_1x02_P2.54mm_Vertical
J35: REGISTER-C_2; PinSocket_1x02_P2.54mm_Vertical
J36: REGISTER-B_1; PinSocket_1x02_P2.54mm_Vertical
J37: REGISTER-B_2; PinSocket_1x02_P2.54mm_Vertical
J38: REGISTER-D_1; PinSocket_1x02_P2.54mm_Vertical
J39: REGISTER-D_2; PinSocket_1x02_P2.54mm_Vertical
R1: 470; R_Axial_DIN0207_L6.3mm_D2.5mm_P7.62mm_Horizontal
SW1: SW_Push_SPDT; Switch
U1: 74x04; DIP-14_W7.62mm

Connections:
+5V: C1.2, C2.2, C3.2, C4.2, C5.2, C6.2, C7.2, C8.2, C9.2, C10.2, C11.1, C12.2, C13.1, C14.2, C15.2, D1.2, J1.2, J2.2, J3.2, J4.2, J5.2, J7.2, J8.2, J9.2, J10.2, J12.2, J13.2, J16.2, J20.2, SW1.3, U1.14
A0: J14.1, J17.1, J18.1
A1: J14.2, J17.2, J18.2
A2: J14.3, J17.3, J18.3
A3: J14.4, J17.4, J18.4
A4: J14.5, J17.5, J18.5
A5: J14.6, J17.6, J18.6
A6: J14.7, J17.7, J18.7
A7: J14.8, J17.8, J18.8
A8: J14.9, J17.9, J18.9
A9: J14.10, J17.10, J18.10
A10: J14.11, J17.11, J18.11
A11: J14.12, J17.12, J18.12
A12: J14.13, J17.13, J18.13
A13: J14.14, J17.14, J18.14
A14: J14.15, J17.15, J18.15
A15: J14.16, J17.16, J18.16
ALU_Cn: J10.12, U1.2
ALU_m: J10.11, J22.3
ALU_s0: J10.7, J21.23
ALU_s1: J10.8, J21.24
ALU_s2: J10.9, J22.1
ALU_s3: J10.10, J22.2
ALU_shr: J10.13, J22.4
CLOCK: J1.3, J2.3, J3.3, J4.3, J5.3, J7.3, J8.3, J9.3, J10.3, J12.3, J13.3, J16.3, J20.3
CLOCK_halt: J1.5, J22.11
DATA_BUS0: J2.6, J3.6, J4.6, J7.6, J8.6, J9.11, J11.1, J12.6, J13.9
DATA_BUS1: J2.7, J3.7, J4.7, J7.7, J8.7, J9.12, J11.2, J12.7, J13.10
DATA_BUS2: J2.8, J3.8, J4.8, J7.8, J8.8, J9.13, J11.3, J12.8, J13.11
DATA_BUS3: J2.9, J3.9, J4.9, J7.9, J8.9, J9.14, J11.4, J12.9, J13.12
DATA_BUS4: J2.10, J3.10, J4.10, J7.10, J8.10, J9.15, J11.5, J12.10, J13.13
DATA_BUS5: J2.11, J3.11, J4.11, J7.11, J8.11, J9.16, J11.6, J12.11, J13.14
DATA_BUS6: J2.12, J3.12, J4.12, J7.12, J8.12, J9.17, J11.7, J12.12, J13.15
DATA_BUS7: J2.13, J3.13, J4.13, J7.13, J8.13, J9.18, J11.8, J12.13, J13.16
FLAGS_Fc_clear: J5.10, J22.21
FLAGS_Fc_load: J5.4, J22.20
FLAGS_Fc_set: J5.9, J22.22
FLAGS_Feq_load: J5.8, J22.18
FLAGS_Fgt_load: J5.7, J22.17
FLAGS_Flt_load: J5.6, J22.19
FLAGS_Fz_load: J5.5, J22.16
Fc_in: J5.11, J11.9
Fc_out: J5.16, J20.13, U1.1
Fcmp_out: J5.18, J20.15
Feq_in: J5.15, J11.12
Fgt_in: J5.14, J11.13
Flt_in: J5.13, J11.11
Fz_in: J5.12, J11.10
Fz_out: J5.17, J20.14
GND: C1.1, C2.1, C3.1, C4.1, C5.1, C6.1, C7.1, C8.1, C9.1, C10.1, C11.2, C12.1, C13.2, C14.1, C15.1, J1.1, J2.1, J3.1, J4.1, J5.1, J7.1, J8.1, J9.1, J10.1, J12.1, J13.1, J16.1, J20.1, J23.2, R1.2, U1.7
INSTRUCTION0: J15.1, J20.5
INSTRUCTION1: J15.2, J20.6
INSTRUCTION2: J15.3, J20.7
INSTRUCTION3: J15.4, J20.8
INSTRUCTION4: J15.5, J20.9
INSTRUCTION5: J15.6, J20.10
INSTRUCTION6: J15.7, J20.11
INSTRUCTION7: J15.8, J20.12
MAR0: J6.1, J19.1
MAR1: J6.2, J19.2
MAR2: J6.3, J19.3
MAR3: J6.4, J19.4
MAR4: J6.5, J19.5
MAR5: J6.6, J19.6
MAR6: J6.7, J19.7
MAR7: J6.8, J19.8
MAR8: J6.9, J19.9
MAR9: J6.10, J19.10
MAR10: J6.11, J19.11
MAR11: J6.12, J19.12
MAR12: J6.13, J19.13
MAR13: J6.14, J19.14
MAR14: J6.15, J19.15
MAR15: J6.16, J19.16
unnamed: D1.1, R1.1
unnamed: J23.1, SW1.2
PC_dec: J9.5, J21.12
PC_inc: J9.4, J21.11
STK_dec: J16.5, J21.18
STK_inc: J16.4, J21.17
~ALU_AX_load: J10.4, J21.21
~ALU_AY_load: J10.5, J21.22
~ALU_out: J10.6, J22.5
~A_load: J3.4, J21.2
~A_out: J3.5, J21.1
~B_load: J7.4, J21.4
~B_out: J7.5, J21.3
~CLOCK: J1.4, J20.4
~C_load: J4.4, J21.6
~C_out: J4.5, J21.5
~D_load: J8.4, J21.8
~D_out: J8.5, J21.7
~IR_load: J12.4, J21.9
~MAR_HB_load: J13.5, J22.7
~MAR_LB_load: J13.4, J22.6
~MAR_ZP: J13.6, J22.8
~MEM_RAM_load: J2.4, J22.9
~MEM_out: J2.5, J22.10
~PC_H_load: J9.7, J21.14
~PC_H_out: J9.9, J21.16
~PC_L_load: J9.6, J21.13
~PC_L_out: J9.8, J21.15
~PC_MAR_out: J9.10, J13.7, J21.10
~STK_MAR_out: J13.8, J16.7, J21.20
~STK_reset: J16.6, J21.19

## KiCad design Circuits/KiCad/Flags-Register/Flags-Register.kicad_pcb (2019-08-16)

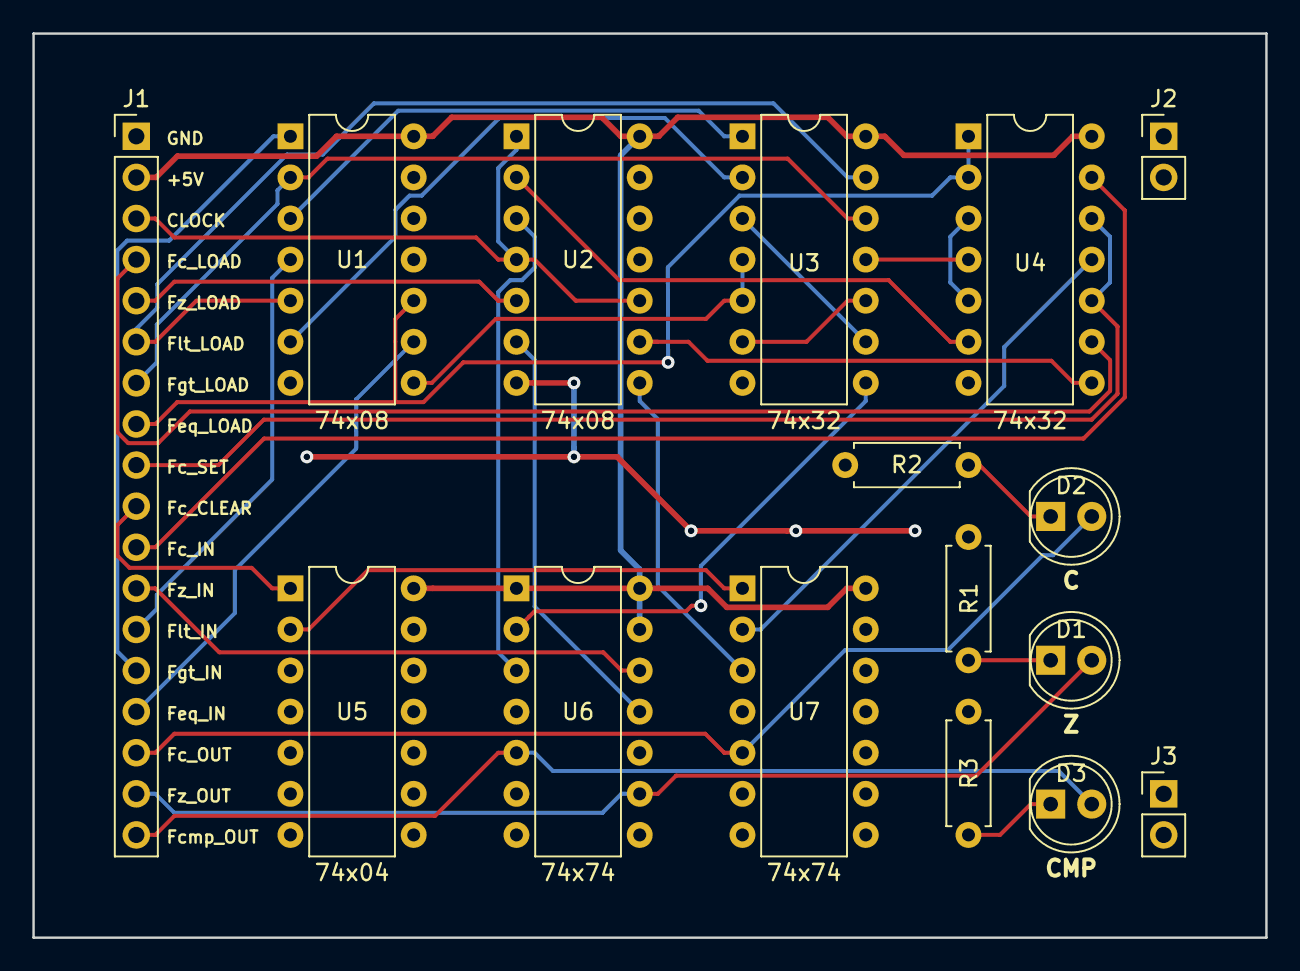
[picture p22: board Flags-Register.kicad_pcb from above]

Board: 2 copper layers, 76.2 x 55.9 mm, 16 parts (0 on the bottom side), 36 nets.

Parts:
D1: Z; LED_D5.0mm
D2: C; LED_D5.0mm
D3: CMP; LED_D5.0mm
J1: Conn_01x18_Male; PinHeader_1x18_P2.54mm_Vertical
J2, J3: Conn_01x02_Male; PinHeader_1x02_P2.54mm_Vertical
R1, R2, R3: 470; R_Axial_DIN0207_L6.3mm_D2.5mm_P7.62mm_Horizontal
U1, U2: 74x08; DIP-14_W7.62mm
U3, U4: 74x32; DIP-14_W7.62mm
U5: 74x04; DIP-14_W7.62mm
U6, U7: 74x74; DIP-14_W7.62mm

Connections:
+5V: J1.2, U1.14, U2.14, U3.14, U4.14, U5.14, U6.1, U6.13, U6.14, U7.14
CLOCK: J1.3, U2.1, U2.4, U2.10
Fc_CLEAR: J1.10, U5.1
Fc_IN: J1.11, U4.13
Fc_LOAD: J1.4, U4.9
Fc_OUT: D2.2, J1.16, U7.5
Fc_SET: J1.9, U4.10, U4.12
Fcmp_OUT: D3.2, J1.18, U6.5
Feq_IN: J1.15, U1.9
Feq_LOAD: J1.8, U1.10, U4.1, U4.2
Fgt_IN: J1.14, U1.1
Fgt_LOAD: J1.7, U1.2, U3.12
Flt_IN: J1.13, U1.4
Flt_LOAD: J1.6, U1.5, U3.13
Fz_IN: J1.12, U6.12
Fz_LOAD: J1.5, U2.5
Fz_OUT: D1.2, J1.17, U6.9
GND: J1.1, R1.2, R2.2, R3.2, U1.7, U2.7, U3.7, U4.7, U5.7, U6.7, U7.7
unnamed: D1.1, R1.1
unnamed: D2.1, R2.1
unnamed: D3.1, R3.1
unnamed: U1.3, U3.1
unnamed: U1.6, U3.2
unnamed: U1.8, U3.4, U3.5
unnamed: U2.2, U4.6
unnamed: U2.3, U6.3
unnamed: U2.6, U6.11
unnamed: U2.8, U7.3
unnamed: U2.9, U4.8
unnamed: U3.3, U3.9
unnamed: U3.8, U6.2
unnamed: U3.6, U3.10
unnamed: U3.11, U4.4
unnamed: U4.3, U4.5
unnamed: U4.11, U7.2
unnamed: U5.2, U7.1

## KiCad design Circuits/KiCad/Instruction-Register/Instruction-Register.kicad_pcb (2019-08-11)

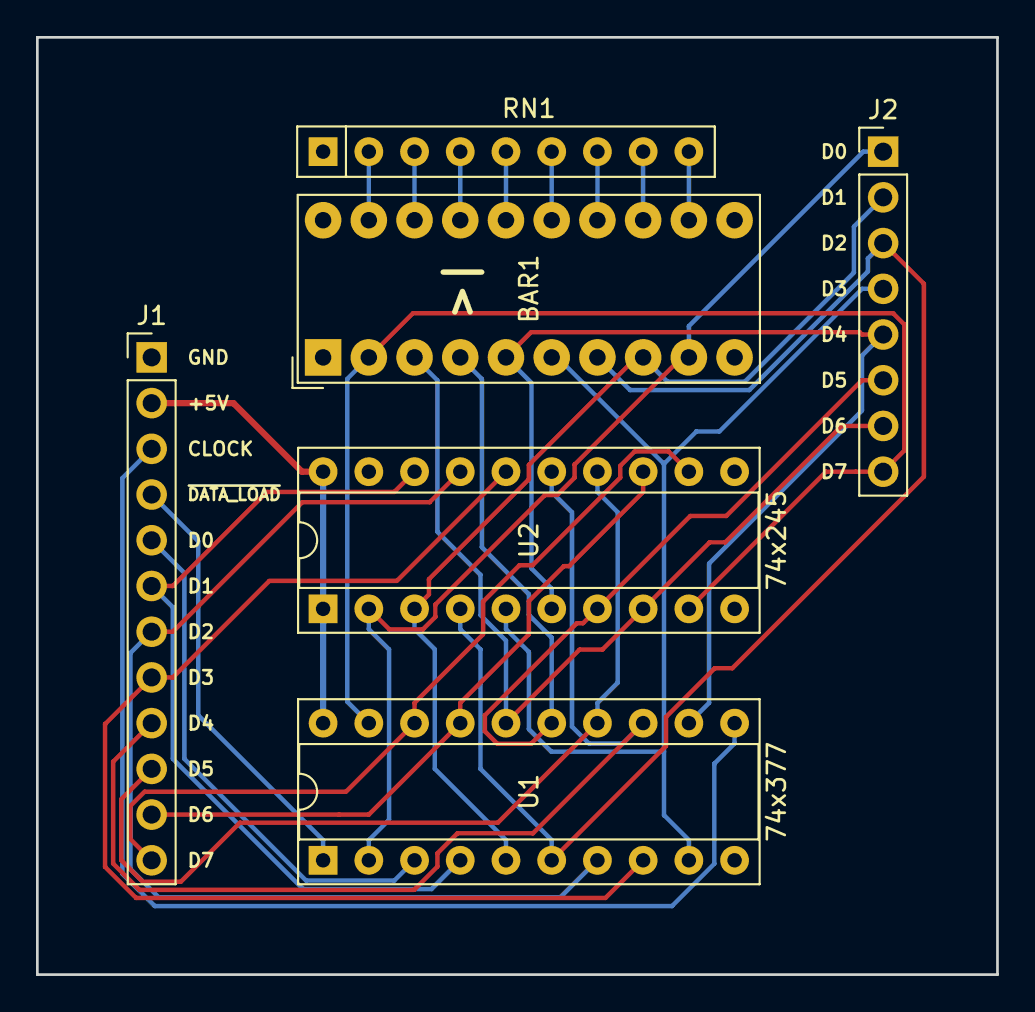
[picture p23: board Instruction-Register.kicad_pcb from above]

Board: 2 copper layers, 53.3 x 52.1 mm, 6 parts (0 on the bottom side), 28 nets.

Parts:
BAR1: LED-BAR; HDSP-4830
J1: Conn_01x12_Male; PinHeader_1x12_P2.54mm_Vertical
J2: Conn_01x08_Male; PinHeader_1x08_P2.54mm_Vertical
RN1: 470; R_Array_SIP9
U1: 74x377; DIP-20_W7.62mm_Socket
U2: 74x245; DIP-20_W7.62mm_Socket

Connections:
+5V: J1.2, U1.20, U2.1, U2.20
CLOCK: J1.3, U1.11
GND: J1.1, RN1.1, U1.10, U2.10
unnamed: BAR1.2, J2.8, U1.19, U2.9
unnamed: BAR1.3, J2.7, U1.16, U2.8
unnamed: BAR1.4, J2.6, U1.15, U2.7
unnamed: BAR1.5, J2.5, U1.12, U2.6
unnamed: BAR1.6, J2.4, U1.9, U2.5
unnamed: BAR1.7, J2.3, U1.6, U2.4
unnamed: BAR1.8, J2.2, U1.5, U2.3
unnamed: BAR1.9, J2.1, U1.2, U2.2
unnamed: BAR1.12, RN1.9
unnamed: BAR1.13, RN1.8
unnamed: BAR1.14, RN1.7
unnamed: BAR1.15, RN1.6
unnamed: BAR1.16, RN1.5
unnamed: BAR1.17, RN1.4
unnamed: BAR1.18, RN1.3
unnamed: BAR1.19, RN1.2
unnamed: J1.5, U1.3
unnamed: J1.6, U1.4, U2.18
unnamed: J1.7, U1.7, U2.17
unnamed: J1.8, U1.8, U2.16
unnamed: J1.9, U1.13, U2.15
unnamed: J1.10, U1.14, U2.14
unnamed: J1.11, U1.17, U2.13
unnamed: J1.12, U1.18, U2.12
~DATA_LOAD: J1.4, U1.1

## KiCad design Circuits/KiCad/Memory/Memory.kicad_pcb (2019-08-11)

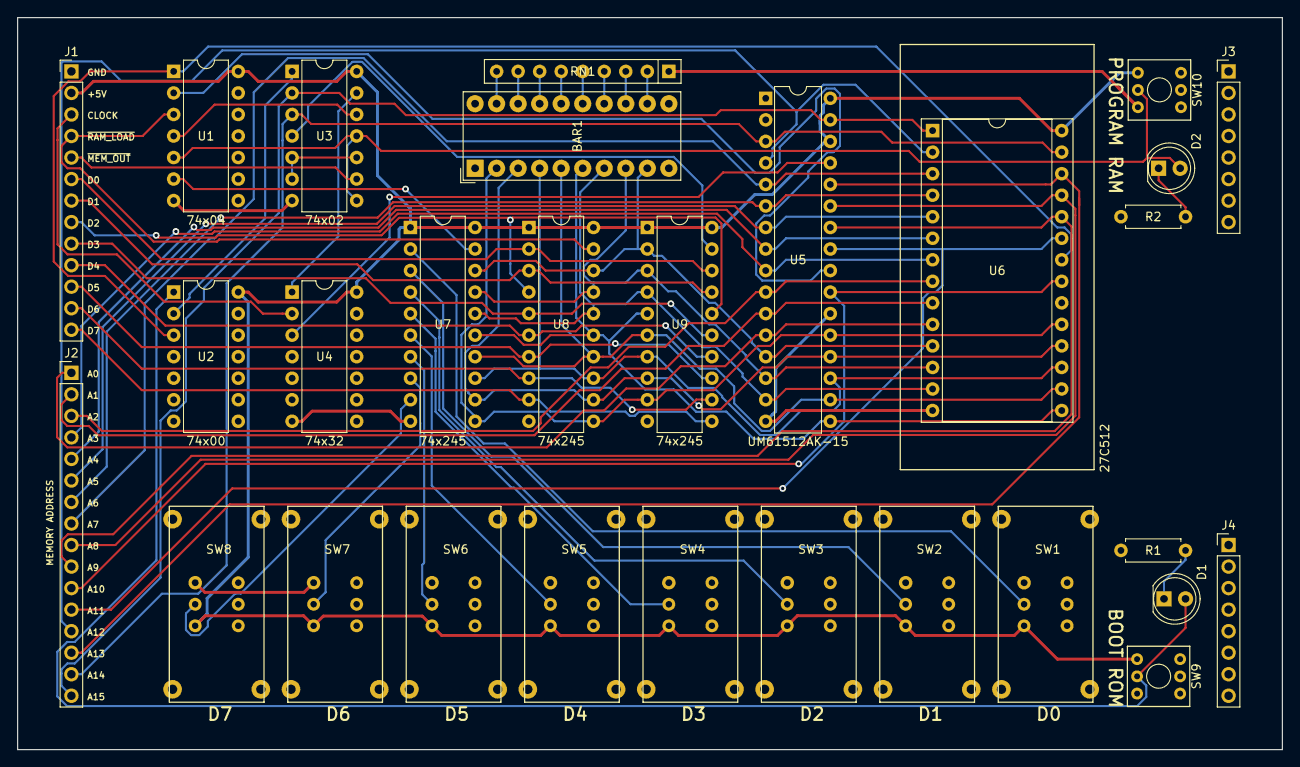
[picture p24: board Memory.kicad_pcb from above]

Board: 2 copper layers, 149.2 x 86.4 mm, 29 parts (0 on the bottom side), 66 nets.

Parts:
BAR1: HDSP-4830_2; HDSP-4830
D1, D2: LED; LED_D5.0mm
J1: Conn_01x13_Male; PinHeader_1x13_P2.54mm_Vertical
J2: Conn_01x16_Male; PinHeader_1x16_P2.54mm_Vertical
J3, J4: Conn_01x08_Male; PinHeader_1x08_P2.54mm_Vertical
R1, R2: 470; R_Axial_DIN0207_L6.3mm_D2.5mm_P7.62mm_Horizontal
RN1: 470; R_Array_SIP9
SW1, SW2, SW3, SW4, SW5, SW6, SW7, SW8: SW_DPDT_x2; FlipSwitch
SW9, SW10: SW_DPDT_x2; Switch
U1: 74x04; DIP-14_W7.62mm
U2: 74x00; DIP-14_W7.62mm
U3: 74x02; DIP-14_W7.62mm
U4: 74x32; DIP-14_W7.62mm
U5: UM61512AK-15; DIP-32_W7.62mm
U6: 27C512; ZIF-28_Socket
U7, U8, U9: 74x245; DIP-20_W7.62mm

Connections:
+5V: J1.2, SW1.3, SW2.3, SW3.3, SW4.3, SW5.3, SW6.3, SW7.3, SW8.3, SW9.3, SW10.3, U1.14, U2.14, U3.14, U4.14, U5.30, U5.32, U6.28, U7.1, U7.20, U8.1, U8.20, U9.1, U9.20
BOOT_ROM: D1.2, SW9.2, U2.1
CLOCK: J1.3, U4.2
DATA_BUS0: J1.6, U8.2, U9.18
DATA_BUS1: J1.7, U8.3, U9.17
DATA_BUS2: J1.8, U8.4, U9.16
DATA_BUS3: J1.9, U8.5, U9.15
DATA_BUS4: J1.10, U8.6, U9.14
DATA_BUS5: J1.11, U8.7, U9.13
DATA_BUS6: J1.12, U8.8, U9.12
DATA_BUS7: J1.13, U8.9, U9.11
GND: J1.1, R1.1, R2.1, RN1.1, SW1.1, SW2.1, SW3.1, SW4.1, SW5.1, SW6.1, SW7.1, SW8.1, SW9.1, SW10.1, U1.7, U2.7, U3.7, U4.7, U5.16, U5.22, U6.14, U6.20, U7.10, U8.10, U9.10
MANUAL_D0: SW1.2, U7.2
MANUAL_D1: SW2.2, U7.3
MANUAL_D2: SW3.2, U7.4
MANUAL_D3: SW4.2, U7.5
MANUAL_D4: SW5.2, U7.6
MANUAL_D5: SW6.2, U7.7
MANUAL_D6: SW7.2, U7.8
MANUAL_D7: SW8.2, U7.9
unnamed: BAR1.2, U5.21, U6.19, U7.11, U8.11, U9.9
unnamed: BAR1.3, U5.20, U6.18, U7.12, U8.12, U9.8
unnamed: BAR1.4, U5.19, U6.17, U7.13, U8.13, U9.7
unnamed: BAR1.5, U5.18, U6.16, U7.14, U8.14, U9.6
unnamed: BAR1.6, U5.17, U6.15, U7.15, U8.15, U9.5
unnamed: BAR1.7, U5.15, U6.13, U7.16, U8.16, U9.4
unnamed: BAR1.8, U5.14, U6.12, U7.17, U8.17, U9.3
unnamed: BAR1.9, U5.13, U6.11, U7.18, U8.18, U9.2
unnamed: BAR1.12, RN1.2
unnamed: BAR1.13, RN1.3
unnamed: BAR1.14, RN1.4
unnamed: BAR1.15, RN1.5
unnamed: BAR1.16, RN1.6
unnamed: BAR1.17, RN1.7
unnamed: BAR1.18, RN1.8
unnamed: BAR1.19, RN1.9
unnamed: D1.1, R1.2
unnamed: D2.1, R2.2
unnamed: J2.1, U5.12, U6.10
unnamed: J2.2, U5.11, U6.9
unnamed: J2.3, U5.10, U6.8
unnamed: J2.4, U5.9, U6.7
unnamed: J2.5, U5.8, U6.6
unnamed: J2.6, U5.7, U6.5
unnamed: J2.7, U5.6, U6.4
unnamed: J2.8, U5.5, U6.3
unnamed: J2.9, U5.27, U6.25
unnamed: J2.10, U5.26, U6.24
unnamed: J2.11, U5.23, U6.21
unnamed: J2.12, U5.25, U6.23
unnamed: J2.13, U5.4, U6.2
unnamed: J2.14, U5.28, U6.26
unnamed: J2.15, U3.3, U5.3, U6.27
unnamed: J2.16, U3.2, U5.31, U6.1
unnamed: U1.4, U3.12
unnamed: U1.6, U7.19
unnamed: U2.2, U3.1
unnamed: U3.5, U3.6, U3.10
unnamed: U3.13, U4.1
PROGRAM_RAM: D2.2, SW10.2, U1.5, U3.8, U3.11
~DATA_OUT: U3.4, U9.19
~MEM_OUT: J1.5, U3.9
~RAM_LOAD: J1.4, U1.3, U8.19
~RAM_OE: U1.2, U5.24
~RAM_WE: U4.3, U5.29
~ROM_OE: U1.1, U2.3, U6.22

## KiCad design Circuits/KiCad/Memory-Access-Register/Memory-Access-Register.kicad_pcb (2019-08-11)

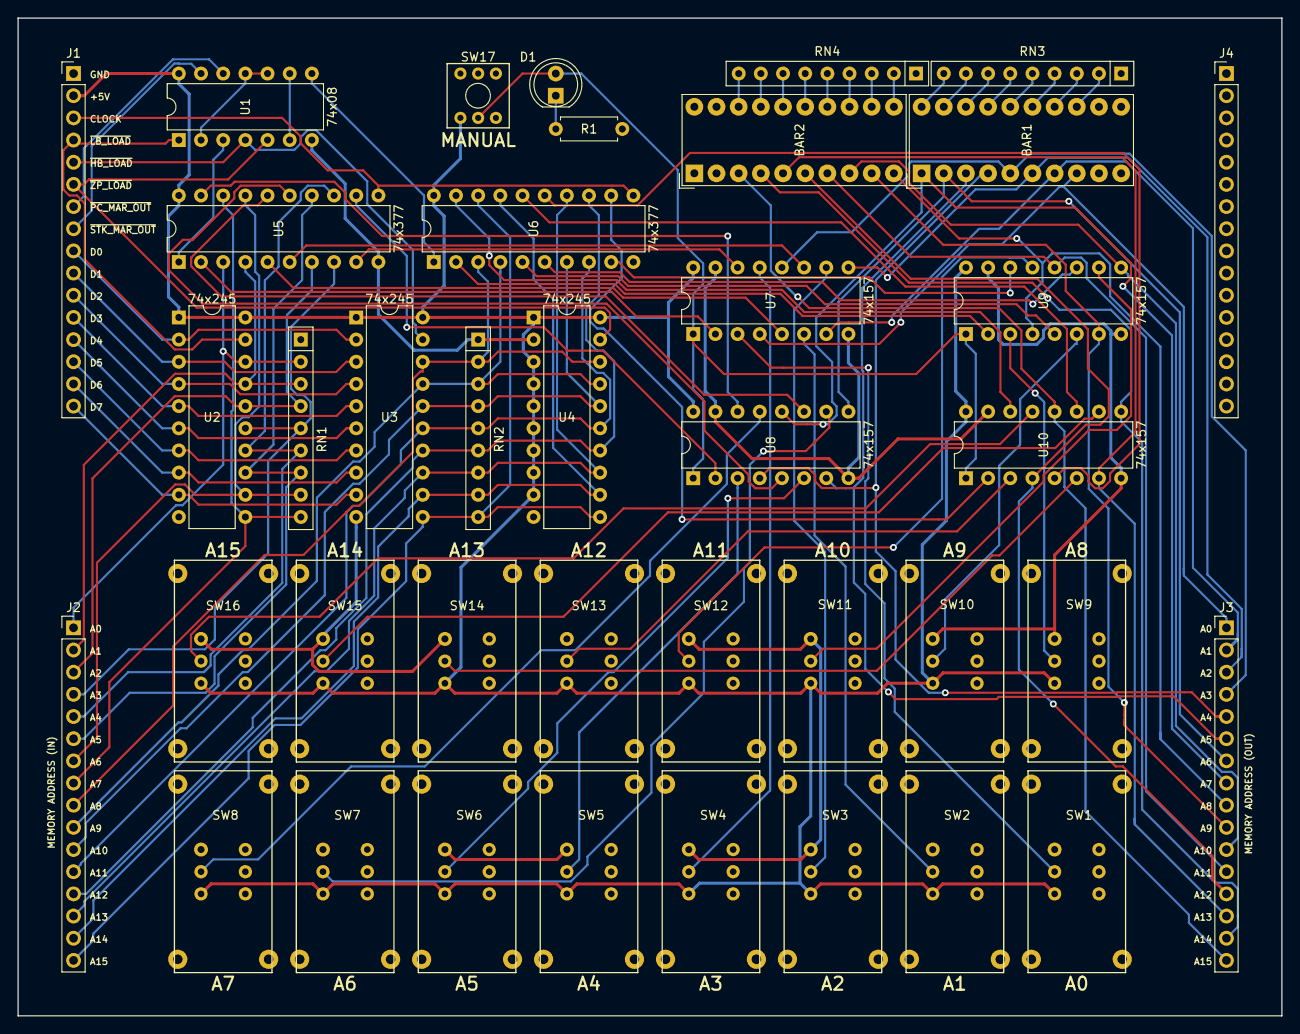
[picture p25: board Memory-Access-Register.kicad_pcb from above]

Board: 2 copper layers, 144.8 x 114.3 mm, 39 parts (0 on the bottom side), 102 nets.

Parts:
BAR1, BAR2: HDSP-4830_2; HDSP-4830
D1: LED; LED_D5.0mm
J1, J2, J3, J4: Conn_01x16_Male; PinHeader_1x16_P2.54mm_Vertical
R1: 470; R_Axial_DIN0207_L6.3mm_D2.5mm_P7.62mm_Horizontal
RN1, RN2: 10K; R_Array_SIP9
RN3, RN4: 470; R_Array_SIP9
SW1, SW2, SW3, SW4, SW5, SW6, SW7, SW8, SW9, SW10, SW11, SW12, SW13, SW14, SW15, SW16: SW_DPDT_x2; FlipSwitch
SW17: SW_DPDT_x2; Switch
U1: 74x08; DIP-14_W7.62mm
U2, U3, U4: 74x245; DIP-20_W7.62mm
U5, U6: 74x377; DIP-20_W7.62mm
U7, U8, U9, U10: 74x157; DIP-16_W7.62mm

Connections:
+5V: J1.2, SW1.3, SW2.3, SW3.3, SW4.3, SW5.3, SW6.3, SW7.3, SW8.3, SW9.3, SW10.3, SW11.3, SW12.3, SW13.3, SW14.3, SW15.3, SW16.3, SW17.3, U1.14, U2.1, U2.20, U3.1, U3.20, U4.1, U4.3, U4.4, U4.5, U4.6, U4.7, U4.8, U4.9, U4.20, U5.20, U6.20, U7.16, U8.16, U9.16, U10.16
CLOCK: J1.3, U5.11, U6.11
DATA_BUS0: J1.9, U2.2, U3.2
DATA_BUS1: J1.10, U2.3, U3.3
DATA_BUS2: J1.11, U2.4, U3.4
DATA_BUS3: J1.12, U2.5, U3.5
DATA_BUS4: J1.13, U2.6, U3.6
DATA_BUS5: J1.14, U2.7, U3.7
DATA_BUS6: J1.15, U2.8, U3.8
DATA_BUS7: J1.16, U2.9, U3.9
GND: J1.1, R1.1, RN1.1, RN2.1, RN3.1, RN4.1, SW1.1, SW2.1, SW3.1, SW4.1, SW5.1, SW6.1, SW7.1, SW8.1, SW9.1, SW10.1, SW11.1, SW12.1, SW13.1, SW14.1, SW15.1, SW16.1, SW17.1, U1.7, U2.10, U3.10, U4.2, U4.10, U5.10, U6.10, U7.8, U7.15, U8.8, U8.15, U9.8, U9.15, U10.8, U10.15
MANUAL_A0: SW1.2, U7.3
MANUAL_A1: SW2.2, U7.6
MANUAL_A2: SW3.2, U7.10
MANUAL_A3: SW4.2, U7.13
MANUAL_A4: SW5.2, U8.3
MANUAL_A5: SW6.2, U8.6
MANUAL_A6: SW7.2, U8.10
MANUAL_A7: SW8.2, U8.13
MANUAL_A8: SW9.2, U9.3
MANUAL_A9: SW10.2, U9.6
MANUAL_A10: SW11.2, U9.10
MANUAL_A11: SW12.2, U9.13
MANUAL_A12: SW13.2, U10.3
MANUAL_A13: SW14.2, U10.6
MANUAL_A14: SW15.2, U10.10
MANUAL_A15: SW16.2, U10.13
MANUAL_INPUT: D1.2, SW17.2, U7.1, U8.1, U9.1, U10.1
unnamed: BAR1.1, J3.8, U8.12
unnamed: BAR1.2, J3.7, U8.9
unnamed: BAR1.3, J3.6, U8.7
unnamed: BAR1.4, J3.5, U8.4
unnamed: BAR1.5, J3.4, U7.12
unnamed: BAR1.6, J3.3, U7.9
unnamed: BAR1.7, J3.2, U7.7
unnamed: BAR1.8, J3.1, U7.4
unnamed: BAR1.13, RN3.2
unnamed: BAR1.14, RN3.3
unnamed: BAR1.15, RN3.4
unnamed: BAR1.16, RN3.5
unnamed: BAR1.17, RN3.6
unnamed: BAR1.18, RN3.7
unnamed: BAR1.19, RN3.8
unnamed: BAR1.20, RN3.9
unnamed: BAR2.3, J3.16, U10.12
unnamed: BAR2.4, J3.15, U10.9
unnamed: BAR2.5, J3.14, U10.7
unnamed: BAR2.6, J3.13, U10.4
unnamed: BAR2.7, J3.12, U9.12
unnamed: BAR2.8, J3.11, U9.9
unnamed: BAR2.9, J3.10, U9.7
unnamed: BAR2.10, J3.9, U9.4
unnamed: BAR2.11, RN4.2
unnamed: BAR2.12, RN4.3
unnamed: BAR2.13, RN4.4
unnamed: BAR2.14, RN4.5
unnamed: BAR2.15, RN4.6
unnamed: BAR2.16, RN4.7
unnamed: BAR2.17, RN4.8
unnamed: BAR2.18, RN4.9
unnamed: D1.1, R1.2
unnamed: J2.1, RN1.2, U2.18, U5.3
unnamed: J2.2, RN1.3, U2.17, U5.4
unnamed: J2.3, RN1.4, U2.16, U5.7
unnamed: J2.4, RN1.5, U2.15, U5.8
unnamed: J2.5, RN1.6, U2.14, U5.13
unnamed: J2.6, RN1.7, U2.13, U5.14
unnamed: J2.7, RN1.8, U2.12, U5.17
unnamed: J2.8, RN1.9, U2.11, U5.18
unnamed: J2.9, RN2.2, U3.18, U4.18, U6.3
unnamed: J2.10, RN2.3, U3.17, U4.17, U6.4
unnamed: J2.11, RN2.4, U3.16, U4.16, U6.7
unnamed: J2.12, RN2.5, U3.15, U4.15, U6.8
unnamed: J2.13, RN2.6, U3.14, U4.14, U6.13
unnamed: J2.14, RN2.7, U3.13, U4.13, U6.14
unnamed: J2.15, RN2.8, U3.12, U4.12, U6.17
unnamed: J2.16, RN2.9, U3.11, U4.11, U6.18
unnamed: U1.6, U1.9
unnamed: U1.2, U1.10, U1.11
unnamed: U5.2, U7.2
unnamed: U5.5, U7.5
unnamed: U5.6, U7.11
unnamed: U5.9, U7.14
unnamed: U5.12, U8.2
unnamed: U5.15, U8.5
unnamed: U5.16, U8.11
unnamed: U5.19, U8.14
unnamed: U6.2, U9.2
unnamed: U6.5, U9.5
unnamed: U6.6, U9.11
unnamed: U6.9, U9.14
unnamed: U6.12, U10.2
unnamed: U6.15, U10.5
unnamed: U6.16, U10.11
unnamed: U6.19, U10.14
~HB_LOAD: J1.5, U1.4, U3.19
~HIGH_LOAD: U1.8, U6.1
~LB_LOAD: J1.4, U1.1, U2.19
~LOW_LOAD: U1.3, U5.1
~PC_MAR_OUT: J1.7, U1.12
~STK_MAR_OUT: J1.8, U1.13
~ZP_LOAD: J1.6, U1.5, U4.19

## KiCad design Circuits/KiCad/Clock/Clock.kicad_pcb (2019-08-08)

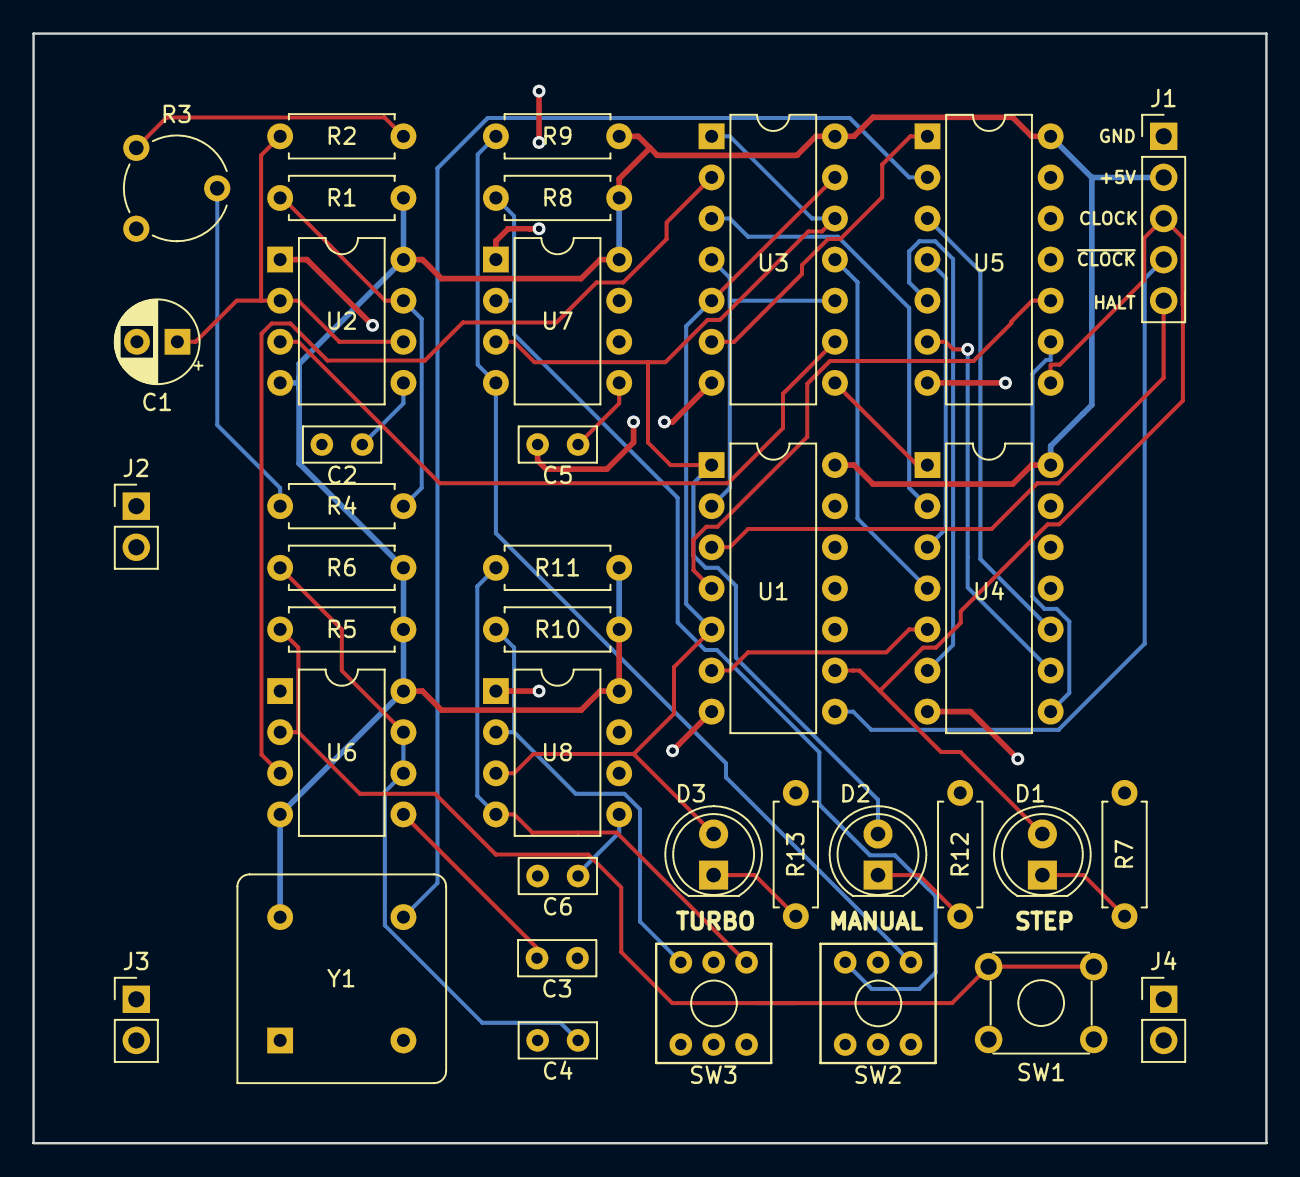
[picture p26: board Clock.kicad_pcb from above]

Board: 2 copper layers, 76.2 x 68.6 mm, 38 parts (0 on the bottom side), 39 nets.

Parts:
C1: 1uF; CP_Radial_D5.0mm_P2.50mm
C2, C3, C5, C6: 10nF; C_Rect_L4.6mm_W2.0mm_P2.50mm_MKS02_FKP02
C4: 100nF; C_Rect_L4.6mm_W2.0mm_P2.50mm_MKS02_FKP02
D1, D2, D3: LED; LED_D5.0mm
J1: Conn_01x05_Male; PinHeader_1x05_P2.54mm_Vertical
J2, J3, J4: Conn_01x02_Male; PinHeader_1x02_P2.54mm_Vertical
R1, R4, R5, R8, R9, R10, R11: 1K; R_Axial_DIN0207_L6.3mm_D2.5mm_P7.62mm_Horizontal
R2: 47K; R_Axial_DIN0207_L6.3mm_D2.5mm_P7.62mm_Horizontal
R3: 1M; Potentiometer_Piher_PT-6-V_Vertical
R6: 1M; R_Axial_DIN0207_L6.3mm_D2.5mm_P7.62mm_Horizontal
R7, R12, R13: 330; R_Axial_DIN0207_L6.3mm_D2.5mm_P7.62mm_Horizontal
SW1: SW_Push; SW_6mm_Tact
SW2, SW3: SW_Push_SPDT; Switch
U1: 74x04; DIP-14_W7.62mm
U2, U6, U7, U8: 555; DIP-8_W7.62mm
U3, U5: 74x08; DIP-14_W7.62mm
U4: 74x32; DIP-14_W7.62mm
Y1: 1 MHz; Oscillator_DIP-8_v2

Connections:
+5V: J1.2, R1.2, R5.2, R6.1, R8.2, R9.2, R10.2, R11.2, U1.14, U2.4, U2.8, U3.14, U4.14, U5.14, U6.4, U6.8, U7.8, U8.8, Y1.1
CLK_HLT: J1.5, U1.3
CLK_MAN: U3.2, U6.3
CLK_MAN_EN: D2.2, U1.1, U3.1, U3.12, U7.3
CLK_TURBO: U5.2, Y1.3
CLK_TURBO_EN: D3.2, U1.5, U3.5, U3.13, U8.3
CLK_VAR: U2.3, U3.9
CLOCK: D1.2, J1.3, U1.9, U5.8
GND: C1.2, C2.2, C3.2, C4.2, C5.2, C6.2, J1.1, R7.2, R12.2, R13.2, SW1.1, SW2.2, SW3.2, U1.7, U2.1, U3.7, U4.7, U5.7, U6.1, U7.1, U7.6, U8.1, U8.6, Y1.2
unnamed: C1.1, R2.1, U2.2, U2.6
unnamed: C2.1, U2.5
unnamed: C3.1, U6.5
unnamed: C4.1, R6.2, U6.6, U6.7
unnamed: C5.1, U7.5
unnamed: C6.1, U8.5
unnamed: D1.1, R7.1
unnamed: D2.1, R12.1
unnamed: D3.1, R13.1
unnamed: R1.1, R4.1, U2.7
unnamed: R2.2, R3.3
unnamed: R3.2, R4.2
unnamed: R5.1, SW1.2, U6.2
unnamed: R8.1, SW2.1, U7.2
unnamed: R9.1, SW2.3, U7.4
unnamed: R10.1, SW3.1, U8.2
unnamed: R11.1, SW3.3, U8.4
unnamed: U1.2, U3.4, U3.10
unnamed: U1.4, U5.10
unnamed: U1.6, U4.5
unnamed: U3.3, U4.2
unnamed: U3.6, U5.1
unnamed: U3.8, U4.1
unnamed: U3.11, U4.4
unnamed: U4.3, U5.4
unnamed: U4.6, U5.5
unnamed: U4.8, U5.9
unnamed: U4.9, U5.6
unnamed: U4.10, U5.3
~CLOCK: J1.4, U1.8

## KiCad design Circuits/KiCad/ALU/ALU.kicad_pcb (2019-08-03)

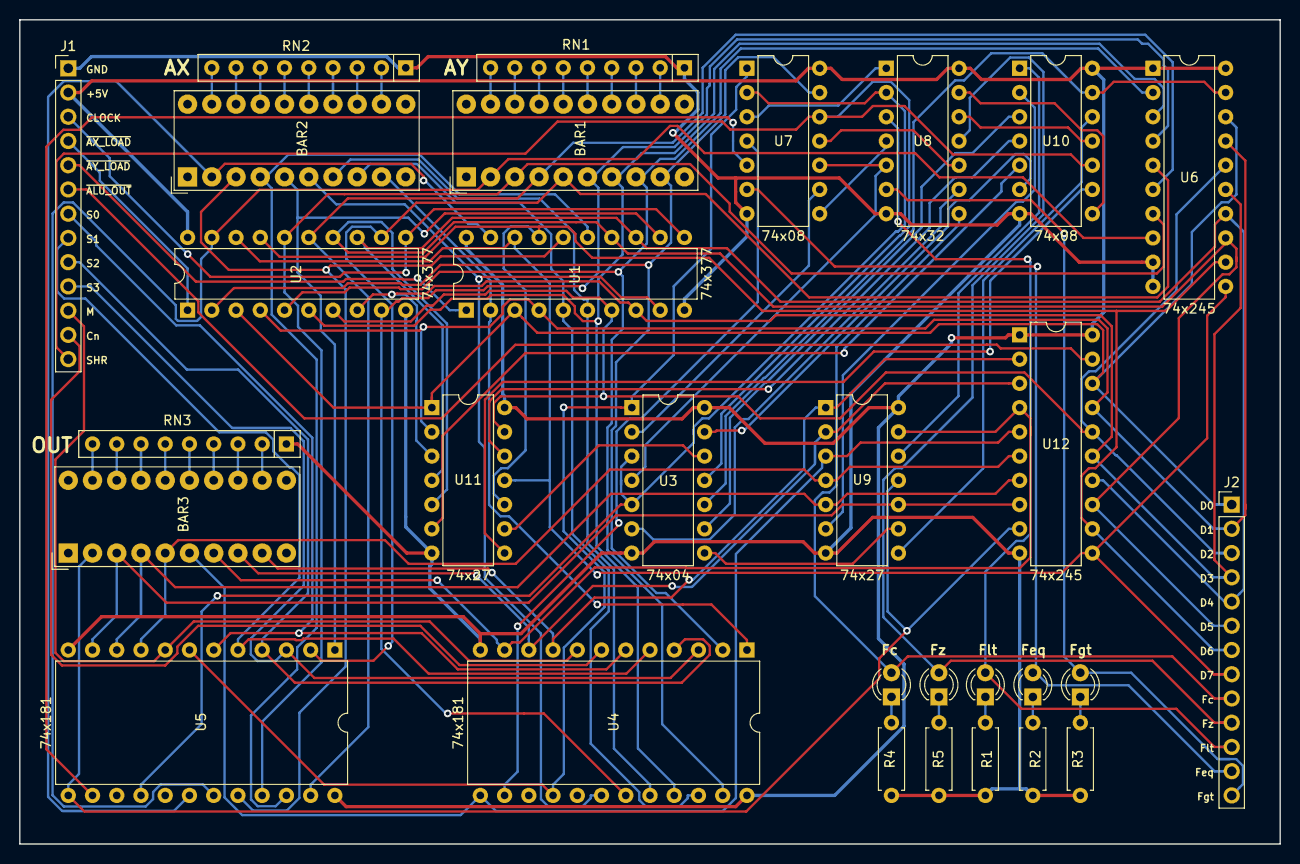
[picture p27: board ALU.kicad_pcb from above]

Board: 2 copper layers, 132.1 x 86.4 mm, 30 parts (0 on the bottom side), 102 nets.

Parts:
BAR1, BAR2, BAR3: HDSP-4830_2; HDSP-4830
D1: Flt; LED_D3.0mm
D2: Feq; LED_D3.0mm
D3: Fgt; LED_D3.0mm
D4: Fc; LED_D3.0mm
D5: Fz; LED_D3.0mm
J1, J2: Conn_01x13_Male; PinHeader_1x13_P2.54mm_Vertical
R1, R2, R3, R4, R5: 470; R_Axial_DIN0207_L6.3mm_D2.5mm_P7.62mm_Horizontal
RN1, RN2, RN3: 470; R_Array_SIP9
U1, U2: 74x377; DIP-20_W7.62mm
U3: 74x04; DIP-14_W7.62mm
U4, U5: 74x181; DIP-24_W15.24mm
U6, U12: 74x245; DIP-20_W7.62mm
U7, U10: 74x08; DIP-14_W7.62mm
U8: 74x32; DIP-14_W7.62mm
U9, U11: 74x27; DIP-14_W7.62mm

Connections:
+5V: J1.2, U1.20, U2.20, U3.14, U4.24, U5.24, U6.1, U6.20, U7.14, U8.14, U9.14, U10.14, U11.14, U12.1, U12.20
/A=B_A: U4.14, U7.4
/A=B_B: U5.14, U7.5
/Cn4_A: U3.1, U4.16, U5.7, U7.1
/Cn4_B: U3.3, U3.5, U5.16, U7.2, U8.2
CLOCK: J1.3, U1.11, U2.11
Cn: J1.12, U4.7
DATA_BUS0: J2.1, U1.3, U2.3, U6.18, U11.1, U12.18
DATA_BUS1: J2.2, U1.4, U2.4, U6.17, U11.2, U12.17
DATA_BUS2: J2.3, U1.7, U2.7, U6.16, U11.13, U12.16
DATA_BUS3: J2.4, U1.8, U2.8, U6.15, U11.3, U12.15
DATA_BUS4: J2.5, U1.13, U2.13, U6.14, U11.4, U12.14
DATA_BUS5: J2.6, U1.14, U2.14, U6.13, U11.5, U12.13
DATA_BUS6: J2.7, U1.17, U2.17, U6.12, U11.10, U12.12
DATA_BUS7: J2.8, U1.18, U2.18, U6.11, U11.11, U12.11
Fc: D4.2, J2.9, U8.8
Feq: D2.2, J2.12, U7.6
Fgt: D3.2, J2.13, U8.6
Flt: D1.2, J2.11, U8.3
Fz: D5.2, J2.10, U8.11
GND: J1.1, R1.1, R2.1, R3.1, R4.1, R5.1, RN1.1, RN2.1, RN3.1, U1.10, U2.10, U3.7, U4.12, U5.12, U6.9, U6.10, U7.7, U8.7, U9.7, U10.7, U11.7, U12.10
M: J1.11, U4.8, U5.8
unnamed: BAR1.2, U2.19, U5.19, U6.8
unnamed: BAR1.3, U2.16, U5.21, U6.7
unnamed: BAR1.4, U2.15, U5.23, U6.6
unnamed: BAR1.5, U2.12, U5.2, U6.5
unnamed: BAR1.6, U2.9, U4.19, U6.4
unnamed: BAR1.7, U2.6, U4.21, U6.3
unnamed: BAR1.8, U2.5, U4.23, U6.2
unnamed: BAR1.12, RN1.2
unnamed: BAR1.13, RN1.3
unnamed: BAR1.14, RN1.4
unnamed: BAR1.15, RN1.5
unnamed: BAR1.16, RN1.6
unnamed: BAR1.17, RN1.7
unnamed: BAR1.18, RN1.8
unnamed: BAR1.19, RN1.9
unnamed: BAR2.2, U1.19, U5.18
unnamed: BAR2.3, U1.16, U5.20
unnamed: BAR2.4, U1.15, U5.22
unnamed: BAR2.5, U1.12, U5.1
unnamed: BAR2.6, U1.9, U4.18
unnamed: BAR2.7, U1.6, U4.20
unnamed: BAR2.8, U1.5, U4.22
unnamed: BAR2.9, U1.2, U4.1
unnamed: BAR2.12, RN2.2
unnamed: BAR2.13, RN2.3
unnamed: BAR2.14, RN2.4
unnamed: BAR2.15, RN2.5
unnamed: BAR2.16, RN2.6
unnamed: BAR2.17, RN2.7
unnamed: BAR2.18, RN2.8
unnamed: BAR2.19, RN2.9
unnamed: BAR3.2, U5.13, U9.11, U12.9
unnamed: BAR3.3, U5.11, U9.10, U12.8
unnamed: BAR3.4, U5.10, U9.5, U12.7
unnamed: BAR3.5, U5.9, U9.4, U12.6
unnamed: BAR3.6, U4.13, U9.3, U12.5
unnamed: BAR3.7, U4.11, U9.13, U12.4
unnamed: BAR3.8, U4.10, U9.2, U12.3
unnamed: BAR3.9, U4.9, U9.1, U12.2
unnamed: BAR3.12, RN3.2
unnamed: BAR3.13, RN3.3
unnamed: BAR3.14, RN3.4
unnamed: BAR3.15, RN3.5
unnamed: BAR3.16, RN3.6
unnamed: BAR3.17, RN3.7
unnamed: BAR3.18, RN3.8
unnamed: BAR3.19, RN3.9
unnamed: D1.1, R1.2
unnamed: D2.1, R2.2
unnamed: D3.1, R3.2
unnamed: D4.1, R4.2
unnamed: D5.1, R5.2
unnamed: U3.2, U7.9
unnamed: U3.4, U7.10, U8.5
unnamed: U3.6, U8.9
unnamed: U3.8, U9.9
unnamed: U7.3, U8.1
unnamed: U7.8, U8.4
unnamed: U7.11, U8.10
unnamed: U9.12, U10.1
unnamed: U9.6, U10.2
unnamed: U3.9, U10.3
unnamed: U10.4, U11.12
unnamed: U10.5, U11.6
unnamed: U3.13, U10.6
unnamed: U10.9, U11.8
unnamed: U8.12, U10.11
unnamed: U9.8, U10.12
unnamed: U3.12, U11.9
S0: J1.7, U4.6, U5.6
S1: J1.8, U4.5, U5.5
S2: J1.9, U4.4, U5.4
S3: J1.10, U4.3, U5.3
SHR: J1.13, U3.11, U7.12, U10.10
SHRc: BAR1.9, U2.2, U4.2, U7.13
SHRz: U8.13, U10.8
~ALU_OUT: J1.6, U12.19
~AX_LOAD: J1.4, U2.1
~AY_LOAD: J1.5, U1.1
~SHR: U3.10, U6.19, U10.13

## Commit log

2018-04-11 Added clock mode toggle logic
    [Clock.sch]
2018-04-12 First revision of Clock module circuit (untested at this point)
    [Clock.sch]
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2018-04-12 Built and tested Clock module
    [Clock.sch]
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2018-04-13 Started work on Program Counter
    [Clock.sch, Program-Counter.sch, Register-Y.kicad_pcb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]
2018-04-14 Just more work in progress...
    [Program-Counter.sch, Register-X.sch, TTL-Computer.sch]
2018-04-15 Removed ROM loader idea from architecture
    [ALU.kicad_pcb, ALU.sch, Clock.sch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]
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2018-04-29 Copied X register to Y register
    [ALU.sch, Clock.sch, Program-Counter.sch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]
2018-04-29 Bit of thinking on the instruction set
    [Instructions_T-States.xlsx]
2018-04-30 Started using Logisim. Testing ALU stuff
    [ALU.sch]
2018-05-01 Did some work on ALU
    [ALU.sch, Clock.sch, Program-Counter.sch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]
2018-05-02 Figured out the truth table for my ALU
    [ALU-Truth_Table.xlsx, ALU.sch, TTL-Computer.sch]
2018-05-03 Added A and B register schematic
    [ALU.sch, Clock.sch, Instructions_T-States.xlsx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]
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2018-05-05 Improved ALU and instructions (ALU now takes data from all registers)
    [ALU.sch, Controller-Sequencer.sch, Instructions_T-States.xlsx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]
2018-05-05 Renamed registers X and Y to C and D.
    ALU now has its own internal accumulator register.
    [ALU.sch, Controller-Sequencer.sch, Program-Counter.sch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]
2018-05-11 Updated folder structure and working out the memory module
    [ALU.kicad_pcb, ALU.sch, Clock.sch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]
2018-05-14 Completed memory circuit diagram (untested)
    [ALU.sch, Clock.sch, Controller-Sequencer.sch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]
2018-05-14 Added Stack Pointer schematic (untested)
    [ALU.sch, Clock.sch, Controller-Sequencer.sch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]
2018-05-15 Added empty MAR module schematic
    [ALU.sch, Clock.sch, Controller-Sequencer.sch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]
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2019-03-13 Fixed 74ls377 symbol
    [ALU.sch, Clock.sch, Controller-Sequencer.sch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]
2019-03-13 Added 29C040 ROM component for controller-sequencer module
    [Controller-Sequencer.sch, Instructions_T-States.xlsx]
2019-03-13 Work in progress on controller/sequencer
    [ALU.sch, Clock.sch, Controller-Sequencer.sch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]
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2019-03-18 Working out logic for controller/sequencer in Logisim
    [Controller-Sequencer_Timing.xlsx]
2019-03-24 Implemented program counter in Logisim
    [Controller-Sequencer.sch, _saved_Controller-Sequencer.sch]
2019-03-25 Created ALU in Logisim
    [ALU-Truth_Table.xlsx, ALU.sch, Clock.sch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]
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2019-03-26 Manual control line input is all high-enabled now
    [Controller-Sequencer_Timing.xlsx]
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2019-03-27 First instruction (NOP) is being executed in Logisim
    [Instructions_T-States.xlsx]
2019-03-28 Defined a simple microcode programming language
    [Instructions_T-States.xlsx]
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2019-04-06 First version of Assembler is done
    [Instructions_T-States.xlsx]
2019-04-06 Fixed assembler bug. Flipped ROM_BOOT flag to active low for easier reset.
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2019-04-06 Implemented additional instructions to load data into ALU registers
    [Instructions_T-States.xlsx]
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2019-04-07 Renamed ALU registers and added them to MOV and MVI. Removed MVA instruction.
    [Instructions_T-States.xlsx]
2019-04-07 Small improvement in mcc
    [ALU-Truth_Table.xlsx]
2019-04-07 Implemented AND, OR, XOR, INC, DEC
    [ALU-Truth_Table.xlsx, Instructions_T-States.xlsx]
2019-04-07 Carry can be set and cleared now. Trying to figure out SBC and SHR
    [Instructions_T-States.xlsx]
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2019-04-08 Implemented and tested all jump instructions
    [Instructions_T-States.xlsx]
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2019-04-10 Implement indirect load/store instructions in assembler
    [Instructions.xlsx]
2019-04-10 Added support for string data in assembly. Fixed assembler bugs. Added example Hello World program.
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2019-04-11 Implemented zero page memory
    [Instructions.xlsx]
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2019-04-24 Switched to Linux, so line endings....
    [ALU.sch, Clock.sch, Controller-Sequencer.sch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]
2019-07-24 Revising all KiCad circuits and routing PCB's. Starting with the Clock module.
    [ALU-2019-07-23-14-26-38.sch, ALU.kicad_pcb, ALU.sch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]
2019-07-26 Work in progress on schematics and PCBs
    [Clock.kicad_pcb, Program-Counter.kicad_pcb, Program-Counter.sch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]
2019-07-26 Finished Program Counter schematic & PCB
    [Program-Counter.dsn, Program-Counter.kicad_pcb, Program-Counter_manual-routed.kicad_pcb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]
2019-07-26 Added Stack Pointer schematics & PCB. Rerouted Clock based autorouter output
    [Clock-B.Cu.gbl, Clock-B.Mask.gbs, Clock-B.Paste.gbp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]
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2019-07-27 Updated a few Clock component footprints according to actual measurements
    [Clock.kicad_pcb, Clock.sch]
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2019-07-29 Made sure spacing between headers is always 2.54mm pitch
    [Clock-B.Cu.gbl, Clock-B.Mask.gbs, Clock-B.Paste.gbp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]
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2019-08-02 Moved stack address output control to stack circuit in Logisim
    [ALU.sch, Memory-Access-Register.kicad_pcb, Memory-Access-Register.sch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]
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2019-08-04 First draft of schematic for Memory Access Register
    [Memory-Access-Register.sch]
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2019-08-08 Built Clock circuit on PCB and updated design accordingly. Added footprint for a few exotic components
    [Clock-B.Cu.gbl, Clock-B.Mask.gbs, Clock-B.Paste.gbp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]
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2019-08-11 Rerouted Register PCB and fixed pin header pitch
    [Controller.sch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]
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2019-08-14 Layed out Controller PCB. Started work on Main Board circuit that will connect all modules
    [Controller.kicad_pcb, Main-Board.sch]
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2019-08-28 Added board error to doc
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
